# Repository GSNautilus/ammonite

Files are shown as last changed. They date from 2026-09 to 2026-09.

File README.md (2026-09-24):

<p align="center">
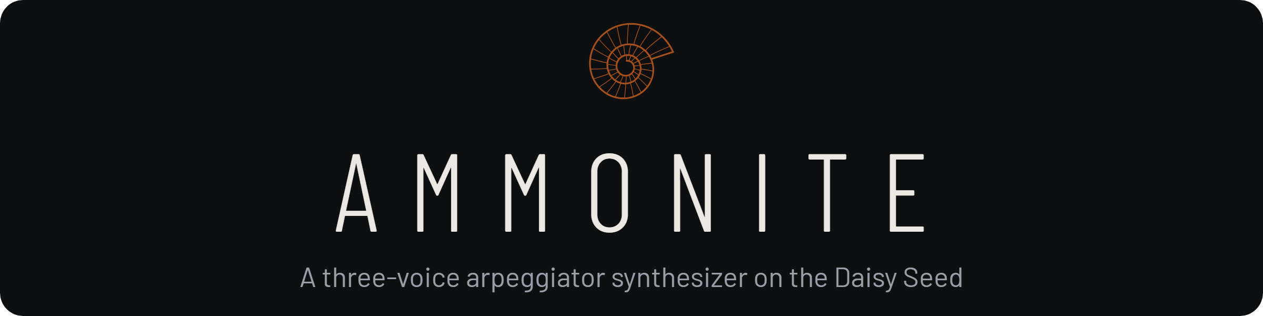
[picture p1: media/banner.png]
Ammonite: a three-voice arpeggiator synthesizer on the Daisy Seed
  
</p>

<p align="center">
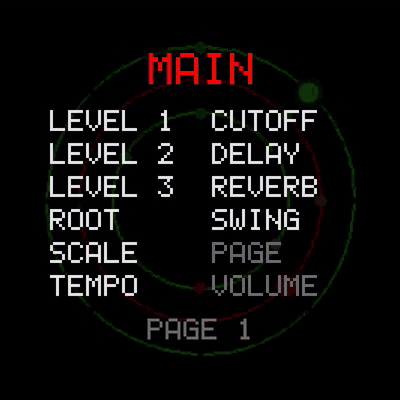
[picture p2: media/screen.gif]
The Ammonite screen playing
  
</p>

<h1 align="center">Ammonite</h1>

<p align="center">
  <b>A three-voice arpeggiator synthesizer on the Daisy Seed</b><br>
  12 knobs &middot; a round screen that draws the music &middot; chords, polyrhythms and echoes in one small box
</p>

<p align="center">
  <a href="https://gsnautilus.github.io/ammonite/"><b>&#9654; Listen: two minutes of Ammonite</b></a><br>
  <a href="https://gsnautilus.github.io/ammonite/#video">Watch the screen play (video with sound)</a> &middot;
  <a href="manual/Ammonite_Manual.pdf">Owner's manual (PDF)</a> &middot;
  <a href="#play-it-in-a-daw-vst3--clap-windows">VST3 / CLAP plugin</a>
</p>

---

Ammonite is three monophonic synth voices, each with its own arpeggiator, envelopes,
filter, five LFOs and stereo echo, all locked to one master clock and one key. You never
pick notes: you pick a key, a chord progression and, for each voice, which notes of the
chord it may play and in what rhythm. Everything it plays is in key, and the three
patterns can run at different lengths and speeds without ever drifting apart.

The round screen shows the three arps as rings: each ring is that voice's real waveform,
cut into its steps, with every note in its own color (the colors follow the circle of
fifths, so a chord has a look as well as a sound).

- **Three voices**, each two detuned oscillators morphing sine / square / saw
- **Three arpeggiators**: 6 modes, 5 note pools, 1-3 octaves, 9 divisions incl. triplets,
  1-16 step patterns, Euclidean density, random note variation, ratchets
- **Harmony**: 10 scales and 10 chord keys, 8 chord progressions, manual chords
- **Per voice**: amp, filter and pitch envelopes, glide, a morphing LP/BP/HP filter,
  15 LFOs in all (pitch, cutoff, amp, pan, shape), a tempo-synced stereo delay
- **Shared**: drive, reverb, swing, four screen views
- **No menus**: nine pages of knobs, one column per voice

## Listen

**[&#9654; Two minutes of Ammonite](https://gsnautilus.github.io/ammonite/)**

That and every clip below play in your browser on the
[listening page](https://gsnautilus.github.io/ammonite/). The recipes are rendered
straight from the synth engine, 40 seconds each; every one is in the
[owner's manual](manual/Ammonite_Manual.pdf), so you can dial it in yourself.

| | |
|---|---|
| [Power-on](https://gsnautilus.github.io/ammonite/#power-on) | what Ammonite plays the moment it has power: three arps in A minor |
| [Slow tide](https://gsnautilus.github.io/ammonite/#tide) | three drones sliding through a progression under a breathing filter |
| [Clockwork](https://gsnautilus.github.io/ammonite/#clockwork) | sixteenth-note patterns of 8, 7 and 5 steps turning against each other |
| [Dub echoes](https://gsnautilus.github.io/ammonite/#dub) | a sparse chord stab into a dark, wobbly ping-pong echo over a sine bass |
| [Late set](https://gsnautilus.github.io/ammonite/#jazz) | a swung ii-V-I in C with a gliding bass |
| [Bells in D](https://gsnautilus.github.io/ammonite/#bells) | Pachelbel's chords played by pitch-swept sine bells |

## The screen

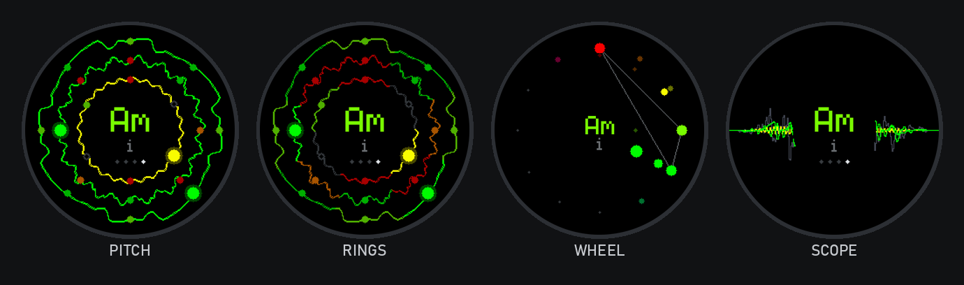
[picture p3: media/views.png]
The four screen views: PITCH, RINGS, WHEEL, SCOPE


Turn a knob and the screen shows what it is and its value; turn the page knob and it
shows what every knob on the new page does:

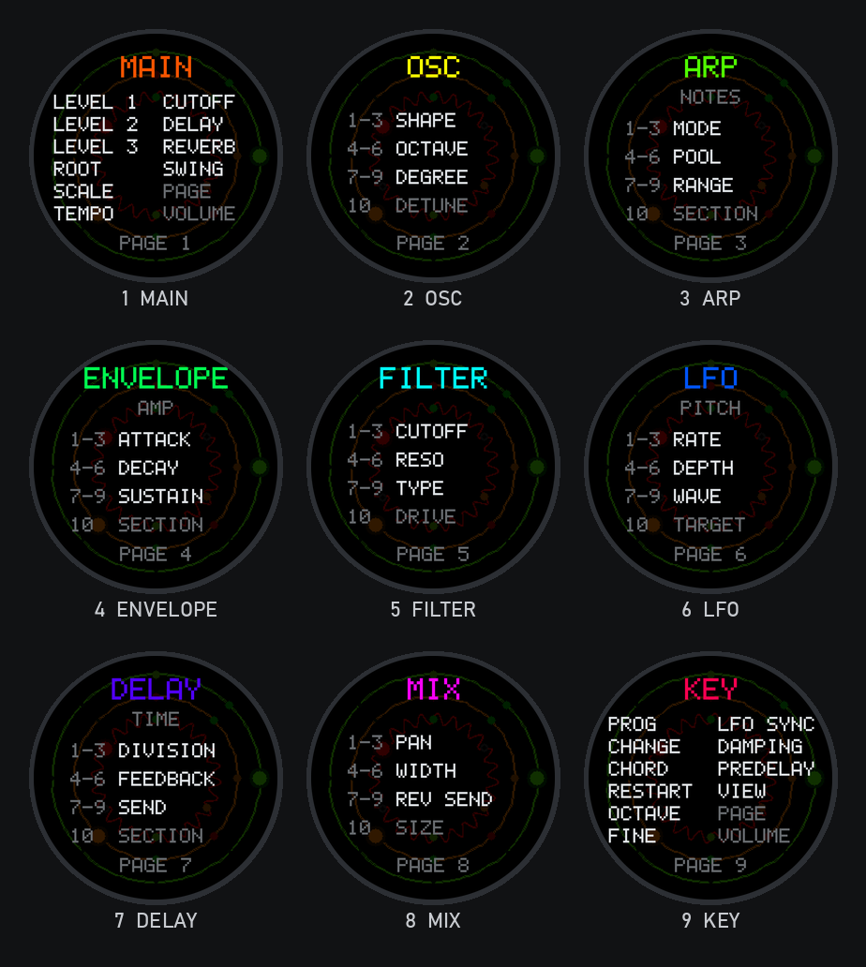
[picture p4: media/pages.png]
The nine page maps


## Hardware

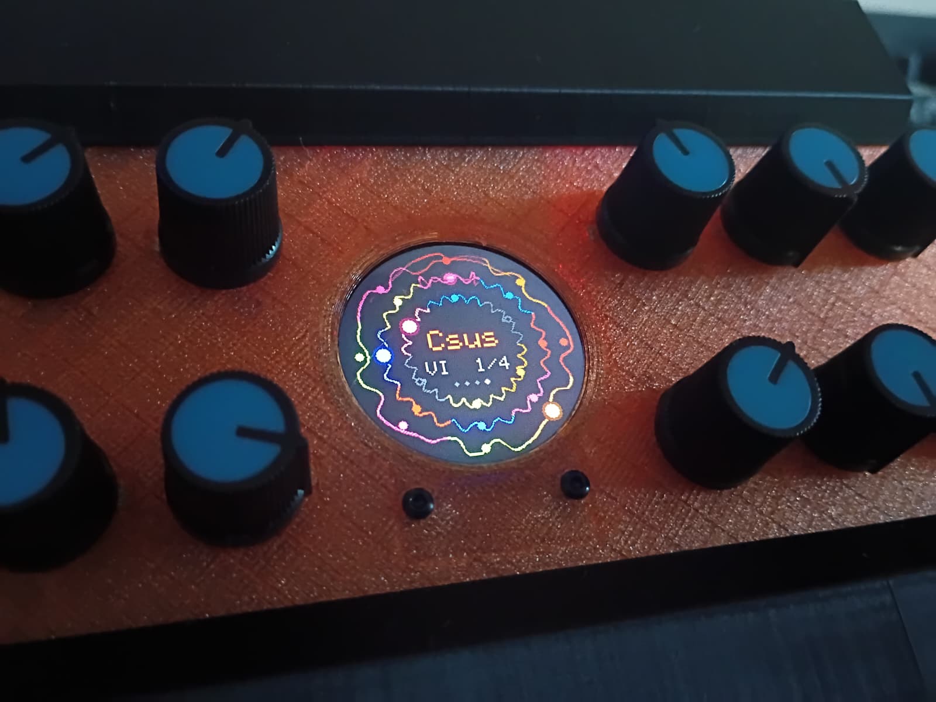
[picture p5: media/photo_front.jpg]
The assembled front panel, the screen playing a Csus chord

<p align="center"><i>The front panel, assembled and playing.</i></p>

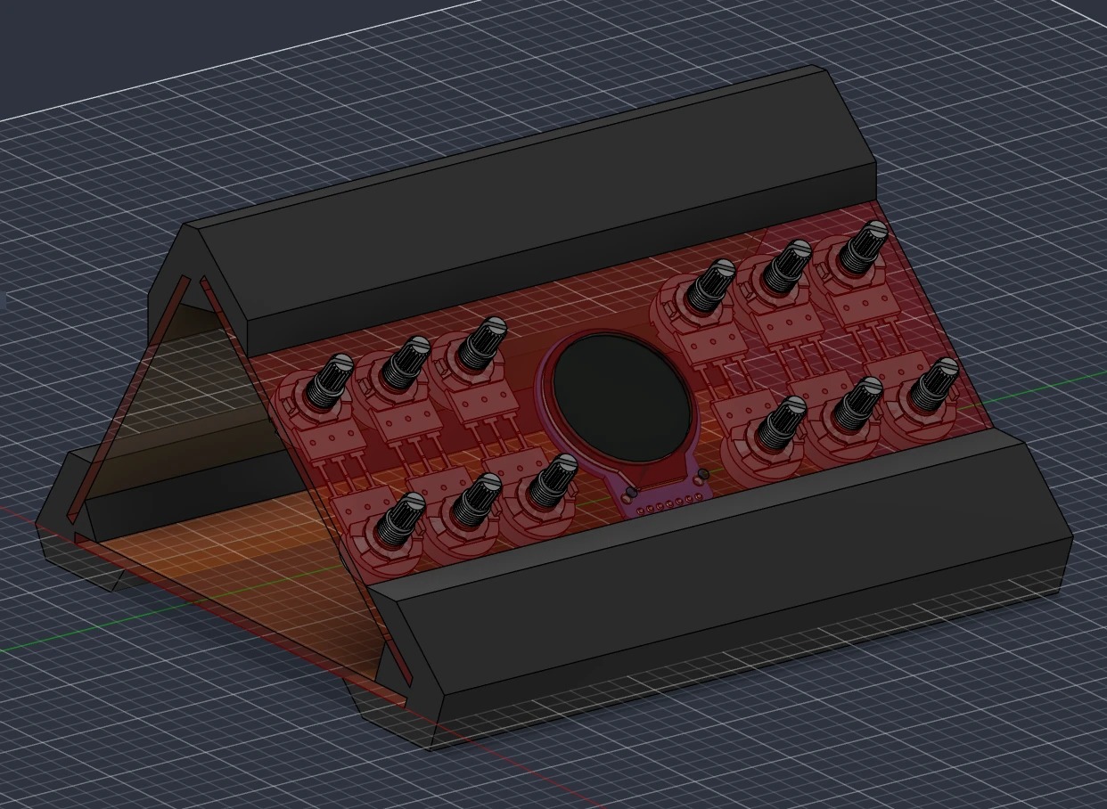
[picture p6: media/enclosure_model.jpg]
The enclosure model: the angled front panel with the twelve pots and the round display

<p align="center"><i>The printed enclosure, version 1.</i></p>

Version 1 of the hardware is simple, and meant to be built with a soldering iron and a
breadboard:

- an Electrosmith **Daisy Seed3**
- a **GC9A01 1.28" round 240x240 display**, 7-pin SPI module
- **12 x WH148 B10K** linear potentiometers (15 mm shaft) with knobs
- a 3.5 mm stereo jack for the output, a breadboard and jumper wire
- a **3D-printed enclosure**: six parts in [`hardware/stl`](hardware/stl)
- USB-C for power and flashing

The wiring is in [`hardware/wiring`](hardware/wiring). A full hardware manual (parts,
printing, assembly, wiring, flashing) is on the [to-do list](#to-do); the enclosure will
keep changing (side panels, a proper home for the jack), so treat this as version 1.

## Getting started

### Flash the firmware

1. Download `ammonite.bin` from the [latest release](../../releases/latest).
2. Put the Seed in bootloader mode: hold **BOOT**, tap **RESET**, release **BOOT**.
3. Open the [Daisy Web Programmer](https://flash.daisy.audio/) in Chrome or Edge, connect,
   choose the file and flash.

### Build from source (Windows)

You need the [Daisy toolchain](https://github.com/electro-smith/DaisyToolchain/releases)
and [Git for Windows](https://gitforwindows.org/). In PowerShell:

```powershell
git clone --recursive https://github.com/GSNautilus/ammonite
cd ammonite
.\ammonite.ps1 libs     # once: builds libDaisy and DaisySP
.\ammonite.ps1 build    # firmware\build\ammonite.bin
.\ammonite.ps1 flash    # build and flash over USB (bootloader mode first)
```

### Try it without hardware

The PC simulator runs the exact same engine and draws the exact same screen, with the
panel's twelve knobs under your mouse. It needs Python 3.11 with the packages in
[`requirements.txt`](requirements.txt):

```powershell
pip install -r requirements.txt
.\simulator.bat
```

(If the right `python` is not on your PATH, set `AMMONITE_PYTHON` to its `python.exe`.)
`.\ammonite.ps1 test` runs the engine's 193 headless checks.

### Play it in a DAW (VST3 / CLAP, Windows)

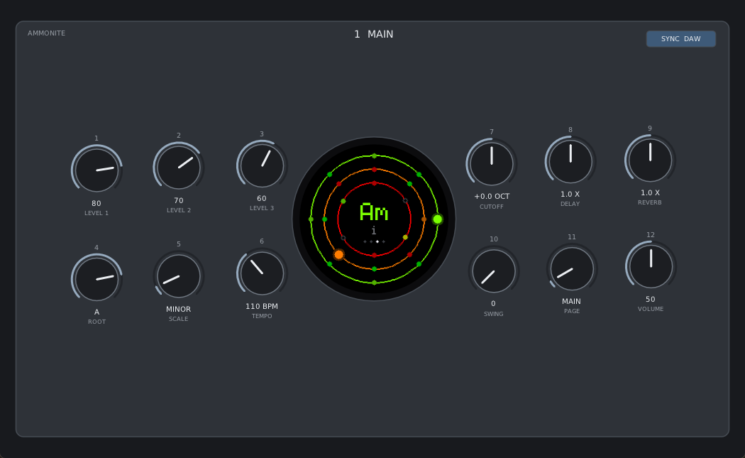
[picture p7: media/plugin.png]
The Ammonite plugin: the panel with its twelve knobs and the round screen


Ammonite is also a plugin for Windows DAWs, with the same engine, panel and screen as
the hardware (its copy of the engine is checked bit for bit against the firmware's).

1. Download `Ammonite-0.2.0-win64.zip` from the [latest release](../../releases/latest)
   and unzip it.
2. Copy the `Ammonite.vst3` folder into `C:\Program Files\Common Files\VST3`, and/or
   `Ammonite.clap` into `C:\Program Files\Common Files\CLAP`.
3. Rescan plugins in your DAW and load Ammonite on an instrument track.

It plays by itself as soon as it is loaded. **SYNC DAW** (the default) follows the
DAW's tempo and bars: patterns and chord progressions line up with the song and follow
the playhead; **SYNC FREE** runs on its own TEMPO knob like the hardware. Every knob of
every page is an automatable parameter, saved with the project; turning a knob on the
panel records automation. Any sample rate from 44.1 to 192 kHz.

Tested in FL Studio 2025. Good to know: Ammonite's bars are always 4/4, and it ignores
MIDI notes, so a DAW's channel mute (which mutes by holding back notes) does not
silence it: mute or turn down its mixer track instead.

To build it yourself you need the Visual Studio 2022 Build Tools (the C++ workload, with
CMake). In PowerShell, from the repository:

```powershell
.\plugin\plugin.ps1 build     # plugin\build\cmake\bin\Ammonite.vst3 and Ammonite.clap
.\plugin\plugin.ps1 install   # copies both into the system plugin folders (run as administrator)
.\plugin\plugin.ps1 test      # the engine and plugin tests
```

## To do

- [ ] **Hardware manual**: parts list, printing, assembly, wiring and flashing, with photos
      of the build
- [ ] **Enclosure v2**: back and side panels with room for the jack and USB
- [ ] **Measure CPU load on the Seed** with every effect running
- [x] **VST3 / CLAP plugin** for Windows, synced to the DAW's tempo (0.2.0)

## Repository

| Folder | |
|---|---|
| `core/` | the synth engine: portable C++14, no hardware code. Everything musical lives here |
| `firmware/` | the thin Daisy shell: knobs in, audio and screen out |
| `sim/` | the PC simulator (Python + the engine as a DLL) |
| `tests/` | headless tests that play the engine and measure what comes out |
| `plugin/` | the VST3 / CLAP plugin (DPF): its copy of the engine, the panel UI, its tests |
| `manual/` | the owner's manual: its screen captures are made by driving the engine |
| `hardware/` | enclosure STLs and wiring diagrams |
| `media/` | everything on this page, rendered by `media/make_media.py` |
| `docs/ENGINE_PLAN.md` | the design and build notes |
| `docs/VST_PLAN.md` | how the plugin was built, decisions and limits |
| `lib/` | libDaisy and DaisySP (git submodules; `plugin/lib/DPF` for the plugin) |

## License

Ammonite is released under the [MIT license](LICENSE).

It builds on Electrosmith's [libDaisy](https://github.com/electro-smith/libDaisy) and
[DaisySP](https://github.com/electro-smith/DaisySP) (MIT). The reverb, `ReverbSc`, comes from
[DaisySP-LGPL](https://github.com/electro-smith/DaisySP-LGPL) and is licensed under the
**LGPL-2.1**; it is linked into the firmware and the simulator, and its full source is
included here as a submodule. The plugin links its own copy of it (`plugin/engine`, with
a larger buffer for high sample rates, source included) and is built with the
[DISTRHO Plugin Framework](https://github.com/DISTRHO/DPF) (ISC).

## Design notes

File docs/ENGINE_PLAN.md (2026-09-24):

# Ammonite — Engine Build Plan

Living design and build notes for Ammonite (developed as `synth_arp`, named
Ammonite on 2026-09-24). Designed in discussion 2026-09-23. It started as a
copy of an earlier drone synth, whose pieces (MorphOsc, envelope, delay loop,
reverb wrapper, pickup) it reuses.

> Paths: this repository was split out of a larger Daisy workspace on
> 2026-09-24. The build history below keeps the old names (`synth_arp\core` is
> now `core\`, `MyProjects_arp` is `firmware\`, `synth_arp\sim` is `sim\`,
> the map file is `firmwareuildmmonite.map`).

## What exists (2026-09-24)

| Piece | Path | Status |
|---|---|---|
| Portable core | `core\` | **build steps 1-7 done** (2026-09-23): all 9 pages and sub-pages, three oscillators with key + chord degree, filters, mix, reverb; master clock, three arps, amp envelopes; chord progression; filter / pitch envelopes + glide; 15 LFOs; per-osc delays; RINGS / PITCH / WHEEL / SCOPE views; fast display SPI (confirmed on hardware). CPU on the Seed still to measure |
| PC simulator | `sim\panel_sim.py` + `synthcore.dll` (`simulator.bat`) | runs; top label = page (and sub-page), captions = function + osc |
| Firmware shell | `firmware\` (`TARGET = ammonite`, builds from `core\`, libs from the `lib\` submodules) | `make` clean, no warnings: flash 90.3 %, SDRAM 7.4 MB (6 delay lines already allocated), `audio.o` at 0x30000000 |
| Tests | `tests\` | `arpsynth.py` helpers, `test_panel.py` (49 checks), `test_voices.py` (22), `test_arp.py` (31), `test_prog.py` (40), `test_env.py` (16), `test_lfo.py` (16), `test_delay.py` (16), `test_screen.py` (12), all pass (193 checks) |
| Hardware | `hardware\stl\`, `hardware\wiring\` | enclosure v1 (six parts), wiring diagrams |
| Manual | `manual\` | owner's manual, A4 PDF. `capture.py` drives the DLL headless (reuses `panel_sim.draw_panel`) for every screen / panel image and plays `recipes.py` through the panel into `recipes.json`; `build.py` prints `ammonite.html` twice with headless Edge (contents page numbers). `msedge.exe` returns before the PDF exists: `build.py` waits for it. Re-run after any change to names, ranges or defaults |
| README media | `media\` | `make_media.py` renders the demo video, GIF, recipe MP3s and images from the engine (and the STLs) |

**The architecture law: every engine feature goes in `core\` only.**
The shells (panel_sim.py, synth_main.cpp) stay thin: controls in, audio and
framebuffer out.

### Workflows (PowerShell, from the repository root)

- Simulator: `.\simulator.bat` (or `.mmonite.ps1 sim`)
- Libraries, once: `.mmonite.ps1 libs`
- Firmware build: `.mmonite.ps1 build`
- Flash: `.mmonite.ps1 flash` (bootloader: hold BOOT, tap RESET, release BOOT)
- Firmware check from Git Bash: `cd firmware && make`
- DLL build: `simuild_dll.ps1` (add new DaisySP .cpp files to its `$sources`)
- Headless screenshot: `SIM_SHOT=<png>` + `SDL_VIDEODRIVER=dummy` on panel_sim.py
- Tests: `.mmonite.ps1 test`, or `python tests	est_x.py`
  (env `SYNTH_DLL=<path>` points them at another DLL, e.g. one built elsewhere
  while a running simulator holds `sim\synthcore.dll` open)
- Python: `$env:AMMONITE_PYTHON` if set, else `python` (packages in `requirements.txt`)
- Manual: `.mmonite.ps1 manual`; README media: `python media\make_media.py`

---

## The instrument (user-decided 2026-09-23)

An **arpeggiator box built on three independent monophonic oscillators**
(OSC 1-3). Each oscillator has its own shape, pitch, arp, envelopes, filter,
LFOs, delay and mix. A shared key (ROOT + SCALE) and an optional chord
PROGRESSION tie them together; one master clock (TEMPO, SWING) drives all
three arps and the chord changes. An oscillator with its arp OFF drones, so
the old drone box is one setting of this one.

Dropped from the reference: CHAOS, SHIMMER (all pitch shifters), TEXTURE
(sub, noise, ensemble), the FREE / NOTES tuning modes.

### Signal flow

```
per OSC n (x3, mono):
  2 detuned MorphOsc (SHAPE, DETUNE)            pitch = key note + PITCH env + LFO + glide
  -> drive (FILTER page DRIVE, shared amount), per oscillator
  -> SVF, LP -> BP -> HP morph (CUTOFF, RESO, TYPE; FILTER env, LFO, master CUTOFF)
     (two SVFs per osc, one per oscillator, so WIDTH can pan them apart)
  -> amp envelope (A, D, S; release = D) x LEVEL x AMP LFO
  -> scope capture (post filter + env, pre pan)  -> screen ring n
  -> pan (PAN + PAN LFO), WIDTH spreads the osc's two oscillators L/R
  -> dry sum
  -> own stereo delay (DIVISION, FEEDBACK, SEND x master DELAY, TONE, WOBBLE, WIDTH)
  -> reverb send = (dry + delay return) x REV SEND x master REVERB
sum of dry + 3 delay returns + ReverbSc (SIZE, DAMPING, PREDELAY)
  -> soft limiter -> VOLUME -> out L/R
```

Modulation per oscillator: 5 LFOs (one per target: PITCH, CUTOFF, AMP, PAN,
SHAPE), a FILTER envelope and a PITCH envelope, all computed on the
**control tick, every 16 samples** (0.33 ms; changed from "once per block"
in step 4, since the sim's 5 ms blocks are too coarse for fast envelopes).
The amp envelope stays **per sample** (steps would click).

### Clock (one master, never three timers)

- One beat position (`beat_`, quarter notes since Init) advances by TEMPO
  every block, so a tempo change never jumps it; a bar is 4 beats.
- Each oscillator's step index is derived from that position and its
  DIVISION, with SWING applied per division (even steps stretched up to a
  third, odd ones shrunk). Polyrhythms therefore stay locked forever.
- Events are sample-accurate inside the block (onset on its sample, gates
  and ratchet hits counted in samples).
- Chord changes and RESTART happen on bar lines of the same counter.

### Harmony

- **ROOT** = the key's tonic, C..B. **SCALE** = one list of 10 scales then
  10 chords (the reference's `kScaleMask` / `kChordMask`, TYPE knob folded in).
- The **current chord** is a scale degree: from the PROGRESSION when PROG is
  on, else from KEY page CHORD (manual, default I).
- Each oscillator's note pool: start at (current chord degree + the osc's
  DEGREE), build the POOL type from the scale (KEY = every scale note,
  TRIAD / 7TH = stacked diatonic thirds, FIFTHS = root + in-key fifth,
  ROOT = octaves only), repeat over RANGE octaves, place at base octave 2
  + the osc's OCTAVE + master OCTAVE.
- **Chord keys** (SCALE set to a chord): POOL KEY = the chord's tones; the
  progression moves the chord's root along its parent scale (natural minor
  for MIN, MIN7, DIM; major otherwise) and keeps the chord quality
  (parallel chords). *Tune by ear once it runs.*
- MODE OFF: the oscillator drones on its pool's first note (its DEGREE on
  the current chord) and follows chord changes with its GLIDE.

---

## Panel

### Conventions

- **Knob 11 = PAGE selector** (stepped, 9 pages, `StepWithHyst`),
  **knob 12 = VOLUME** on every page. Unchanged from the reference.
- **Column = oscillator** on every column page:

  ```
  LEFT GROUP              RIGHT GROUP
  [1 ] [2 ] [3 ]          [7 ] [8 ] [9 ]     row A (1-3), row C (7-9)
  [4 ] [5 ] [6 ]          [10] [PAGE][VOL]   row B (4-6), knob 10
  osc1 osc2 osc3          osc1 osc2 osc3
  ```

  Row A, row B and row C each hold one function for all three oscillators.
- **Knob 10** is either one **shared** function, or the **sub-page
  selector** on ARP, ENVELOPE, LFO and DELAY. Selecting a sub-page never
  changes the sound.
- **Pickup:** every (page, sub-page, knob) slot keeps its own value.
  Changing page **or sub-page** re-arms pickup on knobs 1-9 exactly like a
  page change in the reference (`kPickup` 0.02). Knob 10 as a selector is
  picked up the same way; a jump in the selection is harmless because
  selecting is silent.
- **Per-oscillator functions** hold three values (`params_[func][osc]`), so
  a page row is written once and expanded to the three columns (see "How the
  code holds it"). Stepped values are computed on the audio thread with
  `StepWithHyst`, the screen only reads them (reference rule).
- Names are **<= 8 characters**. The readout shows the function name with
  the sub-page and `OSC n` above it (nothing for a global function).
- MAIN and KEY are **global pages** (no columns): ten independent functions.

### How the code holds it (built in step 1)

- **`enum Func` + `kFuncs[]`** (`synth_core.cpp`): every function once, with
  its name, whether it is per-osc, its step count and step names (or a
  numeric base / sign), and defaults per osc. Values live in
  `params_[func][osc]` (atomic), `smooth_[func][osc]` (audio thread) and
  `step_[func][osc]` (stepped functions, hysteresis on the audio thread; the
  screen only reads them). Global functions use osc 0.
- **`kPages[]`**: per page and sub-page, the (func, osc) each of pots 0-8
  drives (packed `func | osc << 8`; `COLS(a, b, c)` writes a column page's
  three rows), plus knob 10 = a function or `kSubSel`.
- There is no separate slot store: every slot is a distinct (func, osc), so
  a slot's value *is* its param. Pickup state is `potRef_ / picked_`; the
  sub-page per page is `sub_[page]` with its selector reading `subSel_[page]`.
- **Adding a function:** a `Func` entry (the enum and `kFuncs` must stay in
  the same order; `tests/arpsynth.py FUNCS` mirrors it), use it in
  `ProcessAudio`, place it in `kPages`, add a `GetValueText` case if percent
  is not the right unit.
- Core API: `SetPot / GetPot`, `GetPage / GetPageName / GetNumSubs / GetSub /
  GetSubName`, `GetSlotValue / GetSlotName / GetSlotOsc / GetValueText`,
  test hooks `SetEngineParam(func, osc, v)` and `GetOscNote(osc)`. The DLL
  exports them as `synth_*` (`api.cpp`).

### Pages

Ranges and curves follow the reference wherever a function is reused.

**Defaults = a simple start (user 2026-09-23):** power-on is three plain
oscillators and their arps with every effect and modulation off: delay
SENDs, REV SENDs, all LFO DEPTHs, FILTER and PITCH env AMOUNTs, DRIVE and
MIX WIDTH at 0 (the masters MAIN DELAY / REVERB stay at 1x, so raising a
send works at once). On the Seed, the boot page takes its knobs' physical
positions; that is why "off" lives in the per-osc functions on the other
pages, not in the MAIN masters. Checked in `test_voices.py`: nothing rings
on once the notes stop.

**1 MAIN** (global, the power-on performance page)

| Knob | Function | Notes |
|---|---|---|
| 1-3 | LEVEL 1-3 | osc levels, audio taper (p^2). Defaults 0.8 / 0.7 / 0.6 |
| 4 | ROOT | key tonic, stepped 12, C..B (default A) |
| 5 | SCALE | stepped 20: MAJOR MINOR DORIAN PHRYGIAN LYDIAN MIXO "HARM MIN" PENTA "PENTA MI" BLUES, then MAJ MIN SUS2 SUS4 MAJ7 MIN7 DOM7 DIM AUG ADD9 (default MINOR) |
| 6 | TEMPO | 40-240 BPM (default 110) |
| 7 | CUTOFF | master: +-3 octaves on all three cutoffs, centre = as set |
| 8 | DELAY | master: 0-2x all three delay SENDs, centre = as set |
| 9 | REVERB | master: 0-2x all three REV SENDs, centre = as set |
| 10 | SWING | 0-1 (reference behaviour) |

**2 OSC** (columns)

| Row | Function | Notes |
|---|---|---|
| A | SHAPE | MorphOsc: 0 sine, 0.5 square, 1 PolyBLEP saw. Defaults 1 / 0.5 / 0.3 |
| B | OCTAVE | stepped -1..+3 above base octave 2. Defaults 0 / +1 / +2 |
| C | DEGREE | stepped 0..7 scale steps above the current chord root. Defaults 0 / 2 / 4 (all arps OFF = the chord's triad) |
| 10 | DETUNE | shared, 0-20 cents between each osc's two oscillators |

**3 ARP** (columns, knob 10 = sub-page)

| Sub | Row A | Row B | Row C |
|---|---|---|---|
| NOTES | MODE: stepped OFF, LOOP (retrigger, no pitch change), UP, DOWN, UP-DN, RANDOM | POOL: stepped KEY, TRIAD, 7TH, FIFTHS, ROOT | RANGE: stepped 1-3 octaves |
| RHYTHM | DIVISION: stepped 1/1, 1/2, 1/4, 1/4T, 1/8, 1/8T, 1/16, 1/16T, 1/32 | LENGTH: stepped 1-16 steps (the pattern restarts after LENGTH steps: polymeter) | GATE: 0.05-1 of the step |
| CHANCE | DENSITY: how many of the LENGTH steps play, **spread evenly (Euclidean)**, 1 = every step. Deterministic, so a pattern repeats | VARY: chance a played step takes a random pool note | RATCHET: chance a played step splits into 2-4 fast repeats |

Defaults: osc 1 UP, FIFTHS, 1 oct, 1/4, LENGTH 8; osc 2 UP-DN, TRIAD,
2 oct, 1/8, LENGTH 8; osc 3 RANDOM, KEY, 2 oct, 1/16, LENGTH 6, DENSITY
0.6. VARY and RATCHET 0.

**4 ENVELOPE** (columns, knob 10 = sub-page)

| Sub | Row A | Row B | Row C |
|---|---|---|---|
| AMP | ATTACK 1 ms-4 s | DECAY 5 ms-4 s, **also the release time** | SUSTAIN 0-1 |
| FILTER | ATTACK 1 ms-4 s | DECAY 5 ms-4 s (AD, retriggered per note) | AMOUNT bipolar +-4 octaves of CUTOFF |
| PITCH | AMOUNT bipolar +-12 semitones | DECAY 5 ms-1 s (starts at AMOUNT, falls to 0) | GLIDE 0-1 s portamento between arp notes |

Release follows DECAY (user-decided): SUSTAIN 0 = pluck, gate irrelevant;
SUSTAIN 1 = holds for GATE, then fades over DECAY. A new note restarts from
the current level (no click). MODE OFF bypasses the amp envelope (rises at
ATTACK, holds). Defaults: plucks, SUSTAIN 0.4 / 0 / 0, DECAY 400 / 250 /
180 ms, FILTER AMOUNT 0 (was +1.5 oct), PITCH AMOUNT 0, GLIDE 0 / 0 / 0.

**5 FILTER** (columns)

| Row | Function | Notes |
|---|---|---|
| A | CUTOFF | 80 Hz-12 kHz exp |
| B | RESO | 0-0.85 |
| C | TYPE | continuous LP (0) -> BP (0.5) -> HP (1), crossfade of the SVF outputs |
| 10 | DRIVE | shared, pre-filter tanh 1-8x, level-compensated (default 0: clean) |

**6 LFO** (columns, knob 10 = sub-page = target)

Sub-pages PITCH, CUTOFF, AMP, PAN, SHAPE; every one has the same rows, so
each oscillator has **one independent LFO per target** (15 total).

| Row | Function | Notes |
|---|---|---|
| A | RATE | 0.02-20 Hz exp; with LFO SYNC = TEMPO, stepped 4 bars .. 1/16 of the master clock |
| B | DEPTH | 0-1. Full scale: PITCH +-1 semitone, CUTOFF +-3 oct, AMP 100 % dip, PAN full L-R, SHAPE +-0.5 |
| C | WAVE | stepped SINE, TRI, SAW, SQUARE, S&H, DRIFT (smooth random) |

Defaults: depth 0 everywhere (CUTOFF was 0.15 until the simple-start
defaults below; its slow unrelated rates 0.09 / 0.13 / 0.17 Hz remain).

**7 DELAY** (columns, knob 10 = sub-page) — **one stereo delay per oscillator**

| Sub | Row A | Row B | Row C |
|---|---|---|---|
| TIME | DIVISION: stepped 1/32 .. 1/1 incl. T and dotted (reference list minus OFF) | FEEDBACK: 0-1 on the reference's stretched curve | SEND 0-1 |
| COLOR | TONE: loop lowpass 500 Hz-12 kHz | WOBBLE: tape wander 0-3 ms | WIDTH: mono .. ping-pong |

Loop topology, send level and makeup gain from the reference's delay rework
(half-level loop, 20 Hz highpass). Buffers: 6 lines of 6 s (a bar at
40 BPM), 1.15 MB each, SDRAM on the Seed, lent through `synth::Buffers`.
Defaults: 1/8. / 1/4 / 1/8T, feedback 0.4, **send 0** (was 0.2 / 0.35 / 0.3).

**8 MIX** (columns)

| Row | Function | Notes |
|---|---|---|
| A | PAN | defaults 0.5 / 0.3 / 0.7 |
| B | WIDTH | the osc's two oscillators spread L/R, 0 = mono (default 0, was 0.3) |
| C | REV SEND | 0-1 (default 0) |
| 10 | SIZE | reverb size (reference SIZE) |

**9 KEY** (global)

| Knob | Function | Notes |
|---|---|---|
| 1 | PROG | stepped: OFF, POP 1-5-6-4, 50S 1-6-4-5, SAD 6-4-1-5, EPIC 1-6-3-7, JAZZ 2-5-1-1, VAMP 1-4, CANON 1-5-6-3-4-1-4-5, FALL 1-7-6-5 (scale degrees, so each works in any ROOT and SCALE) |
| 2 | CHANGE | stepped 1/2, 1, 2, 4 bars per chord |
| 3 | CHORD | manual chord degree I..VII while PROG is OFF |
| 4 | RESTART | stepped FREE, BAR, CHORD: when all patterns jump back to step 1 |
| 5 | OCTAVE | master -2..+2 |
| 6 | FINE | +-50 cents |
| 7 | LFO SYNC | FREE / TEMPO |
| 8 | DAMPING | reverb (reference) |
| 9 | PREDELAY | reverb (reference) |
| 10 | VIEW | stepped RINGS, PITCH, WHEEL, SCOPE (PITCH added 2026-09-23 on user request, the default since 2026-09-24) |

The progression changes chord on bar lines; a step already sounding
finishes, the next step uses the new chord. ROOT still transposes the whole
progression while it runs.

---

## Screen (user-decided 2026-09-23)

### Color: pitch class in circle-of-fifths order

`hue = ((pc * 7) mod 12) / 12`, pc = pitch class with C = 0. Notes a fifth
apart get neighbouring hues, so a chord's notes cluster (Am = green to
yellow, F = magenta to red, G = orange to teal) and each chord of a
progression gets its own color mood. Replaces the reference's register-based
`PitchColor`.

### VIEW RINGS

- Three concentric rings, **outer = OSC 1** (r 100), OSC 2 (r 78),
  OSC 3 (r 56), each divided into LENGTH arcs starting at 12 o'clock.
- **Each ring is drawn as that oscillator's waveform**, subtly: the captured
  signal (post filter and envelope, pre pan), read phase-locked to the osc's
  own phase so it stands still. Cycles around the ring follow the note's
  frequency (an octave up = twice as many); height follows the envelope
  (up to +-7 px at full level, user-approved height), so rings jump on each
  note and settle.
- **Each arc takes the color of its step's note** (user choice): the current
  step's arc bright (full, 1.6 px), others at ~40 %, skipped steps
  (DENSITY) dark grey.
- Step dots on the ring: current step r 7 with a faint halo, others r 4.5
  at 40 %, skipped = hollow grey, ratchet = split dot.
- Centre: current chord name (e.g. `Am`) large in its root's hue, below it
  the degree numeral and progression position (`vi  3/4`), then 4 beat dots.
- Mockups of rings, wheel and both waveform variants were shown in the
  design session (2026-09-23).

### VIEW PITCH (user request 2026-09-23; the default since 2026-09-24)

The RINGS view with each oscillator's whole wave in **one color**: the
fifths hue of the note that oscillator is on (`oscNote_`), changing as the
arp moves, instead of one color per step arc. The step dots keep their
per-step colors, so the pattern stays readable. `DrawRings(fb, alpha,
oneHue)`.

### VIEW WHEEL

Pitch classes around the circle in fifths order (C at the top); radius =
octave (low inside). Scale notes marked in their hue, current chord's tones
larger and joined into a polygon (its shape shows the chord quality);
each playing note a bright disc with its osc number beside it, previous
notes as a short fading trail. Chord name in the centre.

### VIEW SCOPE

The reference's scope: three overlaid traces, now colored by the fifths hue.

### Overlays (every view)

- **Readout** when a knob moves: name, `OSC n` / `SHARED`, gauge, value
  text; fades after ~2.5 s (reference timing).
- **Page map** when PAGE turns. Column pages list their rows, which reads
  better on a round screen than a 3x3 name grid:
  `1-3 SHAPE / 4-6 OCTAVE / 7-9 DEGREE / 10 DETUNE`. Global pages (MAIN,
  KEY) keep the reference's two-column map.
- **Sub map** when knob 10 turns on a sub-page: the page name, every
  sub-page listed with the current one highlighted and a dot on the ones in
  use (LFO: any DEPTH > 0), then the chosen sub's rows as in the page map.
- Font gains the lowercase glyphs chord names and numerals need
  (`m`, `i`, `v`, `d`, `s`, plus `#` which exists).

### Frame rate

Moving waveforms touch most of the screen, so it stays a full-frame push
(~74 ms, ~13 fps, like the reference scope). Later, with the user at the
hardware: try the SPI prescaler one step faster (~25 MHz) and keep it only
if the panel shows no glitches.

---

## Constraints & landmines (each of these cost real debugging once)

- **C++14 only** in core (firmware toolchain default). No C++17 features.
- Framebuffer stays in **panel byte order** (`canvas.h Color()` handles it);
  the sim un-swaps. Never "fix" the swap.
- Params cross threads: keep the `std::atomic<float>` array + per-block
  smoothing pattern already in `synth_core.cpp`.
- Audio API is interleaved stereo float, `ProcessAudio(out, nframes)`; the
  Daisy callback passes `size/2` frames. Sim block = 256, firmware block = 48.
- **Big DSP buffers**: `ReverbSc` and long `DelayLine`s are hundreds of KB.
  PC: fine as statics inside the DLL. Firmware: they overflow main RAM — the
  established pattern is the shell owning placement: declare
  `static daisysp::ReverbSc DSY_SDRAM_BSS verb;` (and SDRAM delay buffers) in
  `synth_main.cpp` and pass references into `synth::Init(...)` through
  `synth::Buffers`. Add a field there, in `api.cpp` and in `synth_main.cpp`
  together. Verify firmware RAM in the `make` output memory table after
  adding each effect.
- **NEVER put a big buffer in `DMA_BUFFER_MEM_SECTION`.** That section is
  the start of RAM_D2 and libDaisy's MPU makes only its first 32 KB
  non-cacheable. The 115 KB display framebuffer placed there (copied from
  04_hue) pushed libDaisy's audio DMA buffers (`audio.o .sram1_bss`) past
  32 KB into cacheable RAM -> the codec played stale-cache garbage: loud,
  garbled, even for a pure sine, knobs still "doing something". Screen fine,
  ADC fine, CPU 38 %, SDRAM OK. Found via `build/synth.map` (2026-09-21).
  The display uses blocking SPI, so the framebuffer lives in plain `.bss`.
  Check the map after adding any large static: `audio.o` must be at
  0x30000000..0x30007FFF (`build/synth_arp.map` here).
- **SEED3 GROUNDS ARE NOT BONDED.** AGND (pin 20) and DGND (pin 40) must be
  jumpered together externally (Seed3 datasheet v2.1 p.12, fig 1.5). Without
  it the ADC reference floats: all 12 channels read ~100 with random dips to
  70-80, a grounded pin still reads 100, even the DAC loopback self-test
  fails. Cost a full evening on 2026-09-21.
- **Wiring (all 12 pots confirmed on hardware 2026-09-21).** Seed3 physical
  pins: pin 1 = square pad beside USB-C, 1–20 up one side, 21–40 down the
  other. Knob k (panel order) -> ADC A(k-1): A0..A10 on pins 22..32, A11 on
  pin **35** (33/34 are D26/D27, no ADC). Pot ends: +3V3A pin 21 and AGND
  pin 20. Bottom rows are mounted upside down: firmware inverts pots 4-6 and
  10-12 (`kPotInvert` in `synth_main.cpp`). Display: VCC 38 (3V3D), GND 40,
  SCL 9, SDA 11, DC 7, CS 8, RST 6. Audio: OUT L 18, OUT R 19, AGND 20.
  VIN (39) is input-only and dead on USB power - never use it as a supply.
- **Flash is the tight budget** (128 KB internal). Watch the `make` table
  after every step and `arm-none-eabi-nm --size-sort -S -C
  build/synth_arp.elf | tail` for the big symbols. Paid for once: the
  compiler inlined the `canvas.h` text helpers into every call site
  (RenderScreen 7.7 KB) - they are `SYNTHUI_NOINLINE` now; and one
  `fmod(double)` pulled in ~0.8 KB of libm (use `x - floor(x / m) * m`).
  Since step 7 the whole screen section of `synth_core.cpp` is compiled
  `-Os` via `#pragma GCC push_options / optimize("Os")` (GCC only; clang
  in the sim ignores it): -5 KB. Keep new UI code inside that section and
  audio code outside it.
- **Zig floods the console with libc++ `-Wnullability-completeness` warnings**
  (~2 min) on a cache miss: zig building its bundled C++ runtime, not our
  code. Once per environment; the next build is ~1 s. Do not kill it.
- **DLL build fails with `lld-link: could not open '...\zig\o\<hash>\*.obj'`**:
  a zig process was killed mid-build. `build_dll.ps1` detects the message and
  retries once with a cache nonce define.
- **DLL build fails with "Permission denied"** when a `panel_sim.py` process
  is still alive. `synth.bat` closes it; otherwise find it with
  `Get-CimInstance Win32_Process | ? CommandLine -like '*panel_sim*'`.
- Flashing is the user's move. Never claim hardware behavior verified
  unless the user reports it.

### Measurement traps (from the reference tests)

- Exact unison with DETUNE 0 cancels the fundamental; use a little detune.
- A sine gated every step has sidebands; use GATE 1 / SUSTAIN 1 for spectra.
- A decorrelated stereo tail beats if L+R is summed first; measure per channel.
- Every helper that switches pages (and now sub-pages) must switch back.
- Onset-based pitch reads misread ~1 frame in 20; count a pitch only when
  it appears twice.
- `setp(pot, v)` must move a pot first if it already sits at `v` (pickup).
- DETUNE splits each osc into two spectral peaks (+-8..10 cents at the
  default): pitch reads need DETUNE 0 (the two start phases are a quarter
  cycle apart, so DETUNE 0 does not cancel).
- Params smooth over 20 ms. Through the panel that is right, but in a test
  the default sends and levels leak ~50 ms into the reverb after Init, and
  the tank rings on at about -33 dB for seconds. So `SetEngineParam` (the
  test hook) also sets the smoothed value: engine-set values apply at once
  and tests can expect digital silence.
- Onset times: the first sample above 30 % of the peak lags the true onset
  by up to half a period plus the attack; measure timing on a high note
  (A5) with a 1 ms attack. Judge grid lock by drift, not by max error.

---

## Build order (each step ends runnable in the sim, tested, firmware `make` clean)

0. **DONE — Setup** (2026-09-23): `synth\` copied to `synth_arp\`,
   `05_synth` to `06_arp` (Makefile paths + TARGET), sim title, .gitignore.
   DLL and firmware both build from the copy (flash 90.1 %).
1. **DONE — Framework + three drone oscillators** (2026-09-23). The core
   was rewritten around `Func` / `kPages` (see "How the code holds it"):
   all 9 pages and 14 sub-pages are placed, every function stores its value
   and shows its value text; CHAOS, SHIMMER (all GrainShifters), TEXTURE and
   the old tests are gone. Sounding: MAIN (LEVEL x3, ROOT, SCALE with the 10
   chords, master CUTOFF and REVERB), OSC, FILTER (with DRIVE and TYPE),
   MIX (PAN, WIDTH, REV SEND, SIZE), and from KEY: CHORD (manual), OCTAVE,
   FINE, DAMPING, PREDELAY (pulled forward from step 2 / 6). The reverb is a
   send / return now (return 0.5 at send 1). `Buffers` already carries the 6
   delay lines (step 6 only has to use them). The screen still shows the
   reference scope, colored by the fifths hue; page map (rows) and sub map
   (rows + sub-page dots) are new. Verified (`test_panel.py`,
   `test_voices.py`): page / sub-page pickup, columns only touch their osc,
   default notes A2 C4 E5 measured within 5 cents, ROOT / SCALE / CHORD
   I-IV-V-VII, a MIN7 chord key and its IV, KEY OCTAVE + FINE measured, HP
   at 1.2 kHz cuts 110 Hz by 37 dB, master CUTOFF -3 oct moves the centroid
   1140 -> 289 Hz, PAN / WIDTH, reverb tail. Firmware `make` clean.
   Hardware not yet heard.
2. **DONE — Clock + ARP + AMP envelope** (2026-09-23). `beat_` (double,
   quarter notes since Init) advances by TEMPO each block; an osc's step
   index = `StepIndex(beat, DIVISION, swing)` (even steps d(1+s), odd
   d(1-s), s = SWING / 3), so the three grids share one origin and cannot
   drift. A step starting inside a block is found by comparing the index at
   the block's last sample with `lastStep`, and lands on its exact sample.
   Pattern position = step index mod LENGTH; DENSITY hits = round(DENSITY x
   LENGTH), step plays if `(pos * hits) % LENGTH < hits` (Euclidean, starts
   on a hit; readout "3/8"). Pool (`BuildPool`): POOL type from DEGREE on
   the current chord over RANGE octaves; FIFTHS uses `KeyFifth` (key note
   nearest a perfect fifth). LOOP retriggers the pool's first note. VARY
   swaps a played step for a random pool note; RATCHET splits a played step
   into 2-4 even hits of the same note, each with GATE of its share. Per osc
   rng (xorshift). Arp notes jump on their onset sample (GLIDE is step 4);
   drones glide 80 ms. Amp envelope per sample after the filter: linear
   attack, exponential decay to SUSTAIN, release at the decay rate, restart
   from the current level; an arp voice rests silent (release stage) until
   its first hit, and a drone switched to an arp fades at DECAY until the
   next step. Verified (`test_arp.py`, 31 checks): 1/8 @ 120 = 250.0 ms,
   @ 60 = 500.0, 1/16 = 125.0, 1/4T = 333.4; 1/4T, 1/8T and 1/16 at 137 BPM
   on the shared grid for 60 s with < 0.04 ms drift; KEY / TRIAD / 7TH /
   FIFTHS / ROOT pools, RANGE 2, DOWN, UP-DN, RANDOM in pool; LENGTH 5 over
   a 14-note pool repeats every 5; CHORD IV moves the pool to D F A;
   DENSITY 3/8 hits steps 0 3 6 (tresillo), DENSITY 0 silent from sample
   one; GATE duty 0.244 / 0.718; release 100 ms after the gate at 0.108 of
   the held level (DECAY 200 ms, expect ~0.10); SWING 1 = 333 / 167 ms;
   RATCHET 2-4 hits per step; VARY on LOOP; MODE OFF steady; all three
   arpeggiate at power-on. Firmware `make` clean, flash 87.1 %.
   Hardware not yet heard (CPU check pending).
3. **DONE — Progression** (2026-09-23). `kProgs[]` holds the presets as
   scale degrees; `ChordAt(beat)` = PROG's degree at floor(beat / CHANGE)
   mod its length (counted from beat 0, so changes fall on bar lines), or
   KEY CHORD when PROG is OFF. The block computes the chord *now* (drones,
   screen), but an arp step builds its pool on `ChordAt(its own start)`,
   so a step starting exactly on a bar line already plays the new chord
   (`kBeatEps` keeps float rounding from putting it in the old one; checked
   at 1/16T, whose 24th step is the bar line). RESTART: the pattern
   position counts steps from `RestartBeat()` = 0 (FREE), the last bar line
   (BAR) or the last CHANGE boundary (CHORD; with PROG OFF it restarts every
   CHANGE anyway, since manual chord moves have no grid). The screen centre
   shows the chord name in its root's fifths hue (`GetChordName`: root +
   quality: "", m, dim, + or sus from the triad on a scale key, the chord
   type's suffix on a chord key), the numeral (`GetChordNumeral`, lowercase
   when minor), the progression position ("3/4") and 4 beat dots, on a
   black disc over the scope; it fades in as the readout fades out. Font
   gained a d i j m s v. Verified (`test_prog.py`, 40 checks): all 8
   presets in C major, A minor and on an A MIN7 chord key (parallel m7
   chords); POP / FALL / EPIC / JAZZ names and numerals (C I, Bdim vii, Am
   vi, Dm ii ...); Dsus4 on a chord key; CHANGE 1/2..4 bars; chord changes
   every 4th quarter step; RESTART FREE / BAR / CHORD sequences; KEY
   readouts; the centre drawn. Flash: `canvas.h` draw helpers are now
   `noinline` (RenderScreen 7.7 -> 5.1 KB), total 87.7 %.
4. **DONE — FILTER and PITCH envelopes + GLIDE** (2026-09-23). The sample
   loop now has a **control tick every kCtrl = 16 samples** (0.33 ms, same
   at the sim's 256 and the Seed's 48): `ControlTick` glides the pitch,
   sets both oscillators' frequency (note + PITCH env) and both SVFs'
   cutoff (CUTOFF + master + FILTER env), then advances the two envelopes.
   The plan said "block rate" for modulation, but a 5 ms sim block is too
   coarse for 5 ms envelopes, and the tick costs little (6 `Svf::SetFreq`
   per tick). A hit (`Strike`) sets the target note (jumping at once when
   GLIDE is 0, so onsets stay sample-exact), kicks the PITCH env to 1 and
   restarts the FILTER env's attack from its current level; the cutoff
   follows on the next tick. FILTER env: linear attack (1 ms..4 s), then
   exponential decay to 0 (5 ms..4 s, 99 % in the shown time), AMOUNT
   +-4 oct; drones never hit, so it rests at 0 for them. PITCH env: starts
   at AMOUNT (whole semitones, +-12) and decays to 0 (5 ms..1 s); ratchet
   hits re-kick it. GLIDE: exponential, 99 % in GLIDE (0..1 s) for arp
   notes; drones glide on chord changes over max(GLIDE, 370 ms) (the old
   80 ms time constant). Verified (`test_env.py`, 16 checks): FILTER
   AMOUNT 0 steady, +4 oct 2.8x brighter at the hit and back by 400 ms,
   -4 oct dark then open, ATTACK 200 ms peaks late, DECAY 1 s vs 50 ms;
   PITCH +12 over 1 s measured +10.0 / +2.4 / +0.2 st at 40 / 350 / 875 ms
   (theory +10 / +2.4 / +0.2), -12 mirrors it, 50 ms settles; GLIDE 0
   jumps, 500 ms reaches +2.1 st of a fifth at 40 ms (theory +2.2); a drone
   slides A2 -> D3 in ~0.37 s and slower with GLIDE 1 s; the pitch env
   leaves drones alone. Flash 88.2 %.
5. **DONE — LFO page** (2026-09-23). 15 LFOs (`lfo_[target][osc]`) on the
   control tick. FREE: phase advances by RATE (0.02..20 Hz); the three
   oscillators start a third of a cycle apart. TEMPO (KEY LFO SYNC): RATE
   picks one of 4 BARS, 2 BARS, 1 BAR, 1/2, 1/4, 1/4T, 1/8, 1/8T, 1/16
   (hysteresis, readout shows the division) and the phase is
   frac(beat / division) of the master clock, so synced LFOs line up with
   the bar and each other. Waves: SINE (the MorphOsc parabola, no trig),
   TRI, SAW (rising), SQUARE, S+H (new random value each cycle), DRIFT
   (smoothstep from the last random value to the next). Destinations, full
   scale at DEPTH 1: PITCH +-1 st (added in `SetPitch`), CUTOFF +-3 oct
   (added to the tick's cutoff), AMP dips to 1 - DEPTH at the wave's bottom
   (never boosts; ramped per sample across the tick), PAN +-0.5 of the
   position (pan gains now per tick), SHAPE +-0.5. Verified (`test_lfo.py`,
   16 checks): PITCH +-1.00 / +-0.50 st at 2 Hz (period 0.500 s); SQUARE
   two levels, SAW rising with one drop per cycle, S+H holding, DRIFT
   smooth, TRI +-1; CUTOFF 285..2021 Hz at 1 Hz; AMP low/high 0.00 and
   0.47 (want 0 and 0.5); PAN -1..+1; SHAPE 3rd harmonic 0.015..0.248; osc
   1's LFO leaves osc 2 alone; SYNC 1/4 square flips on the 1/8 grid
   (within the 10 ms detection window). Flash 89.2 %.
6. **DONE — Delays** (2026-09-23; the reverb landed in step 1). One stereo
   delay per oscillator (`delays_[o]`, lines from `Buffers`, SDRAM on the
   Seed), processed inside the oscillator loop on the osc's own panned
   signal. Time = DIVISION (1/32 .. 1/1, incl. T and dotted) of TEMPO,
   slewed 80 ms in the log domain (snapped on the first block), plus WOBBLE
   (an Ornstein-Uhlenbeck walk per side, 4 s memory, 0.3 s smoothing, up to
   3 ms), ramped per sample. Loop: taps -> TONE one-pole (500 Hz..12 kHz)
   -> 20 Hz DC blocker; lines written at kDelaySend (0.5) through a soft
   clip, the repeats made up 2x. SEND x master DELAY (0..2x) feeds it,
   FEEDBACK on the reference's stretched curve. WIDTH 0 = parallel L / R
   lines (the osc's pan survives in its repeats), 1 = ping-pong (mono in on
   L, L -> R -> L). Dry + repeats go on to the reverb send. Test helper
   `solo()` now also sets master DELAY 0 (a dry voice). Verified
   (`test_delay.py`, 16 checks): first echo at 251 / 501 / 501 / 376 /
   84 ms for 1/8, 1/4, 1/8 @ 60, 1/8., 1/16T (want 250 / 500 / 500 / 375 /
   83); SEND 0.5 -> first echo 0.50 of the hit; loop gain 0.5 -> repeats
   0.50, 0.50; SEND 0 and master 0 silent; master 2x doubles; ping-pong
   echo 1 left, echo 2 right; a hard-left osc's repeats stay left; TONE
   500 Hz third echo 305 Hz centroid vs 2486; WOBBLE spreads the echo
   spacing 0.52 ms (0.01 ms without); osc 2 never reaches osc 1's delay.
   Flash 90.7 %, SDRAM unchanged (lines allocated in step 1).
7. **DONE — Screen views** (2026-09-23). KEY VIEW picks RINGS (default),
   WHEEL or SCOPE; the view dims under the readout and hides under the maps,
   the chord centre (disc now r 48) fades in as the readout fades. The audio
   thread publishes per osc `ringLen_` (0 = drone), `ringPos_`,
   `ringNote_[o][pos]` (MIDI, or rest / unplayed), `ringRatchet_`,
   `oscHz_` (sounding frequency), and `dispKeyMask_ / dispChordMask_`.
   **RINGS** (r 102 / 80 / 58, outer = OSC 1): 256 points round the ring
   (sin / cos table), each point's radius = R + the captured signal at the
   matching phase of one period of the osc's scope ring (period from
   `oscHz_`, aligned on a rising zero crossing), repeated
   round(3 * f / 110) times (3 at A2, 2..24); segments colored per step arc
   (arcs centred on the dots), rests grey, unplayed dark. **Made more
   prominent on user request (2026-09-23, "too subtle")**: the signal is
   divided by LEVEL (`oscLvl_`, so a quiet osc still draws a full ring;
   the envelope still sets the height), 40 px per unit soft-limited to
   +-9 px (was x 20 clamped at +-7), played arcs at 70 % of their hue (was
   40 %), the playing step at 100 % (was 90 %), a 2 px stroke everywhere
   (the user tried 2 px only on the playing arc and went back to 2 px
   always). Rings are 22 px apart, so two +-9 px waves plus the stroke
   never touch. **Readout over the view (user, same day: "dims far too
   much")**: the view keeps 75 % under the readout (was 40 %) and 20 %
   under the page / sub maps (was hidden); the readout's three text lines
   sit on bands darkened in step with its fade (`TextOnDark`). Readout and
   centre chord hand over (text out in the first half of the fade, chord
   in during the second) instead of overlapping. Dots: playing = r 7 +
   r 10 halo, played r 4, ratchet = two r 3, rest hollow, unplayed r 2. A
   drone is one unbroken ring in its note's hue. **WHEEL**: 12 notes in
   fifths order at r 94 (C on top, so hue and position agree); chord tones
   r 6 joined in wheel order (the chord's shape), key notes r 3 dim,
   others r 1; each osc's note a disc (r 7 / 5 / 4 for OSC 1 / 2 / 3) at
   its pitch class, radius 30 + (note - 36) x 56/48 (higher = nearer the
   rim), its previous note dim; chord name + numeral in the middle.
   **SCOPE**: the reference scope. Canvas gained `DrawLine`. The whole
   screen section is compiled `-Os` (`#pragma GCC optimize`): the views
   pushed flash to 94.9 %, `Os` brought RenderScreen 9.4 -> 3.5 KB and
   flash to 89.9 %. Verified (`test_screen.py`, 9 checks, on the rendered
   framebuffer): three rings drawn; osc 1 playing A -> ring hue 0.254
   (A in fifths order 0.250); DENSITY rests grey (saturation 0.14 vs 1.00);
   the playing dot at 45 then 90 deg (LENGTH 8); ring spread larger just
   after a hit than 420 ms later; a drone ring unbroken in A's hue; WHEEL
   lights A C E, not C# F# G#; SCOPE draws.
8. **Defaults + hardware pass** — agent side done 2026-09-23, **the rest
   is the user's**:
   - Power-on levels (sim, 20 s at VOLUME 1): peak 0.60, RMS 0.082, the
     limiter never bends (no sample above 0.8); the three oscillators alone
     with their effects sit at RMS 0.10 / 0.12 / 0.10.
   - CPU, PC estimate: the arp DLL costs 1.22x the reference drone DLL at
     48-frame blocks (1.23x in a worst case: every LFO on, ratchets, 1/16T,
     all delays and sends up). The reference measured 38 % on the Seed
     before its shimmer / chaos / texture pages existed; the Seed also pays
     more than a PC for SDRAM reads, and this concept reads 6 delay lines
     against the reference's 2. So: probably fine, **must be measured**.
   - `DIAG_ADC 1` build still compiles (85.2 %): it shows CPU avg / max per
     audio block on the screen (plus the pot readings).
   - Open, user: listen to the power-on sound and each page; flash
     (`.\daisy.ps1 flash 06_arp`); CPU on the Seed with `DIAG_ADC 1`
     (`MyProjects\06_arp\synth_main.cpp` line 26; max must stay under ~90);
     the faster display below is done.
   - **Faster display (works on the hardware, user confirmed 2026-09-23)**: the screen felt
     slow once the waves were bold; rendering is not the cost (0.04 ms per
     RINGS frame on the PC), the SPI push is (74 ms at 12.5 MHz). SPI1's
     kernel clock was PLL2P = 25 MHz and PS_2 is the smallest prescaler, so
     `synth_main.cpp` `FAST_DISPLAY_SPI 1` switches the SPI1/2/3 mux to
     PLL3P (49.15 MHz, already running for the SAI) with
     `__HAL_RCC_SPI123_CONFIG` - **not** `HAL_RCCEx_PeriphCLKConfig`, which
     would reprogram PLL3 and could stop the audio. SCK 24.6 MHz, ~38 ms
     per frame, ~26 fps. The sim now draws every 38 ms, and the readout's
     frame counts doubled (kIdleStart 66, kFadeFrames 20 = 2.5 s + 0.75 s
     at 26 fps; with FAST_DISPLAY_SPI 0 they would take twice as long).
     If a rewired panel ever shows garbage or flicker, set it to 0.

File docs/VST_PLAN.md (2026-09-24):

# Ammonite VST — handoff and plan

Written 2026-09-24 at the end of the session that published Ammonite
(https://github.com/GSNautilus/ammonite, listening page
https://gsnautilus.github.io/ammonite/). A new session builds the plugin from
here. Read this, then `docs/ENGINE_PLAN.md` ("Constraints & landmines" first).

**Goal:** Ammonite as a **Windows x64 VST3 plugin, plus CLAP**, running the
very same engine as the firmware (`core/`). No AU, no macOS/Linux for now.
The firmware must keep building from the same core.

**Decided with the user (2026-09-24):**

- **The plugin gets its own copy of the engine** in `plugin/engine/`. `core/`,
  the firmware, the simulator and the 193 tests stay exactly as they are
  (tagged `v1.0`, local, not pushed). The copy becomes multi-instance and
  gains the host features; a fix or sound change in one engine has to be
  carried to the other by hand. Reuniting them later means proving the two
  bit-identical first.
- **DAW sync:** a new SYNC parameter DAW / FREE, default DAW. DAW: BPM and
  song position come from the host (`beat_` = host PPQ while playing), so
  pattern step 1 and the progression land on the DAW's bars. FREE: the
  TEMPO knob and its own clock, like the hardware. With the transport
  stopped, DAW mode keeps playing at the host BPM; on play it jumps to the
  host position.
- **UI:** the hardware panel only (12 knobs, page / section label, the round
  screen); every parameter is also in the host's generic list.
- **Sample rates:** native at the host rate up to 192 kHz; the plugin's
  engine sizes its delay lines for 192 kHz. Tests also run at 96 kHz.
- **Identity:** "Ammonite" by "GSNautilus", CLAP ID
  `com.gsnautilus.ammonite`, DPF brand / unique IDs `GSNa` / `Ammo` (the
  VST3 UID derives from them: never change them after release).
  Categories Instrument | Synth | Generator.

---

## Working environment

- Repo: `C:\Users\Nautilus\Projects\ammonite` (the old Daisy workspace copy
  `Projects\Daisy\synth_arp` is retired; do not work there).
- Commands the user runs are **PowerShell**. From the repo root:
  `.\ammonite.ps1 libs | build | flash | sim | test | manual`,
  `.\simulator.bat`. The agent's own shell is Git Bash.
- Python: conda env `codex` (`$env:AMMONITE_PYTHON` points at its python.exe
  for the scripts). `ziglang` builds `sim\synthcore.dll` (`sim\build_dll.ps1`).
- **C++ for the plugin: Visual Studio Build Tools 2022** is installed:
  MSVC 14.39 (`VC\Auxiliary\Build\vcvars64.bat`), CMake and Ninja under
  `C:\Program Files (x86)\Microsoft Visual Studio\2022\BuildTools\Common7\IDE\CommonExtensions\Microsoft\CMake\`,
  Windows SDK 10.0.22621.
- **Hosts to test in:** Ableton Live 12 (trial) and FL Studio 2025. The system
  VST3 folder `C:\Program Files\Common Files\VST3` does not exist yet and
  needs admin rights: installing there is the user's move (or point the DAW
  at a custom plugin folder).
- GitHub CLI: `C:\Users\Nautilus\gh_cli\bin\gh.exe` (authenticated as
  GSNautilus).
- Repo rules: commits use the repo-local no-reply identity already set in
  `.git/config` (keep it). End commit messages with the Co-Authored-By
  trailer. **Never push, tag or release without the user's go-ahead.**
  Never launch multi-agent fan-outs without stating the scale and getting an
  OK first.

## The engine today

- `core/synth_core.h` is the whole interface: `Init(samplerate, Buffers)`,
  `SetPot / GetPot` (12 panel pots, with page / section pickup),
  `GetPage / GetPageName / GetNumSubs / GetSub / GetSubName`,
  `GetSlotValue / GetSlotName / GetSlotOsc / GetValueText`,
  `SetEngineParam(func, osc, v)` (test hook: bypasses the 20 ms smoothing),
  `GetOscNote`, `GetChordName / GetChordNumeral`,
  `ProcessAudio(out, nframes)` (interleaved stereo float, any block size),
  `RenderScreen(fb)` (240x240 RGB565 in **panel byte order**; see
  `sim/panel_sim.py fb_to_surface` for the byteswap).
- `core/api.cpp` wraps it as a C API (`synth_*`) for the simulator DLL; the
  tests (`tests/arpsynth.py`) call that DLL through ctypes.
- **All mutable state is file-level statics in `core/synth_core.cpp`**
  (2395 lines, 128 `static` declarations): one engine per process. A DAW can
  load several instances and run them on different threads at once, so this
  is the first thing to change.
- Threading model (already used by firmware and sim): the UI side writes
  `std::atomic<float> params_[func][osc]`; the audio thread smooths them and
  computes stepped values (`step_`, with hysteresis); the screen only reads.
  The audio thread publishes what the screen needs (ring notes, positions,
  chord). Keep this split in the plugin: DSP on the audio thread, UI and
  `RenderScreen` on the UI thread.
- Functions: `enum Func` + `kFuncs[]` in `synth_core.cpp` (the tests mirror
  the order in `tests/arpsynth.py FUNCS`). Pages: `kPages[]`.
- Big buffers are lent by the shell through `synth::Buffers`: 6 delay lines of
  `kDelayMaxSamples = 288400` (6 s at 48 kHz, a compile-time template size),
  the `ReverbSc`, two pre-delay lines. On the PC they are statics in
  `api.cpp`; on the Seed they sit in SDRAM (`firmware/synth_main.cpp`).
- Timing: `beat_` (quarter notes since Init, a double) advances by TEMPO each
  block; every arp grid, the progression and synced LFOs derive from it.
  `RenderScreen` is **frame-counted** (readout fade = 66 + 20 frames at the
  display's ~26 fps): call it on a ~38 ms timer, not on every repaint.
- Firmware limits: **C++14**, flash **90.26 %** (118300 B of 128 KB). The screen
  section is compiled `-Os` via `#pragma GCC optimize`. Check the `make`
  memory table after every core change.

## Plan

### Step 1: DONE (2026-09-24): the plugin's engine is an instance

- `plugin/engine/` = `core/` v1.0 copied, namespace `ammonite`: all 48
  mutable statics (plus the function-local ones: value / chord text
  buffers, the WHEEL view's note memory, the unit circle) live in
  `Engine::Impl`; the 48 functions that touch them are its members;
  `class Engine` (`engine.h`) forwards the old API one to one. Constant
  tables and pure helpers are unchanged. `core/` is not touched.
- `plugin/engine/api.cpp`: the `synth_*` calls on a default instance plus
  `eng_create / eng_destroy / eng_*(handle, ...)`.
- `.\plugin\plugin.ps1 test` builds `plugin\build\core_ref.dll` (from
  `core/`) and `plugin\build\ammonite_engine.dll` with the simulator's
  compiler and flags, runs the whole hardware suite (`tests\`) against the
  plugin engine, then `plugin	ests	est_engine_copy.py`:
  - MATCH: 40 random scenarios (params, pot moves, page changes, block
    sizes 1..600, 44.1 / 48 kHz, screens interleaved) are bit-identical
    between core/ and the copy, default and created instance. Checked that
    it bites: a one-ULP change of a gain fails audio, one color step fails
    screens.
  - INSTANCES: same input -> same output; different settings, blocks
    alternating -> each equals its own solo run on core/; two engines on
    two threads with a third rendering their screens -> unchanged; a new
    engine after others were destroyed starts clean.

**Found on the way (for step 2):**

- **core/ crashes above ~52 kHz** (fresh start): `ReverbSc`'s fixed
  `aux_[DSY_REVERBSC_MAX_SIZE]` (98936 floats, sized for 48 kHz) is too
  small, `Init` returns early and the first process writes through a null
  delay-line pointer. Worse, a re-`Init` at a higher rate after a working
  one leaves the old lines in place (no crash, wrong reverb). The define is
  unconditional in `reverbsc.h`, so the plugin needs its own copy of
  ReverbSc (LGPL, keep the notice) with a buffer for 192 kHz, and the
  engine must treat a failed `Init` as an error. The hardware (48 kHz) is
  not affected.
- `Init` does not reset the WHEEL view's note memory (a function-level
  static in core/): harmless, but one reason two engines only match
  bit for bit when they have the same history.
- A fresh worktree has no submodules: `git submodule update --init
  --recursive lib/DaisySP` (libDaisy is only needed for the firmware).

### Plugin shell: DONE (2026-09-24), pulled forward (user: "into a DAW first")

A first loadable plugin before the rest of step 2 and the UI of step 3.

- Engine: 44.1-192 kHz (own ReverbSc copy, lines sized for 192 kHz; above
  it no reverb instead of a crash), host API (`FuncName / FuncPerOsc /
  FuncSteps / FuncDefault / FuncPlace / FuncStepText`, smoothed `SetParam`,
  `GetParam`, `ReverbOk`). Still bit-identical to core/ at 48 kHz.
- `plugin/lib/DPF` (submodule), `plugin/src/DistrhoPluginInfo.h` (IDs as
  decided), `plugin/src/AmmonitePlugin.cpp`: one engine per instance, no
  UI (the host's generic parameter list), a MIDI input it ignores, the
  engine's own TEMPO (no DAW sync yet). Flush-to-zero in `run`.
- **168 parameters**, ID = index over (func, osc) in enum Func order, named
  "PAGE SECTION NAME osc" ("ENVELOPE AMP ATTACK 1", "VOLUME"). Continuous:
  0..100; stepped: the step with the panel's names. The host saves them
  with the project (DPF's own state: parameter values only).
- `.\plugin\plugin.ps1 build` (MSVC 14.39 + CMake + Ninja; `cl` forced,
  the Daisy ARM g++ is on PATH; static CRT) ->
  `plugin\build\cmake\bin\Ammonite.vst3` and `Ammonite.clap`.
  `.\plugin\plugin.ps1 install` (admin PowerShell) copies them to
  `C:\Program Files\Common Files\VST3` and `...\CLAP`.
- `plugin/tests/test_clap.py`: a ctypes CLAP host loads the built
  `Ammonite.clap`: descriptor, 168 unique parameters, plays at 48 / 96 /
  192 kHz, same sound as the tested engine DLL (MSVC vs zig, correlation
  1.0000), automation event, two instances side by side, state save / load.
- **FL Studio 2025 (user, 2026-09-24): loads, plays, parameter changes,
  automation and saving the project all work.** Several instances work
  too. Not yet checked: Ableton Live 12 (VST3 only, Live has no CLAP).
- **FL's channel mute does not silence it** (user): FL mutes a generator
  by withholding notes, and Ammonite ignores notes. The Mixer insert's mute
  works. Possible later: an option to play only while a note is held / a
  pattern plays (a design question for the user).

### DAW sync: DONE (2026-09-24)

- New function **SYNC** (FREE / DAW, default DAW) at the end of enum Func
  (plugin only; not on a panel page, like VOLUME it is always there): 169
  parameters now, the old IDs unchanged.
- `Engine::SetHostClock(playing, bpm, beat)` before each ProcessAudio call.
  SYNC DAW with a host clock: the host tempo (clamped 20..999 BPM, the
  delays too); while playing, `beat_` = the host position in quarter notes,
  so a jump (loop, relocate) just changes each osc's step index and the step
  under the playhead starts at once; stopped: runs on at the host tempo.
  FREE, or no host clock (every test of the hardware suite): TEMPO, bit for
  bit as before.
- Plugin: `DISTRHO_PLUGIN_WANT_TIMEPOS 1`; the position is rebuilt from
  DPF's bar / beat / tick (the CLAP wrapper counts bar beats in quarter
  notes, the VST3 one in time-signature beats: `getPluginFormatName()`).
  A host that stops reporting bars keeps its last tempo.
- Limits: Ammonite's bar is 4 quarter notes (bar lines, CHANGE, RESTART
  BAR), so in 3/4, 6/8 ... its bars drift from the DAW's. DPF's VST3 bar
  maths uses an integer quarter-notes-per-bar (7/8 comes out wrong).
- Tests: `plugin/tests/test_sync.py` (engine: host grid within 1 ms, start
  mid-beat, playhead jump, PROG on the DAW's bars, stopped, FREE, delays on
  the host tempo) and the CLAP host in `test_clap.py` (a CLAP transport
  through the built plugin: grid, jump, stop, FREE).
- **FL Studio (user, 2026-09-24): sync works.**
- Other meters are not a design limit: "a bar = 4 quarter notes" is a
  constant in RestartBeat (BAR), kChangeBeats, the LFO "BAR" divisions and
  the screen's beat counter. A bar length (from the host's time signature
  in DAW mode, a METER setting in FREE) would fix it; a song that changes
  signature also needs the host's bar-start position. After the UI.

### Panel UI: first version (2026-09-24)

- `plugin/src/AmmoniteUI.cpp` (DPF, OpenGL + NanoVG): the simulator's
  panel (1400 x 860 coordinates, window 1050 x 645, resizable with the
  aspect kept): 12 knobs around the round screen, the page / section
  header, a SYNC DAW / FREE button.
- The screen is the engine's own `RenderScreen` on a ~38 ms timer (uiIdle),
  RGB565 panel order -> an RGBA texture, masked round. Knob readouts are the
  engine's `GetValueText` (units as on the hardware; TEMPO shows "DAW 120"
  while the host sets the tempo).
- Knobs edit their host parameter (begin / value / end: hosts record
  automation); no pickup with a mouse. Knob 11 = page, knob 10 = section:
  UI state held in the engine (`SetPanelPage`, `ShowPot` for the readout
  and the maps), not host parameters. Drag (Shift: fine), scroll,
  double-click = default.
- DPF direct access: the UI reaches the engine through
  `ammonite::EngineOf(getPluginInstancePointer())`; the parameter table is
  shared (`AmmoniteParams.hpp`).
- `plugin/tests/ui_check.py` (by hand): opens the real UI in a tkinter
  window through `clap.gui`, plays in real time, screenshots
  (`plugin/build/ui_*.png`), drags knobs with posted mouse messages and
  checks the host sees begin / values / end and the new value, page change,
  a stepped knob, the SYNC button. Not in `plugin.ps1 test`: the real mouse
  over the window can disturb it.
- A standalone `Ammonite.exe` (DPF's jack target) was tried and dropped:
  DPF's native audio fallback on Windows needs MinGW, not MSVC.
- Page and section are not saved with the project (the engine keeps them
  while the plugin lives).
- **FL Studio (user): the UI works.** The screen lagged behind the knobs at
  first: Windows starves the idle timer while mouse moves keep coming, and a
  knob change reached the engine only after FL's round trip. Fixed: mouse
  input also advances the screen, and a knob writes the engine directly
  (as well as the host). The user: "works perfectly".

### Release 0.2.0 (2026-09-24)

- Version 0.2.0 (the repo's numbering: 0.1.0 = the hardware release), in
  `plugin/CMakeLists.txt` and `getVersion`. The local safety tag `v1.0`
  was deleted (v0.1.0 on GitHub marks the published hardware version).
- `.\plugin\plugin.ps1 package` -> `plugin\build\release\Ammonite-0.2.0-win64.zip`:
  `Ammonite.vst3`, `Ammonite.clap`, `INSTALL.txt`, `LICENSE.txt` and
  `licenses\` (DPF ISC, DaisySP MIT, ReverbSc LGPL-2.1). Zip entries are
  written one by one with "/" (PowerShell 5.1's writers store "\").
- The binaries depend only on Windows system DLLs (static CRT; checked with
  `dumpbin /dependents`: KERNEL32, USER32, GDI32, OPENGL32, dwmapi).
- README: "Play it in a DAW" section with `media/plugin.png` (captured from
  the real UI by the ui_check host), to-do ticked, `plugin/` in the table,
  DPF and the plugin's ReverbSc copy under License.
- Later, when wanted: other meters (3/4, 6/8), an option to play only while
  the DAW sends notes (so a channel mute works), saving page / section with
  the project, a 60 fps screen with time-based fades, GitHub Actions builds,
  Ableton Live 12 check.

- **Tempo / transport:** an API the plugin calls each block with the host's
  BPM, song position (PPQ) and playing flag; `beat_` follows the host. Decide
  the behaviour with the user (see decisions).
- **Sample rate:** the delay lines hold 6 s at 48 kHz. For 44.1 / 48 kHz
  nothing changes. For 88.2 / 96 kHz and up either make the line length a
  build-time setting for the plugin (4x = ~28 MB per instance) or run the
  engine at 48 kHz and resample. Decide with the user.
- **Parameters for automation:** expose every `(func, osc)` as a host
  parameter with a **stable ID** (never reorder `enum Func` after release, or
  give each function an explicit ID). Needs: read a param, its name and its
  value text for any `(func, osc)` (today the text is per pot); a **smoothed**
  setter for automation (the test hook is not smoothed).
- **State:** save / load every param (plus the chosen page and sections) as a
  versioned chunk, so projects reopen as they were.

### Step 3: the plugin, with DPF

- DPF (https://github.com/DISTRHO/DPF, ISC license) as a submodule
  `lib/DPF`; one codebase builds **VST3 and CLAP** (also LV2 / VST2, not
  needed). Avoid JUCE (AGPL or paid).
- New `plugin/` folder: `DistrhoPluginInfo.h`, the DSP side wrapping one
  Engine, the UI side. A synth: no audio inputs, stereo out; no MIDI in for
  now (Ammonite plays by itself).
- UI = the simulator panel: 12 knobs, page / section label, the 240x240
  screen drawn from `RenderScreen` (scaled, with a round mask). With a mouse
  there is no need for pickup jumps: when the page changes, draw each knob at
  its stored value. Knob drags become host parameter edits
  (begin / change / end) so automation records them.
- The UI reaches the engine through DPF's direct-access option (plugin and
  UI in one process), keeping the thread split above.

### Step 4: build and ship

- `.\ammonite.ps1 plugin` builds `Ammonite.vst3` and `Ammonite.clap` (MSVC +
  CMake + Ninja).
- Test in Ableton Live 12 and FL Studio 2025: loads, plays, several
  instances at once, follows the DAW tempo, automation, save and reopen.
- Then README (tick the to-do item, how to install), and a release, after
  the user's go-ahead. Later: GitHub Actions builds.

## Decisions (taken 2026-09-24, see the top of this file)

1. DAW sync: SYNC DAW / FREE, default DAW; keeps playing when stopped.
2. UI: the hardware panel only.
3. Sample rates: native, up to 192 kHz.
4. Identity: Ammonite / GSNautilus / `com.gsnautilus.ammonite` / `GSNa` `Ammo`.
5. Firmware: stays on `core/` untouched; the plugin has its own engine copy.

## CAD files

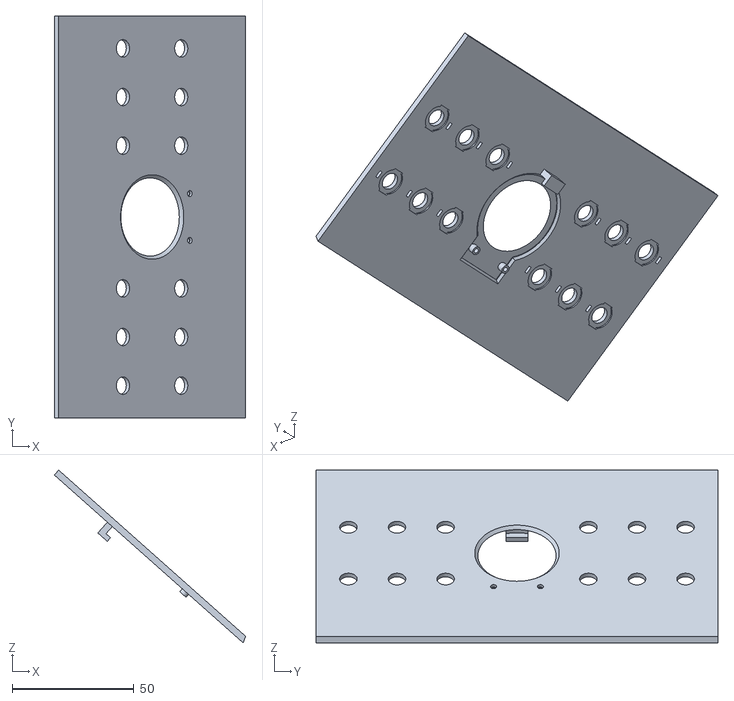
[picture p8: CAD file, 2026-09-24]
hardware/stl/front_panel.stl
78.5 x 165.0 x 70.9

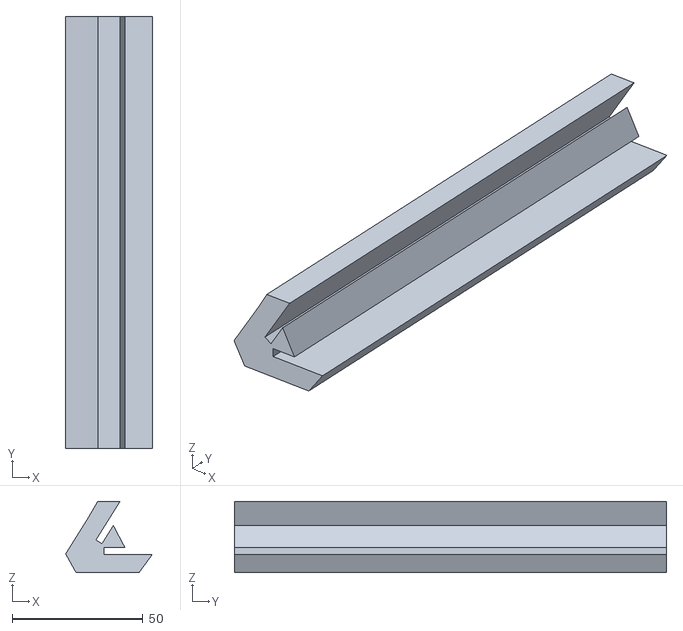
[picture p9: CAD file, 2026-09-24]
hardware/stl/back_rail.stl
33.1 x 165.0 x 27.3

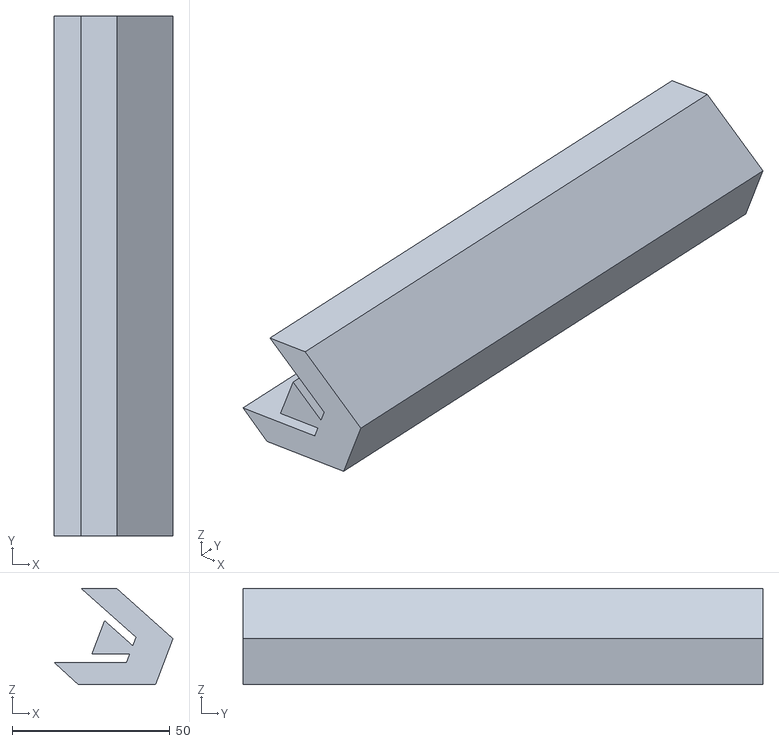
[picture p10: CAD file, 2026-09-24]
hardware/stl/front_rail.stl
37.8 x 165.0 x 30.5

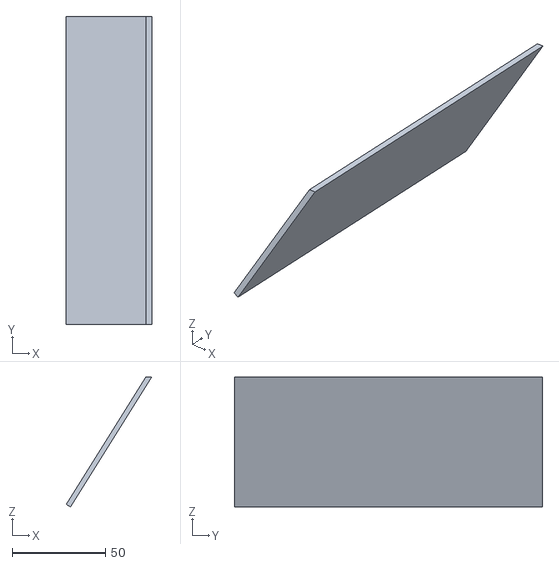
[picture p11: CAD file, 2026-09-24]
hardware/stl/back_panel.stl
45.8 x 165.0 x 69.6

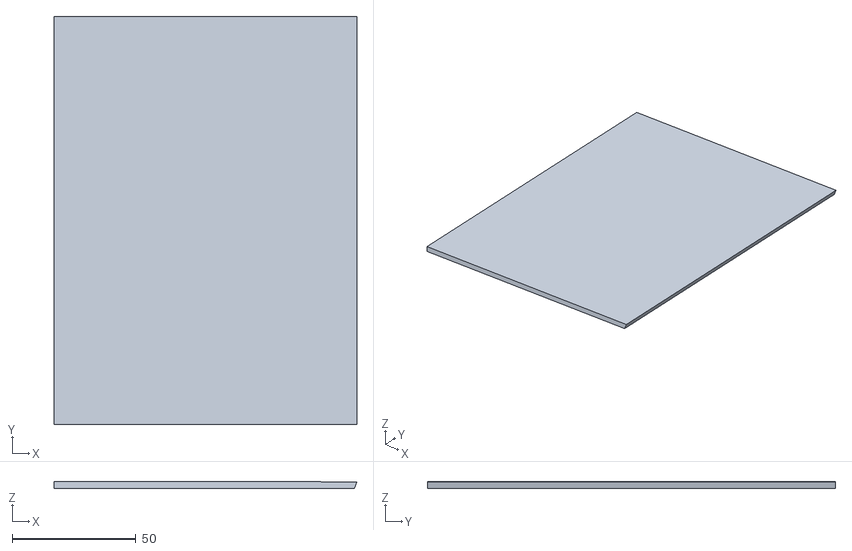
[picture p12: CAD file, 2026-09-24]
hardware/stl/bottom_panel.stl
122.5 x 165.0 x 2.70

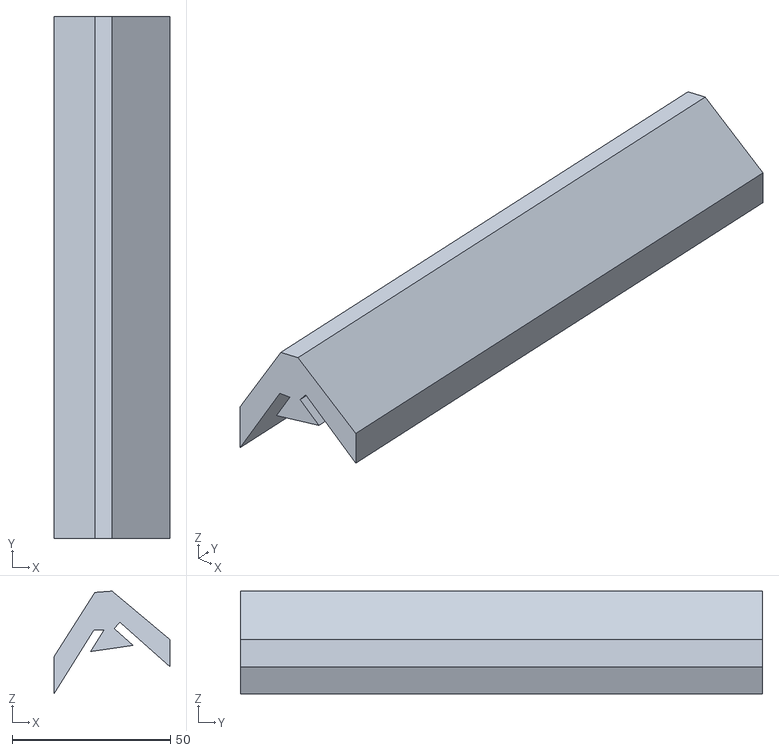
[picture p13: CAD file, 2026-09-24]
hardware/stl/top_rail.stl
36.6 x 165.0 x 32.5

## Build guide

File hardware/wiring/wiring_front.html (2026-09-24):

# Drone synth panel → Daisy Seed3 wiring

FIRST WIRE, BEFORE ANYTHING ELSE: Seed pin 20 (AGND) to Seed pin 40 (DGND). The Seed3 does not bond them. Without this jumper every knob reads full scale.

## Every wire, as a list

# | Knob | Row | Terminals left→right as mounted | Wiper → Seed pin | ADC

1 | ROOT | top | V · OUT · G | 22 | A0
2 | SPREAD | top | V · OUT · G | 23 | A1
3 | DETUNE | top | V · OUT · G | 24 | A2
4 | CUTOFF | bottom (flipped) | G · OUT · V | 25 | A3
5 | RESO | bottom (flipped) | G · OUT · V | 26 | A4
6 | DRIVE | bottom (flipped) | G · OUT · V | 27 | A5
7 | RATE | top | V · OUT · G | 28 | A6
8 | DEPTH | top | V · OUT · G | 29 | A7
9 | DRIFT | top | V · OUT · G | 30 | A8
10 | SHIMMER | bottom (flipped) | G · OUT · V | 31 | A9
11 | REVERB | bottom (flipped) | G · OUT · V | 32 | A10
12 | VOLUME | bottom (flipped) | G · OUT · V | 35 | A11

All V terminals join one red bus per group, all G terminals one black bus per group. Each group sends one red lead to pin 21 and one black lead to pin 20. Pin 20 is jumpered to pin 40. Pins 33 and 34 are skipped on purpose (no ADC there).

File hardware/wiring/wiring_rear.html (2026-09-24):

# Drone synth panel → Daisy Seed3 wiring — VIEWED FROM BEHIND THE PANEL

Mirror image of the front. Knob 1 is at the top-right, knob 12 at the bottom-left. ONE RULE FOR EVERY POT, seen from behind: LEFT terminal = VCC, MIDDLE = output, RIGHT = ground. Rows mounted upside down turn the opposite way; the firmware invert table corrects that.

FIRST WIRE, BEFORE ANYTHING ELSE: Seed pin 20 (AGND) to Seed pin 40 (DGND). The Seed3 does not bond them. Without this jumper every knob reads full scale.

## Every wire, as a list

# | Knob | Row | Terminals left→right, seen from behind | Wiper → Seed pin | ADC

1 | ROOT | top | V · OUT · G | 22 | A0
2 | SPREAD | top | V · OUT · G | 23 | A1
3 | DETUNE | top | V · OUT · G | 24 | A2
4 | CUTOFF | bottom (flipped) | V · OUT · G (inverted in firmware) | 25 | A3
5 | RESO | bottom (flipped) | V · OUT · G (inverted in firmware) | 26 | A4
6 | DRIVE | bottom (flipped) | V · OUT · G (inverted in firmware) | 27 | A5
7 | RATE | top | V · OUT · G | 28 | A6
8 | DEPTH | top | V · OUT · G | 29 | A7
9 | DRIFT | top | V · OUT · G | 30 | A8
10 | SHIMMER | bottom (flipped) | V · OUT · G (inverted in firmware) | 31 | A9
11 | REVERB | bottom (flipped) | V · OUT · G (inverted in firmware) | 32 | A10
12 | VOLUME | bottom (flipped) | V · OUT · G (inverted in firmware) | 35 | A11

Every pot is wired the same way. A row that turns the wrong way is fixed in kPotInvert in synth_main.cpp, never by rewiring. All V terminals join one red bus per group, all G terminals one black bus per group. Each group sends one red lead to pin 21 and one black lead to pin 20. Pin 20 is jumpered to pin 40. Pins 33 and 34 are skipped on purpose (no ADC there).

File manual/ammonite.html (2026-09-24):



Owner's manual

# AMMONITE

Three-voice arpeggiator synthesizer

The Ammonite screen at power-on

Daisy Seed · 12 knobs · round screen
Manual draft, September 2026

Oscillators, arps and chords
in one small box

# CONTENTS

Every screen picture in this manual comes straight from Ammonite's own code: it is exactly what the round screen shows. A word on words: page always means one of Ammonite's nine knob pages (page 3 ARP); p. 12 means a page of this booklet.

1. Quick startfrom power to your own pattern00
2. The panelpages, columns, sections, and how knobs take over00
3. How Ammonite playsthree voices, one key, one clock00
4. The nine pages
5. 1MAINlevels, key, tempo, masters00
6. 2OSCshape and pitch00
7. 3ARPnotes, rhythm, chance00
8. 4ENVELOPEamp, filter and pitch envelopes, glide00
9. 5FILTERcutoff, resonance, type, drive00
10. 6LFOfifteen LFOs, five targets00
11. 7DELAYone echo per oscillator00
12. 8MIXpan, width, reverb00
13. 9KEYprogressions, tuning, view00
15. Reading the screenrings, colors, four views00
16. Recipesfive patches to start from00
17. Scales and chordsevery SCALE setting, spelled out00
18. Cheat sheetevery knob on one page00

Start here

# Quick start

Ammonite plays the moment it has power. Five minutes from here you will have changed its key, its tempo and its chords.

1. Turn it down, then plug in. Turn knob 12 (VOLUME) to the left, connect the stereo output to your amp, mixer or speakers, and power Ammonite from USB. Then bring VOLUME up.
2. Listen. Three arpeggios in A minor at 110 BPM. OSC 1 plays the low root and fifth in quarter notes, OSC 2 runs up and down the chord in eighths, OSC 3 picks random notes of the scale in sixteenths, leaving a few steps out. No effects are on yet.

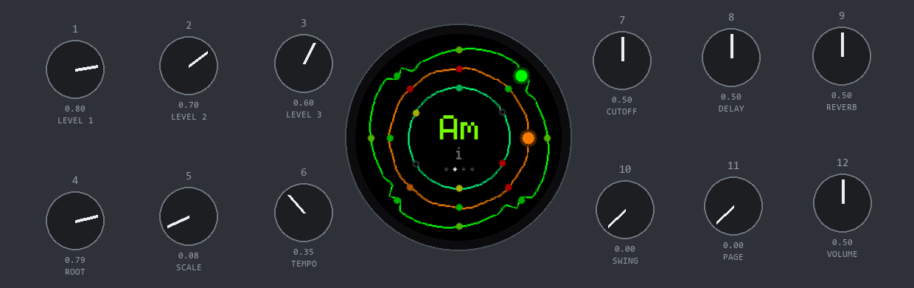
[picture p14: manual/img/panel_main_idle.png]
The panel at power-on


Power-on. Knob 11 points at page 1, MAIN. The screen shows the three arps as rings (see Reading the screen, p. 00).

1. Change the tempo. Turn knob 6, TEMPO. The screen shows what you are turning and its value, then fades back to the rings.
2. Change the key. Knob 4 is ROOT, knob 5 is SCALE. Try DORIAN or PENTA. All three arps follow at once; nothing can play a wrong note.
3. Let the chords move. Turn knob 11 all the way right, to page 9, KEY. Turn knob 1 (PROG) to POP. Now the chord changes every bar, and every arp follows it.
4. Add echoes and space. Knob 11 to page 7, DELAY: turn up knobs 7–9, the delay SEND of each oscillator. Then page 8, MIX: knobs 7–9 are the reverb sends.

Two things worth knowing now

- Changing page never changes the sound. But when you then touch a knob, its setting jumps to where the knob points. The whole story is on p. 00.
- Nothing is saved. Switch off and on, and Ammonite starts again from its power-on sound, with one exception: the page knob 11 points at when you switch on takes its settings from where its knobs are. With knob 11 on page 1, that means the levels, key, tempo and masters start where you left the knobs.

Twelve knobs, nine pages

# The panel

Twelve knobs control about a hundred settings. They are organised so that once you know four rules, you can find anything.

## 1. Knob 11 picks the page

There are nine pages. Turn knob 11 and the screen lists the new page's knobs. Knob 12 is always VOLUME, whatever the page.

Page | What its knobs do | Knob 10 | Manual
1 MAIN | levels, key, tempo, and master cutoff, delay and reverb | SWING | p. 00
2 OSC | each oscillator's shape, octave and starting note | DETUNE | p. 00
3 ARP | what each arp plays and when | SECTION | p. 00
4 ENVELOPE | how each note starts and ends, in volume, filter and pitch | SECTION | p. 00
5 FILTER | brightness and tone of each oscillator | DRIVE | p. 00
6 LFO | slow (or fast) movement of pitch, cutoff, volume, pan, shape | TARGET | p. 00
7 DELAY | each oscillator's own echo | SECTION | p. 00
8 MIX | pan, stereo width and reverb send | SIZE | p. 00
9 KEY | chord progressions, tuning, reverb tone, the screen view | VIEW | p. 00

## 2. Columns are oscillators

On pages 2 to 8, each column of knobs belongs to one oscillator, in both groups: knobs 1 4 7 are OSC 1, 2 5 8 are OSC 2, 3 6 9 are OSC 3. Each row does one job for all three: on page 5, for example, knobs 1–3 are the three CUTOFFs, 4–6 the three RESOs and 7–9 the three TYPEs. The screen lists a page the same way: 1-3 CUTOFF, 4-6 RESO…

Pages 1 MAIN and 9 KEY are different: they set things for the whole instrument, so every knob there has its own job.

## 3. Knob 10 is shared, or picks a section

On most pages knob 10 is one setting shared by all three oscillators (DETUNE, DRIVE, SIZE…). On four pages there is more to control than nine knobs can hold, so the page is split into sections and knob 10 chooses one: ARP, ENVELOPE and DELAY call it SECTION, LFO calls it TARGET. Choosing a section only changes what knobs 1–9 control. It never changes the sound.

## 4. A knob takes over when you turn it

Every knob on every page and section remembers its own setting. When you change page (or section) the knobs themselves stay where they are, so most of them now point somewhere other than the setting they control. Ammonite leaves every setting alone until you turn its knob. The moment you do, the setting jumps to where the knob points, and from then on follows it.

So glance at a knob's pointer before you turn it. If it points far from where the sound is, expect a jump. A tiny wobble does not count as a turn, so brushing a knob does nothing.

## The screen tells you what you touched

Readout

Readout. Turn any knob: its name, value and a gauge. Column pages add the oscillator (and section) above the name.

Page map

Page map. Turn knob 11: the page's name and what each row of knobs does.

Section map

Section map. Turn knob 10 on a page with sections: the section, its rows, and one dot per section.

About 2.5 seconds after you let go, the text fades and the rings return. Under a section map, the bright dot is the section you are in. On the LFO page, a colored dot marks a target that is doing something (its DEPTH is up on some oscillator) and a grey dot one that is off.

The ideas behind the knobs

# How Ammonite plays

Three voices, one key and one clock. Everything on the nine pages is a detail of one of these three.

## Three voices

Ammonite has three oscillators, OSC 1 to OSC 3. Each is a complete little synth with its own arpeggiator, envelopes, filter, LFOs, echo and place in the stereo mix. They play one note at a time each, so together they make three-part music. Inside, every oscillator is really two oscillators, pulled slightly apart by DETUNE for a fuller sound.

## One key

You never choose notes on Ammonite. You choose a key (ROOT and SCALE on page 1), a chord within it, and then, for each oscillator, which of the chord's notes it may use. That set of notes is the oscillator's pool, and its arp plays from nothing else. Here is how the power-on sound gets its notes:

Key
ROOT A, SCALE MINOR

ABCDEFG

Chord
i, the first chord: Am

ACE

OSC 1 pool
DEGREE +0, FIFTHS, 1 octave

A2E3

OSC 2 pool
DEGREE +2, TRIAD, 2 octaves

C4E4G4C5E5G5

OSC 3 pool
DEGREE +4, KEY, 2 octaves

E5F5G5A5B5C6D6E6F6G6A6B6C7D7

DEGREE (page 2) moves a pool's starting note up the scale from the chord's root: OSC 2 starts two scale steps up, on C, so its TRIAD is C E G. POOL and RANGE (page 3) say which notes to take and over how many octaves; OCTAVE (page 2) places the pool high or low. The colored dots are each note's screen color (p. 00).

When the chord changes, from a progression or from CHORD on page 9, every pool is rebuilt on the new chord, and all three oscillators move with it. SCALE can also be a chord type (MAJ, MIN7, ADD9…) instead of a scale: then the key is that chord, and a progression moves it around, keeping its color.

## One clock

A single master clock (TEMPO on page 1) drives all three arps, the progression, the delay times and, if you want, the LFOs. Each arp divides the beat its own way (DIVISION), but every grid starts from the same beat, so however strange the combination, the three never drift apart.

The three arps on the master clock

Two bars of the power-on patterns. Each block is a step; rust marks the first step of a pattern. OSC 3's pattern is 6 steps long, so it starts over at different places in each bar; its DENSITY of 4/6 leaves out the same two steps every time round (hollow).

Three things shape the rhythm beyond DIVISION. LENGTH sets how many steps a pattern has before it starts over; different lengths make patterns that slide against each other. DENSITY leaves steps out, spread as evenly as possible. SWING (page 1, knob 10) delays every second step. And RESTART on page 9 can pull every pattern back to its first step on each bar or each chord.

## Arps and drones

Set an oscillator's MODE (page 3) to OFF and it stops arpeggiating: it holds a single note (the first of its pool) and slides to the new note when the chord changes. A drone ignores the amp envelope's decay: it fades in over ATTACK and then simply holds. One drone under two arps, or three drones and no arps at all, are both good ways to play Ammonite.

1

Page 1 · whole instrument

# MAIN

The performance page: how loud each oscillator is, what key and tempo you are in, and three master knobs that move a whole part of the sound at once.

Page 1, MAIN

Page 1 just chosen. MAIN is a whole-instrument page: every knob has its own job. The screen's two columns mirror the panel's two groups.

Knob | Function | Settings | Power-on | What it does
1 2 3 | LEVEL | 0 to 100 | 80, 70, 60 | The volume of OSC 1, 2 and 3.
4 | ROOT | C to B | A | The key's home note. Everything transposes with it, progressions included.
5 | SCALE | 10 scales, then 10 chord types | MINOR | Which notes belong to the key. Turn past BLUES for chord keys, MAJ to ADD9: the key becomes that chord. Every setting is spelled out on p. 00.
6 | TEMPO | 40 to 240 BPM | 110 BPM | The master clock: arps, chord changes, delay times and synced LFOs.
7 | CUTOFF | −3.0 to +3.0 OCT | +0.0 OCT | Moves all three filters together, up to three octaves either way from where page 5 has them. A performance filter sweep.
8 | DELAY | 0.0 to 2.0 X | 1.0 X | Scales all three delay SENDs (page 7) at once: 0 silences every echo, 2 doubles every send.
9 | REVERB | 0.0 to 2.0 X | 1.0 X | The same for the three reverb sends (page 8).
10 | SWING | 0 to 100 | 0 | Delays every second step of every arp. At 100 the steps go long-short, 2 to 1: a full triplet shuffle.

Why the masters sit in the middle. The three master knobs multiply or shift what the other pages set. At their centre positions they change nothing, so you can dial in each oscillator's cutoff, echo and reverb carefully on pages 5, 7 and 8, then come back here and move all three together while you play.

Try this

- Turn SCALE slowly from one end to the other while the arps run. Each step is a new key; the chord keys at the far end are the most colorful.
- Sweep CUTOFF down to −3 and back for a whole-mix filter build.
- SWING at about 30 loosens sixteenths without sounding like a shuffle.

TEMPO readout

TEMPO turned to 120 BPM. Page 1 has no columns, so the readout shows no oscillator.

2

Page 2 · one column per oscillator

# OSC

What each oscillator sounds like, how high it plays, and which note of the chord it starts from.

Page 2, OSC

Page 2. Row A (knobs 1–3) is SHAPE, row B (4–6) OCTAVE, row C (7–9) DEGREE; knob 10 is DETUNE, shared by all three.

Knobs | Function | Settings | Power-on | What it does
1 2 3 | SHAPE | 0 to 100 | 100, 50, 30 | The waveform, morphing smoothly: 0 a pure sine (soft, round), 50 a square (hollow, woody), 100 a saw (bright, buzzy).
4 5 6 | OCTAVE | −1 to +3 | +0, +1, +2 | Moves the oscillator's whole pool by octaves. At +0 the pool starts around the second octave (A2 at power-on); each step doubles the pitch.
7 8 9 | DEGREE | +0 to +7 | +0, +2, +4 | Where the pool starts, in steps up the scale from the chord's root. The power-on values are the chord's root, third and fifth: with every arp off, the three drone the chord.
10 | DETUNE | 0.0 to 20.0 CT | 8.0 CT | Each oscillator is two oscillators; DETUNE pulls them apart (in cents, hundredths of a semitone). A little gives a gentle chorus; 20 is wide and wobbly. MIX WIDTH (page 8) can spread the two apart in stereo.

Try this

- A bass line. OSC 1 at SHAPE 0 and OCTAVE −1 gives a round sub bass under the other two.
- Unison. Give OSC 2 and OSC 3 the same DEGREE and OCTAVE as OSC 1, but different MODEs on page 3: three rhythms on the same notes.
- Chord colors. With every arp off, try DEGREEs 0, 2, 4, 6: a seventh chord that follows the progression.

3

Page 3 · three sections

# ARP

Which notes each oscillator plays, when it plays them, and how often it surprises you.

Every oscillator has its own arpeggiator. On each step it takes the next note from its pool (p. 00), a handful of notes built from the key and the chord playing now. All three arps run from one master clock, so however different their rhythms, they never drift apart.

There are too many settings for one page of knobs, so ARP has three sections. Knob 10 picks the section. Choosing a section only changes what knobs 1–9 control, never the sound.

The ARP page, CHANCE section

The ARP page with the CHANCE section chosen. Knob 10 has just been turned, so the screen lists the section's knobs. Each column is one oscillator: knobs 1, 4 and 7 set OSC 1; knobs 2, 5 and 8 set OSC 2; knobs 3, 6 and 9 set OSC 3.

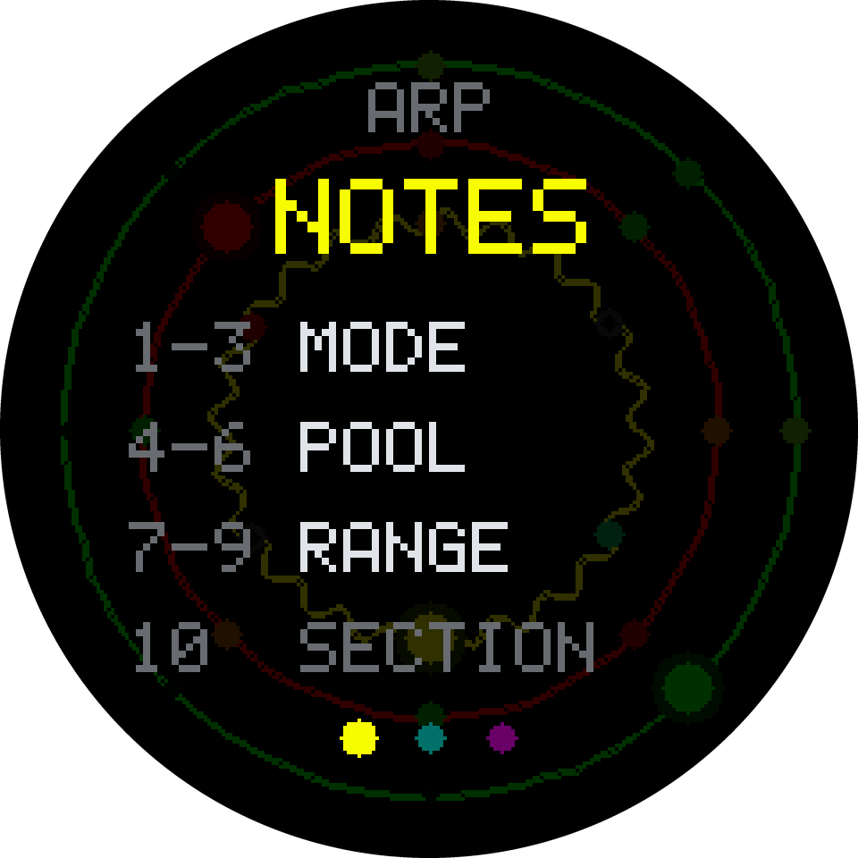
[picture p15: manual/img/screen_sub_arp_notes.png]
NOTES section map


NOTES
which notes

RHYTHM section map

RHYTHM
when they play

CHANCE section map

CHANCE
how often, how surprising

### Notes

Knobs | Function | Settings | Power-on | What it does
1 2 3 | MODE | OFFLOOPUPDOWNUP-DNRANDOM | UP, UP-DN, RANDOM | The order the arp walks through its pool. LOOP repeats one note in rhythm. OFF stops the arp: the oscillator holds a single note, a drone that slides to follow the chord.
4 5 6 | POOL | KEYTRIAD7THFIFTHSROOT | FIFTHS, TRIAD, KEY | Which notes the arp may use. KEY: every note of the scale. TRIAD and 7TH: the chord's three or four notes. FIFTHS: root and fifth. ROOT: the root alone, in octaves.
7 8 9 | RANGE | 1 OCT2 OCT3 OCT | 1, 2, 2 OCT | How many octaves the pool spans.

Where a pool starts is set on page 2, OSC: DEGREE moves it up the scale from the chord's root, OCTAVE moves it by octaves.

### Rhythm

Knobs | Function | Settings | Power-on | What it does
1 2 3 | DIVISION | 1/11/21/41/4T1/81/8T1/161/16T1/32 | 1/4, 1/8, 1/16 | The length of one step, as a note value of the tempo. T is a triplet: three steps in the time of two.
4 5 6 | LENGTH | 1 to 16 steps | 8, 8, 6 | How many steps before the pattern starts over. Give the oscillators different lengths and their patterns slide against each other, lining up again only now and then.
7 8 9 | GATE | 0 to 100 | 50 | How long each note is held, as a share of its step: short for staccato, full for legato. It matters most when the amp envelope has some SUSTAIN (page 4).

### Chance

Knobs | Function | Settings | Power-on | What it does
1 2 3 | DENSITY | none to every step, shown as 3/8 | 8/8, 8/8, 4/6 | How many of the pattern's steps play. The hits are spread as evenly as possible (a Euclidean rhythm), and the same steps play every time round: a pattern, not a dice roll.
4 5 6 | VARY | 0 to 100 | 0 | The chance that a step plays a random note from its pool instead of the next one.
7 8 9 | RATCHET | 0 to 100 | 0 | The chance that a step splits into 2 to 4 quick repeats of its note.

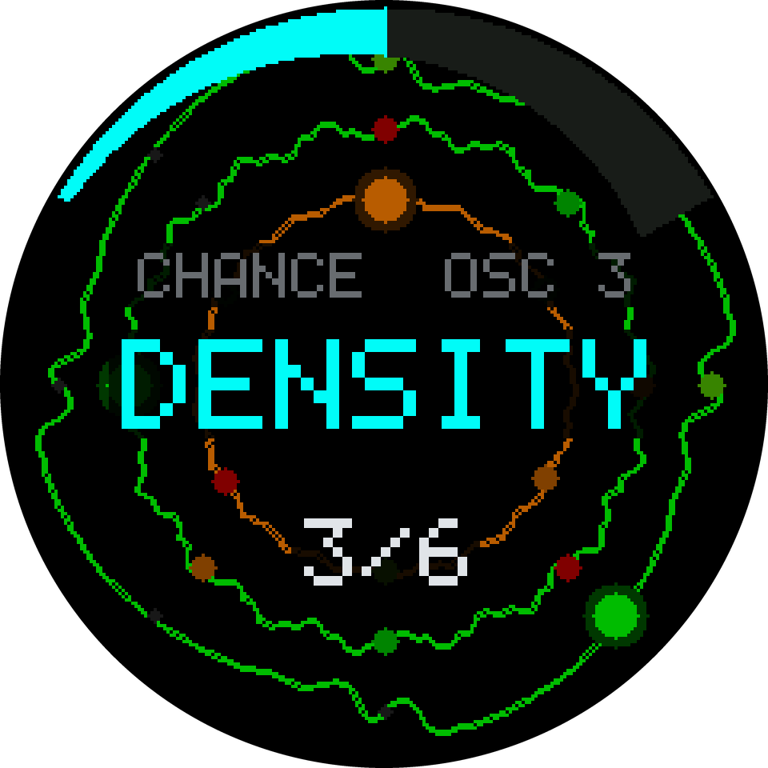
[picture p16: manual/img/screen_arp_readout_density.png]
DENSITY readout


Turning a knob shows its readout: section, oscillator, name and value. Here OSC 3's DENSITY is at 3/6: three of its six steps play.

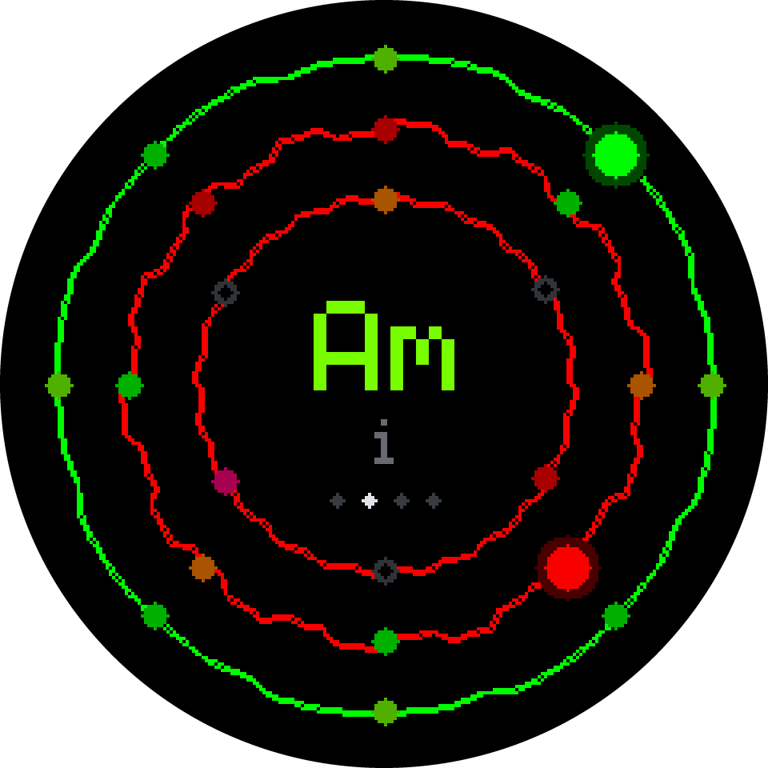
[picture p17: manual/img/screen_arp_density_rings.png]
The rings with rests


A few seconds later the readout fades. The inner ring (OSC 3) now shows its three rests as hollow dots, spaced evenly around the ring.

Try this

- A classic off-beat. On OSC 1 set LENGTH 8 and DENSITY 3/8: the tresillo, the 3-3-2 rhythm under half of all pop music.
- Patterns that drift. Set DIVISION to 1/8 on all three oscillators and LENGTH to 8, 7 and 5. The three patterns only line up again after 280 steps.
- A little life. On the fastest oscillator, raise VARY to about 20 and RATCHET to about 10.

4

Page 4 · three sections

# ENVELOPE

What happens inside each note: how its volume rises and falls, how the filter opens with it, and how its pitch arrives.

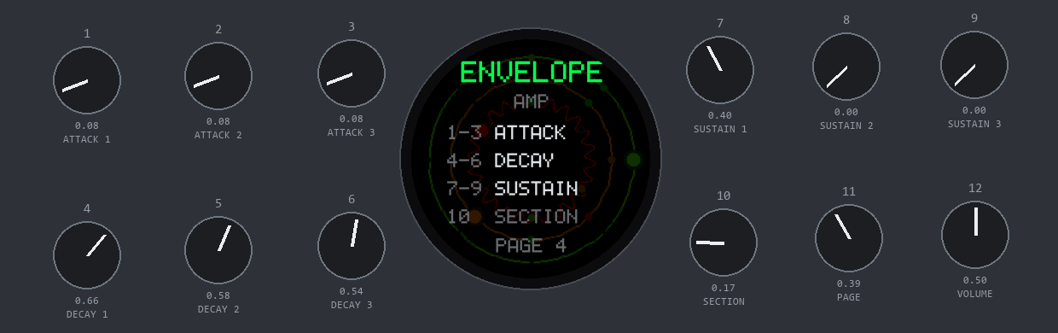
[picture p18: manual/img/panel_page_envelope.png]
Page 4, ENVELOPE


Page 4 just chosen, AMP section. Knob 10 switches between AMP, FILTER and PITCH.

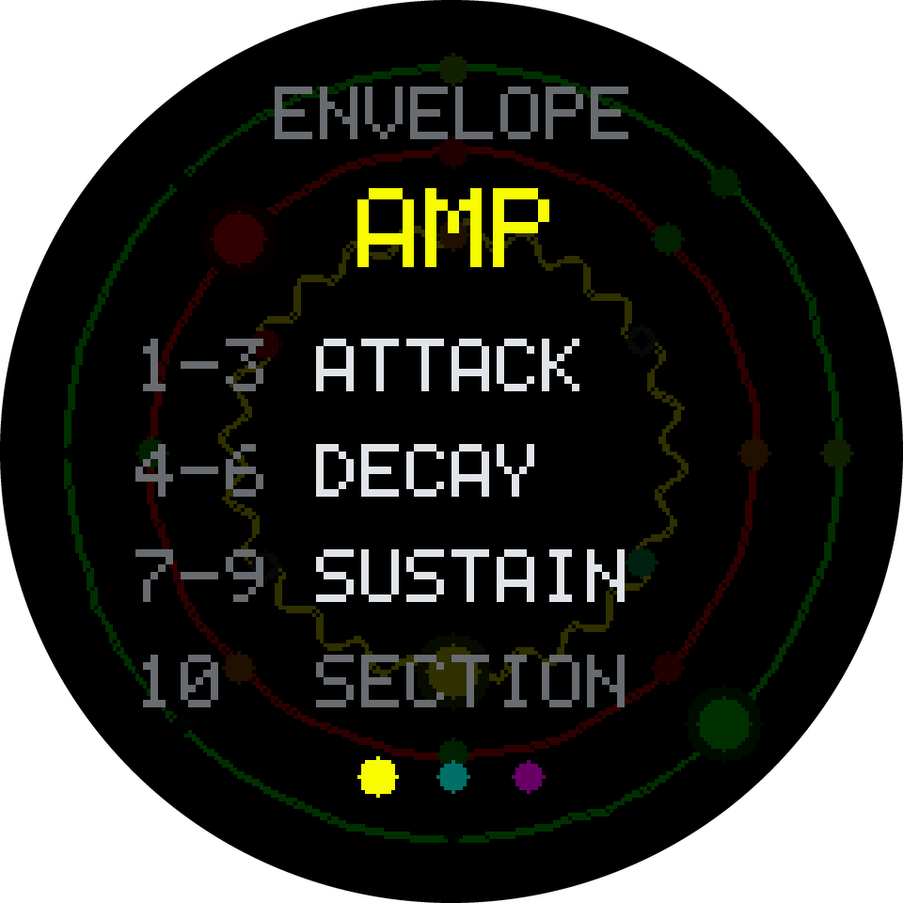
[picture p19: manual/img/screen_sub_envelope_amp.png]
AMP section


AMP
volume of each note

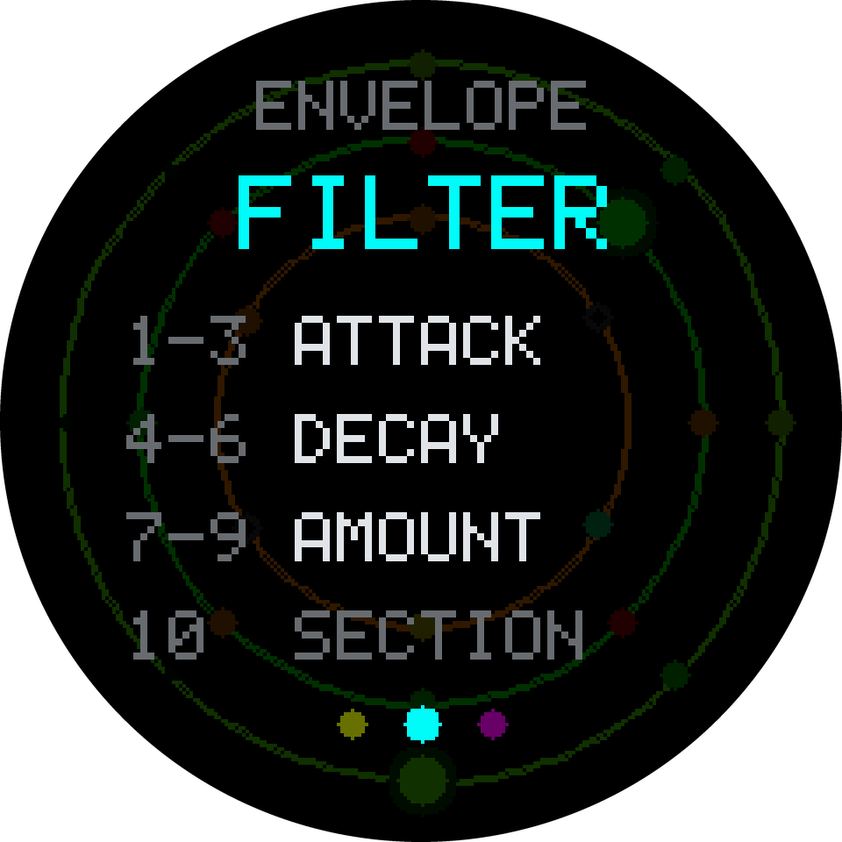
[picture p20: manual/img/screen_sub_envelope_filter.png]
FILTER section


FILTER
a filter sweep per note

PITCH section

PITCH
how each note arrives

### Amp

Knobs | Function | Settings | Power-on | What it does
1 2 3 | ATTACK | 1 MS to 4.1 S | 2 MS | How long a note takes to reach full volume. Short is a click-free hit; long is a swell.
4 5 6 | DECAY | 5 MS to 4.0 S | 401, 249, 180 MS | How long it takes to fall to the SUSTAIN level, and also how long the note takes to fade out once its GATE ends.
7 8 9 | SUSTAIN | 0 to 100 | 40, 0, 0 | The level a note holds while its GATE (page 3) lasts. 0 makes every note a pluck that dies away over DECAY.

A new note starts from wherever the last one had got to, so fast patterns never click. An oscillator whose MODE is OFF (a drone) fades in over ATTACK and then holds.

### Filter

Knobs | Function | Settings | Power-on | What it does
1 2 3 | ATTACK | 1 MS to 4.1 S | 2 MS | How long the filter takes to open to its peak after each note starts.
4 5 6 | DECAY | 5 MS to 4.0 S | 249 MS | How long it takes to close back to the CUTOFF set on page 5.
7 8 9 | AMOUNT | −4.0 to +4.0 OCT | +0.0 OCT | How far each note moves the cutoff. Positive opens it (brighter at the start of the note), negative closes it (the note starts dark and opens up). 0 switches it off.

### Pitch

Knobs | Function | Settings | Power-on | What it does
1 2 3 | AMOUNT | −12 to +12 ST | +0 ST | Each note starts this many semitones away from its pitch and slides into place.
4 5 6 | DECAY | 5 MS to 997 MS | 24 MS | How long that slide takes. A few milliseconds makes a click or a bell-like ping; longer makes a swoop.
7 8 9 | GLIDE | 0 MS to 1.0 S | 0 MS | Portamento: each arp note slides from the last one instead of jumping. Drones always slide a little (about 0.4 s) when the chord changes; a longer GLIDE slows that too.

Try this

- Pads. ATTACK around 1 S, SUSTAIN 80, GATE 100 on page 3, and a slow DIVISION such as 1/2.
- Squelch. FILTER AMOUNT +3.0 OCT, FILTER DECAY about 150 MS, with CUTOFF low and RESO high on page 5.
- Bells. SHAPE 0 on page 2, PITCH AMOUNT +12 ST, PITCH DECAY 8 MS, AMP DECAY about 900 MS. See the recipe on p. 00.

5

Page 5 · one column per oscillator

# FILTER

Each oscillator has its own filter: the main way to make it brighter or darker, thinner or rounder.

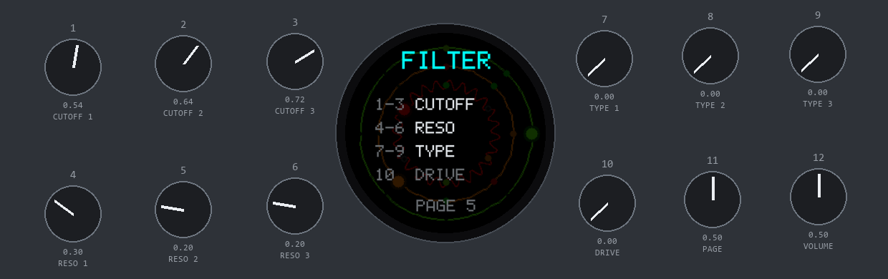
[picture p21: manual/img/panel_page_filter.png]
Page 5, FILTER


Page 5. CUTOFF, RESO and TYPE per oscillator; knob 10 is DRIVE, shared.

Knobs | Function | Settings | Power-on | What it does
1 2 3 | CUTOFF | 80 HZ to 12.0 KHZ | 1.2, 2.0, 3.0 KHZ | The filter's frequency. For the low-pass type: lower is darker and softer.
4 5 6 | RESO | 0 to 100 | 30, 20, 20 | Resonance: a peak at the cutoff. Higher values whistle and sing, especially when the cutoff moves.
7 8 9 | TYPE | LPLP-BPBPBP-HPHP | LP | A smooth morph from low-pass (keeps the lows) through band-pass (a narrow, nasal band) to high-pass (keeps the highs, thin and airy).
10 | DRIVE | 0 to 100 | 0 | Pushes all three oscillators into soft saturation before their filters: warmer, then grittier. The level stays roughly the same.

Four things move the cutoff. The CUTOFF knob here sets where each filter rests. On top of it come the master CUTOFF on page 1 (all three at once), the FILTER envelope on page 4 (with every note) and the CUTOFF LFO on page 6 (slowly, or not so slowly). They add up, so a filter can move a long way.

Try this

- TYPE BP with RESO around 60 turns a saw into a vowel-like, talking sound.
- Put OSC 3 on HP: its high arp becomes a thin shimmer over the others.

CUTOFF readout

Knob 2 turned: OSC 2's CUTOFF at 1.5 KHZ.

6

Page 6 · five targets

# LFO

Movement. Each oscillator has five LFOs, one for each thing they can move: pitch, cutoff, volume, pan and shape. That is fifteen in all, each with its own speed.

Page 6, LFO

Page 6, PITCH target. Knob 10 is called TARGET here: it picks what the LFOs on knobs 1–9 move.



PITCH



CUTOFF



AMP



PAN



SHAPE

Every target has the same three rows. At power-on every DEPTH is 0, so the dots of the other targets are grey: an LFO does nothing until you raise its DEPTH.

Knobs | Function | Settings | Power-on | What it does
1 2 3 | RATE | 0.02 to 20.0 HZ; with LFO SYNC on TEMPO: 4 BARS2 BARS1 BAR1/21/41/4T1/81/8T1/16 | 0.32 HZ (CUTOFF: 0.09, 0.13, 0.17 HZ) | How fast the LFO cycles: from about once a minute to a buzz. With LFO SYNC (page 9) set to TEMPO, RATE picks a note length instead, and the LFO locks to the bar.
4 5 6 | DEPTH | 0 to 100 | 0 | How much it moves its target (table below).
7 8 9 | WAVE | SINETRISAWSQUARES+HDRIFT | SINE | The movement's shape. S+H jumps to a new random value each cycle; DRIFT wanders smoothly from one random value to the next.

Target | At DEPTH 100 | Sounds like
PITCH | up and down one semitone | vibrato, or a seasick wobble when slow
CUTOFF | three octaves either way | a filter that breathes or wah-wahs
AMP | dips all the way to silence (never louder) | tremolo, or a chopped gate with SQUARE
PAN | swings from full left to full right | notes moving around the room
SHAPE | 50 either side of the SHAPE setting | a tone that keeps changing color

Try this

- Slow life. CUTOFF target, DEPTH about 30 on all three: the power-on rates are slow and all different, so the three filters drift in and out of step.
- Rhythmic chop. Set LFO SYNC to TEMPO on page 9, then AMP target, RATE 1/8, WAVE SQUARE, DEPTH 100 on a drone.
- Wide arps. PAN target, WAVE S+H, RATE about 4 HZ: every few notes land somewhere new in the stereo field.

7

Page 7 · two sections

# DELAY

Each oscillator has its own stereo echo, timed to the tempo. Three delays, three different rhythms of repeats.

Page 7, DELAY

Page 7, TIME section. Knob 10 switches between TIME and COLOR. All the SENDs start at 0: turn one up to hear its echo.

TIME section

TIME
when the echoes come

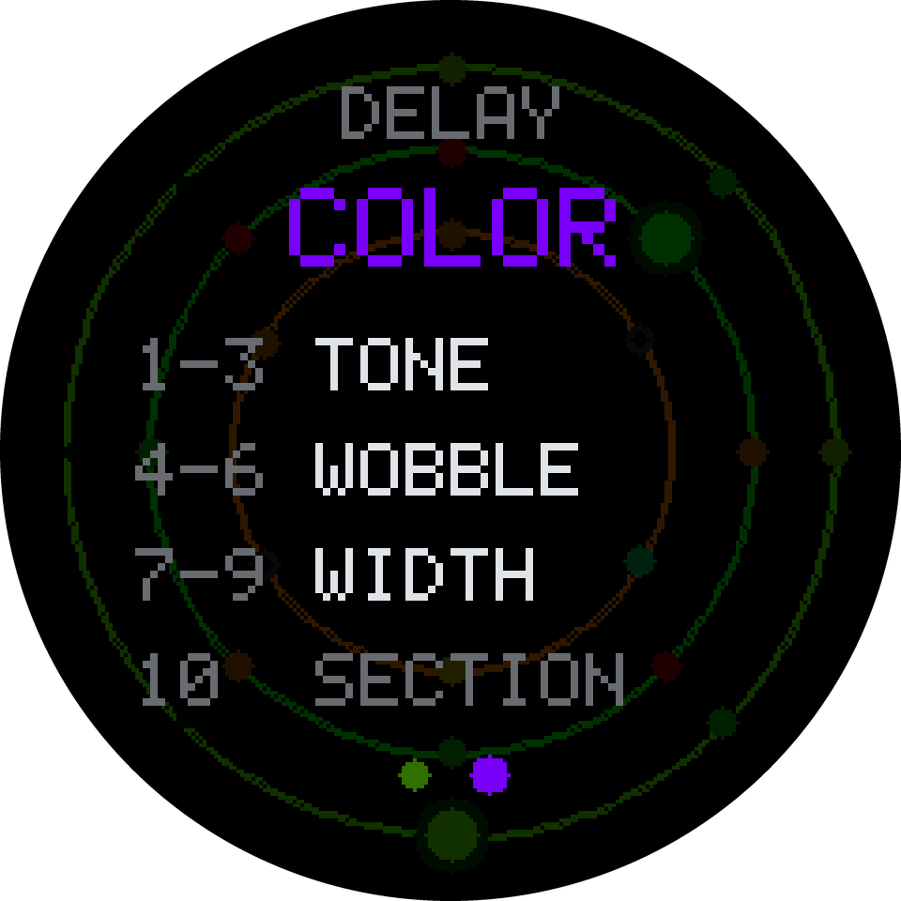
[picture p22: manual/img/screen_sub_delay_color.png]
COLOR section


COLOR
what they sound like

Each echo is fed from its oscillator after the pan, so it starts in the same place in the stereo field. The echoes also go on to the reverb with the dry sound. The master DELAY knob on page 1 scales all three SENDs at once.

### Time

Knobs | Function | Settings | Power-on | What it does
1 2 3 | DIVISION | 1/321/161/16T1/81/8T1/8.1/41/4T1/4.1/21/1 | 1/8., 1/4, 1/8T | The time between echoes as a note value of the tempo. A dot (1/8.) is one and a half times as long: the classic dotted echo that bounces off the beat.
4 5 6 | FEEDBACK | 0 to 100 | 40 | How much of each echo comes back again: a single repeat at 0, a long tail near 100.
7 8 9 | SEND | 0 to 100 | 0 | How much of the oscillator goes into its delay. At 0 the delay is off.

### Color

Knobs | Function | Settings | Power-on | What it does
1 2 3 | TONE | 500 HZ to 12.0 KHZ | 4.0 KHZ | Each repeat passes through a gentle low-pass: lower settings make the echoes darker and darker as they fade, like tape.
4 5 6 | WOBBLE | 0.0 to 3.0 MS | 0.9 MS | A slow, random wander in the delay time, the way a tape machine drifts. It bends the pitch of the echoes slightly.
7 8 9 | WIDTH | 0 to 100 | 100 | At 0 the echoes stay where the oscillator is panned. At 100 they ping-pong: left, right, left.

Try this

- Delay only the slowest oscillator, with a dotted DIVISION: the echoes fill the gaps between its notes.
- FEEDBACK 80, TONE 1.5 KHZ, WOBBLE 2 MS: a dark dub echo that sinks away (see the recipe Dub echoes).

8

Page 8 · one column per oscillator

# MIX

Where each oscillator sits in the stereo picture, and how much of it goes to the reverb.

Page 8, MIX

Page 8. PAN, WIDTH and REV SEND per oscillator; knob 10 is the reverb's SIZE.

Knobs | Function | Settings | Power-on | What it does
1 2 3 | PAN | L100, C, R100 | C, L40, R40 | Left to right. OSC 1 starts in the middle, the other two to either side.
4 5 6 | WIDTH | 0 to 100 | 0 | Spreads the oscillator's two detuned halves apart, one left and one right. Wide and shimmering with some DETUNE (page 2); at 0 the oscillator is a single point.
7 8 9 | REV SEND | 0 to 100 | 0 | How much of the oscillator, echoes included, goes into the reverb. At 0 it stays dry.
10 | SIZE | 0 to 100 | 75 | The reverb's size and length, from a small room to a long hall.

There is one reverb, shared by all three. Its tone is set on page 9 (DAMPING, PREDELAY) and the master REVERB knob on page 1 scales all three sends at once.

Try this

- Send only the high OSC 3 to the reverb, at about 60, with SIZE 90: a halo above a dry, punchy low end.
- DETUNE 15 on page 2 and WIDTH 100 on all three: the power-on patch becomes a wide stereo wash.

9

Page 9 · whole instrument

# KEY

Chord progressions, tuning, a few reverb details, and which picture the screen shows.

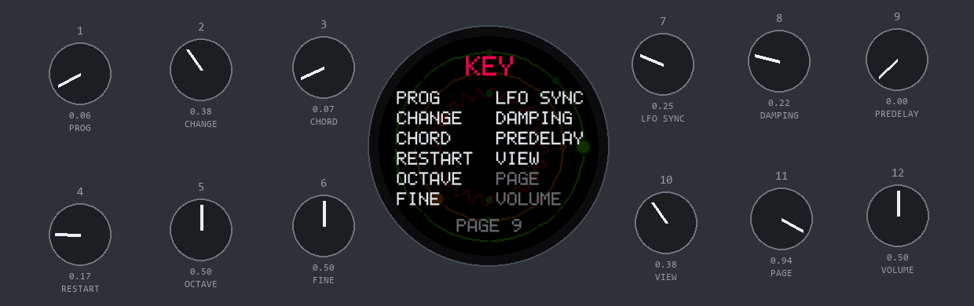
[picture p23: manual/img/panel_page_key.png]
Page 9, KEY


Page 9. Like MAIN, a whole-instrument page with a separate job for every knob.

Knob | Function | Settings | Power-on | What it does
1 | PROG | OFFPOP50SSADEPICJAZZVAMPCANONFALL | OFF | A chord progression that steps along by itself (table below). OFF holds the chord set by CHORD.
2 | CHANGE | 1/2 BAR1 BAR2 BARS4 BARS | 1 BAR | How long each chord of the progression lasts. Changes always land on the beat.
3 | CHORD | I to VII | I | With PROG OFF: the chord to play, by its place in the key. Play your own progression by turning it.
4 | RESTART | FREEBARCHORD | FREE | When every pattern jumps back to its first step. FREE: never, the patterns run on and drift. BAR: at every bar line. CHORD: at every chord change.
5 | OCTAVE | −2 to +2 | +0 | Moves the whole instrument up or down by octaves.
6 | FINE | −50 to +50 CT | +0 CT | Fine tuning, up to a quarter-tone either way, to play along with a record or another instrument.
7 | LFO SYNC | FREETEMPO | FREE | TEMPO locks all fifteen LFOs to the master clock, with RATE picking a note length (page 6).
8 | DAMPING | 12.0 KHZ to 1.0 KHZ | 6.9 KHZ | The reverb's tone: turn right for a darker, softer reverb.
9 | PREDELAY | 0 to 250 MS | 0 MS | A gap before the reverb starts. Keeps notes clear in front of a big reverb.
10 | VIEW | RINGSPITCHWHEELSCOPE | PITCH | What the screen shows (p. 00).

## The progressions

PROG | Degrees | In A minor (power-on) | In C major
POP | 1 5 6 4 | Am Em F Dm | C G Am F
50S | 1 6 4 5 | Am F Dm Em | C Am F G
SAD | 6 4 1 5 | F Dm Am Em | Am F C G
EPIC | 1 6 3 7 | Am F C G | C Am Em Bdim
JAZZ | 2 5 1 1 | Bdim Em Am Am | Dm G C C
VAMP | 1 4 | Am Dm | C F
CANON | 1 5 6 3 4 1 4 5 | Am Em F C Dm Am Dm Em | C G Am Em F C F G
FALL | 1 7 6 5 | Am G F Em | C Bdim Am G

A progression running

POP running in A minor, on its third chord: F, degree VI, chord 3 of 4. The four dots are the beats of the bar.

A progression is written in scale degrees, so it works in any key: ROOT and SCALE on page 1 still transpose it while it runs. The chord changes on the bar line; a note already sounding finishes, and the next one uses the new chord. With a chord key (SCALE set to MAJ, MIN7 and so on) every chord of the progression takes that chord's quality.

The screen

# Reading the rings

The screen shows what the three arps are playing, as it happens. Once you can read it, you can see a pattern before you hear it.

1. OSC 1 is the outer ring.
2. OSC 2 is the middle ring.
3. OSC 3 is the inner ring. Each ring is cut into as many arcs as its oscillator's LENGTH, starting at 12 o'clock and running clockwise. One arc is one step.
4. The playing step is the big dot with a halo. It moves on one arc with every step.
5. A rest is a hollow dot on a grey arc: a step that DENSITY leaves out.
6. The line is the sound itself. It is the oscillator's real waveform: it swells when a note starts and flattens as it fades, and higher notes fit more waves round the ring. A drone is one unbroken ring.
7. The chord playing now, in the color of its root note.
8. Its numeral in the key. Lowercase means minor. When a progression runs, its place in it follows, e.g. 3/4.
9. The beat: one dot for each beat of the bar.

## Colors are notes

Note colors around the circle of fifths

Every note has its own color, the same in every octave and on every view. The colors run around the circle of fifths: notes a fifth apart get neighboring colors.

That puts notes that sound good together close in color. A root and its fifth (the two notes of a FIFTHS pool) always look alike, and each chord of a progression brings its own mix of colors to the screen.

The wheel is drawn on black because the brightest colors, yellow and cyan, vanish on white paper. On the screen they glow.

## Four views page 9 KEY, knob 10 VIEW

The same music can be drawn four ways. Pick one with VIEW; the readout and page maps look the same on all of them.

PITCH view

#### PITCH power-on

The rings, with each whole ring in the color of the note its oscillator is playing right now. As the arp moves, the ring changes color: you watch the melody.

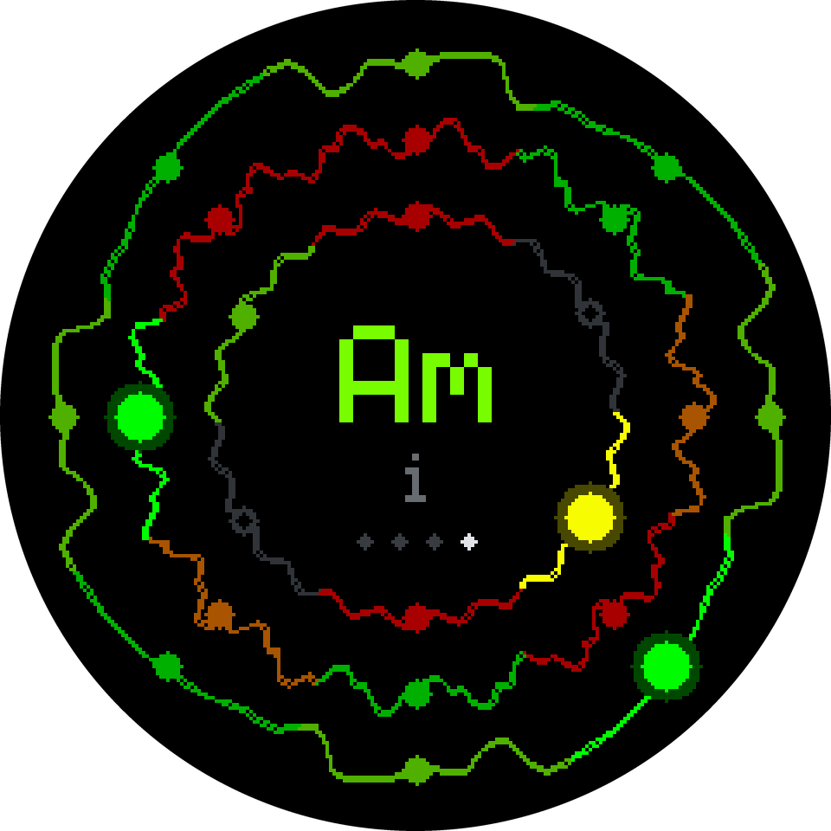
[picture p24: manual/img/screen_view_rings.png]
RINGS view


#### RINGS

Each arc keeps the color of the note on its step, so the whole pattern is on screen at once, and you see it change when the chord does.

WHEEL view

#### WHEEL

The twelve notes around the circle of fifths, C at the top. The chord's notes are joined into a shape: its outline shows the kind of chord. Each oscillator's note is a bright dot (biggest for OSC 1), nearer the rim the higher it plays.

SCOPE view

#### SCOPE

The three waveforms drawn over each other, each in its note's color. The plainest view, and the best for hearing what SHAPE and the filter do.

Five patches

# Recipes

Each recipe starts from the power-on sound, so switch Ammonite off and on first (with knob 11 on page 1). Then make the settings in any order.

The values are exactly what the screen's readout shows when the knob is right. The three columns are OSC 1, 2 and 3; a grey dash means leave that one alone.

Appendix

# Scales and chords

Every SCALE setting on page 1, spelled out from C. Turn ROOT and the same pattern starts from another note.

### Scales

SCALE | Notes from C | Character
MAJOR | C D E F G A B | bright, settled
MINOR | C D D# F G G# A# | dark; the power-on key
DORIAN | C D D# F G A A# | minor with a lift; soul and jazz
PHRYGIAN | C C# D# F G G# A# | dark and tense, Spanish flavor
LYDIAN | C D E F# G A B | major, floating and dreamy
MIXO | C D E F G A A# | major with a bluesy seventh
HARM MIN | C D D# F G G# B | minor with a dramatic leading note
PENTA | C D E G A | five notes, no clashes at all
PENTA MI | C D# F G A# | the minor five-note scale
BLUES | C D# F F# G A# | minor pentatonic plus the blue note

### Chord keys

Past BLUES, SCALE turns into a chord. Then POOL KEY plays that chord's notes, and a progression moves the chord through its parent scale (natural minor for MIN, MIN7 and DIM; major for the rest), keeping its quality: a MIN7 key gives a progression of minor sevenths.

SCALE | Notes from C | Character
MAJ | C E G | plain major triad
MIN | C D# G | plain minor triad
SUS2 | C D G | open, neither major nor minor
SUS4 | C F G | open, waiting to resolve
MAJ7 | C E G B | soft, jazzy major
MIN7 | C D# G A# | smooth minor
DOM7 | C E G A# | bluesy, restless
DIM | C D# F# | tense, spooky
AUG | C E G# | strange, dreamlike
ADD9 | C D E G | bright and airy

Appendix

# Cheat sheet

Every knob on every page. Knob 11 is always PAGE, knob 12 always VOLUME.

Page | Section | Knobs 1–3 | Knobs 4–6 | Knobs 7–9 | Knob 10
1MAIN | whole instrument | 1–3 LEVEL | 4 ROOT · 5 SCALE · 6 TEMPO | 7 CUTOFF · 8 DELAY · 9 REVERB | SWING
2OSC | | SHAPE | OCTAVE | DEGREE | DETUNE
3ARP | NOTES | MODE | POOL | RANGE | SECTION
3ARP | RHYTHM | DIVISION | LENGTH | GATE
3ARP | CHANCE | DENSITY | VARY | RATCHET
4ENVELOPE | AMP | ATTACK | DECAY | SUSTAIN | SECTION
4ENVELOPE | FILTER | ATTACK | DECAY | AMOUNT
4ENVELOPE | PITCH | AMOUNT | DECAY | GLIDE
5FILTER | | CUTOFF | RESO | TYPE | DRIVE
6LFO | PITCH · CUTOFF · AMP · PAN · SHAPE | RATE | DEPTH | WAVE | TARGET
7DELAY | TIME | DIVISION | FEEDBACK | SEND | SECTION
7DELAY | COLOR | TONE | WOBBLE | WIDTH
8MIX | | PAN | WIDTH | REV SEND | SIZE
9KEY | whole instrument | 1 PROG · 2 CHANGE · 3 CHORD | 4 RESTART · 5 OCTAVE · 6 FINE | 7 LFO SYNC · 8 DAMPING · 9 PREDELAY | VIEW

On pages 2 to 8 each row's three knobs are OSC 1, 2 and 3, left to right, in both groups. Turning knob 10 on a page with sections, or knob 11, never changes the sound; a knob takes over (and its setting jumps to it) when you turn it.

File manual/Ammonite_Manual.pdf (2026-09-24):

# A M M O N I T E

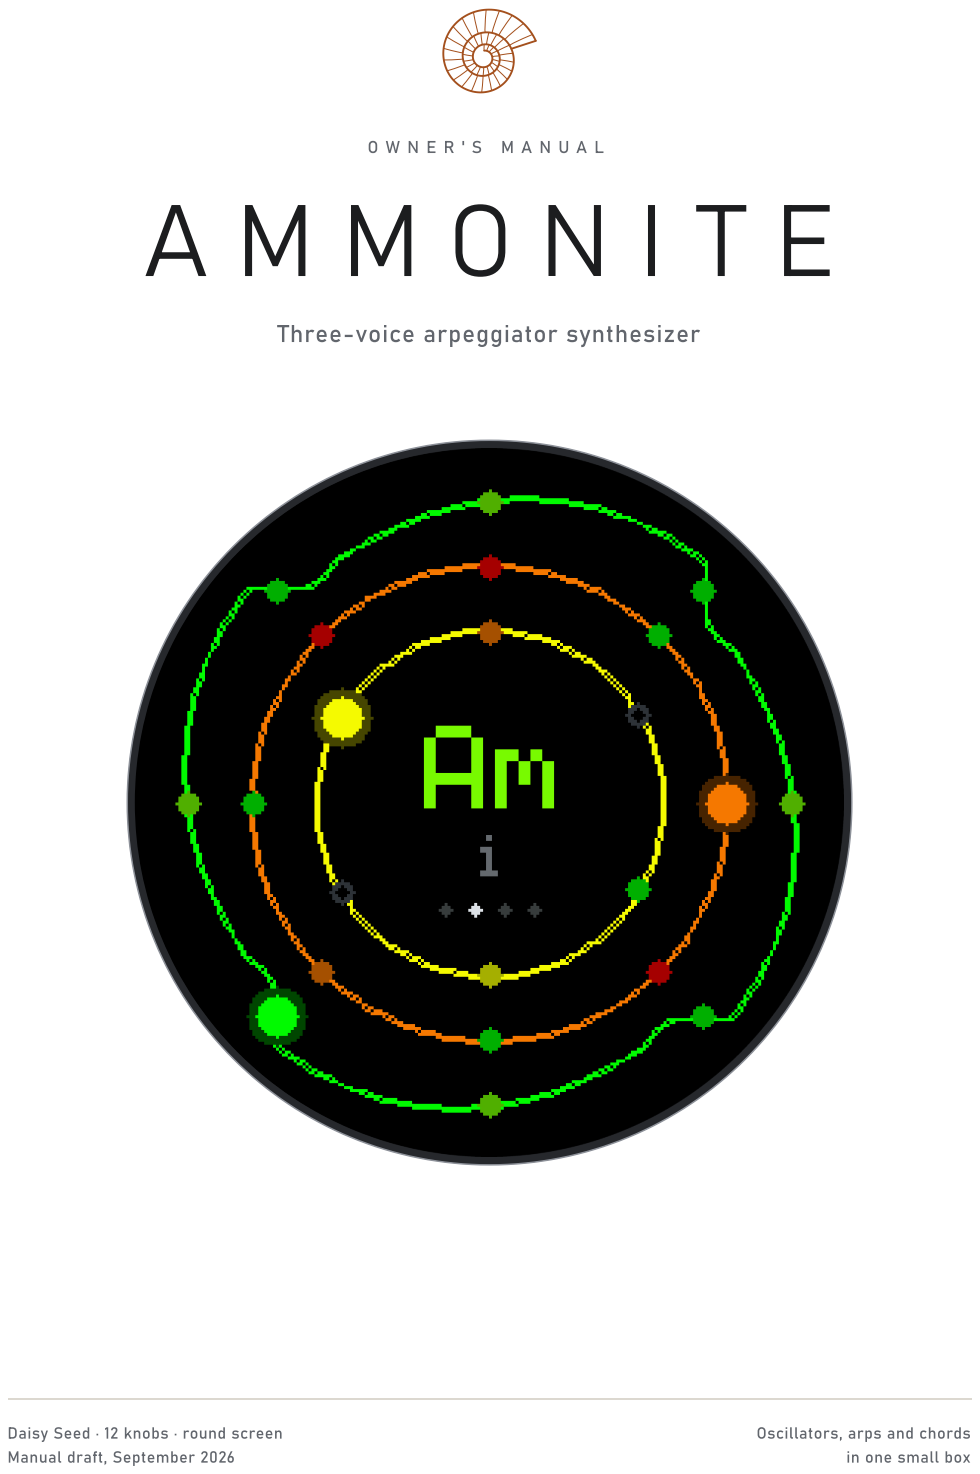
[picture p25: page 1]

Three-voice arpeggiator synthesizer

Daisy Seed · 12 knobs · round screen

Oscillators, arps and chords

Manual draft, September 2026

in one small box

Ammonite · Owner's manual | 2

# CO N T E N T S

Every screen picture in this manual comes straight from Ammonite's own code: it is exactly what the round screen shows. A word on words: page always means one of Ammonite's nine
knob pages (page 3 ARP); p. 12 means a page of this booklet.
Quick start from power to your own pattern | 3
The panel pages, columns, sections, and how knobs take over | 4
How Ammonite plays three voices, one key, one clock | 6

The nine pages

1 | MAIN | levels, key, tempo, masters | 8
2 | OSC | shape and pitch | 10
3 | ARP | notes, rhythm, chance | 11
4 | ENVELOPE | amp, filter and pitch envelopes, glide | 13
5 | FILTER | cutoff, resonance, type, drive | 15
6 | LFO | fifteen LFOs, five targets | 16
7 | DELAY | one echo per oscillator | 18
8 | MIX | pan, width, reverb | 20
9 | KEY | progressions, tuning, view | 21
Reading the screen rings, colors, four views | 23
Recipes five patches to start from | 25
Scales and chords every SCALE setting, spelled out | 30
Cheat sheet every knob on one page | 31

S T A R T H E R E

## Quick start

### Ammonite plays the moment it has power. Five minutes from here you will have changed

its key, its tempo and its chords.

Power-on. Knob 11 points at page 1, MAIN. The screen shows the three arps as rings (see Reading the screen, p. 23).

T W O T H I N G S W O R T H K N O W I N G N O W
Changing page never changes the sound. But when you then touch a knob, its setting jumps to where the knob points. The whole story is on p. 4.
Nothing is saved. Switch off and on, and Ammonite starts again from its power-on sound, with one exception: the page knob 11 points at when you switch on takes its settings from where its knobs are. With knob 11 on page 1, that means the levels, key, tempo and masters start where you left the knobs.

Turn it down, then plug in. Turn knob 12 (VOLUME) to the left, connect the stereo output to your amp, mixer or speakers, and power Ammonite from USB. Then bring VOLUME up.

1

Listen. Three arpeggios in A minor at 110 BPM. OSC 1 plays the low root and fifth in quarter notes, OSC 2 runs up and down the chord in eighths, OSC 3 picks random notes of the scale in sixteenths, leaving a few steps out. No effects are on yet.

2

Change the tempo. Turn knob 6 , TEMPO. The screen shows what you are turning and its value, then fades back to the rings.

3

Change the key. Knob 4 | is ROOT, knob 5 | is SCALE. Try DORIAN or PENTA. All three arps follow at once;
nothing can play a wrong note.

4

Let the chords move. Turn knob 11 all the way right, to page 9, KEY. Turn knob 1 (PROG) to POP. Now the chord changes every bar, and every arp follows it.

5

Add echoes and space. Knob 11 to page 7, DELAY: turn up knobs 7 – 9 , the delay SEND of each oscillator. Then page 8, MIX: knobs 7 – 9 are the reverb sends.

6

## The panel

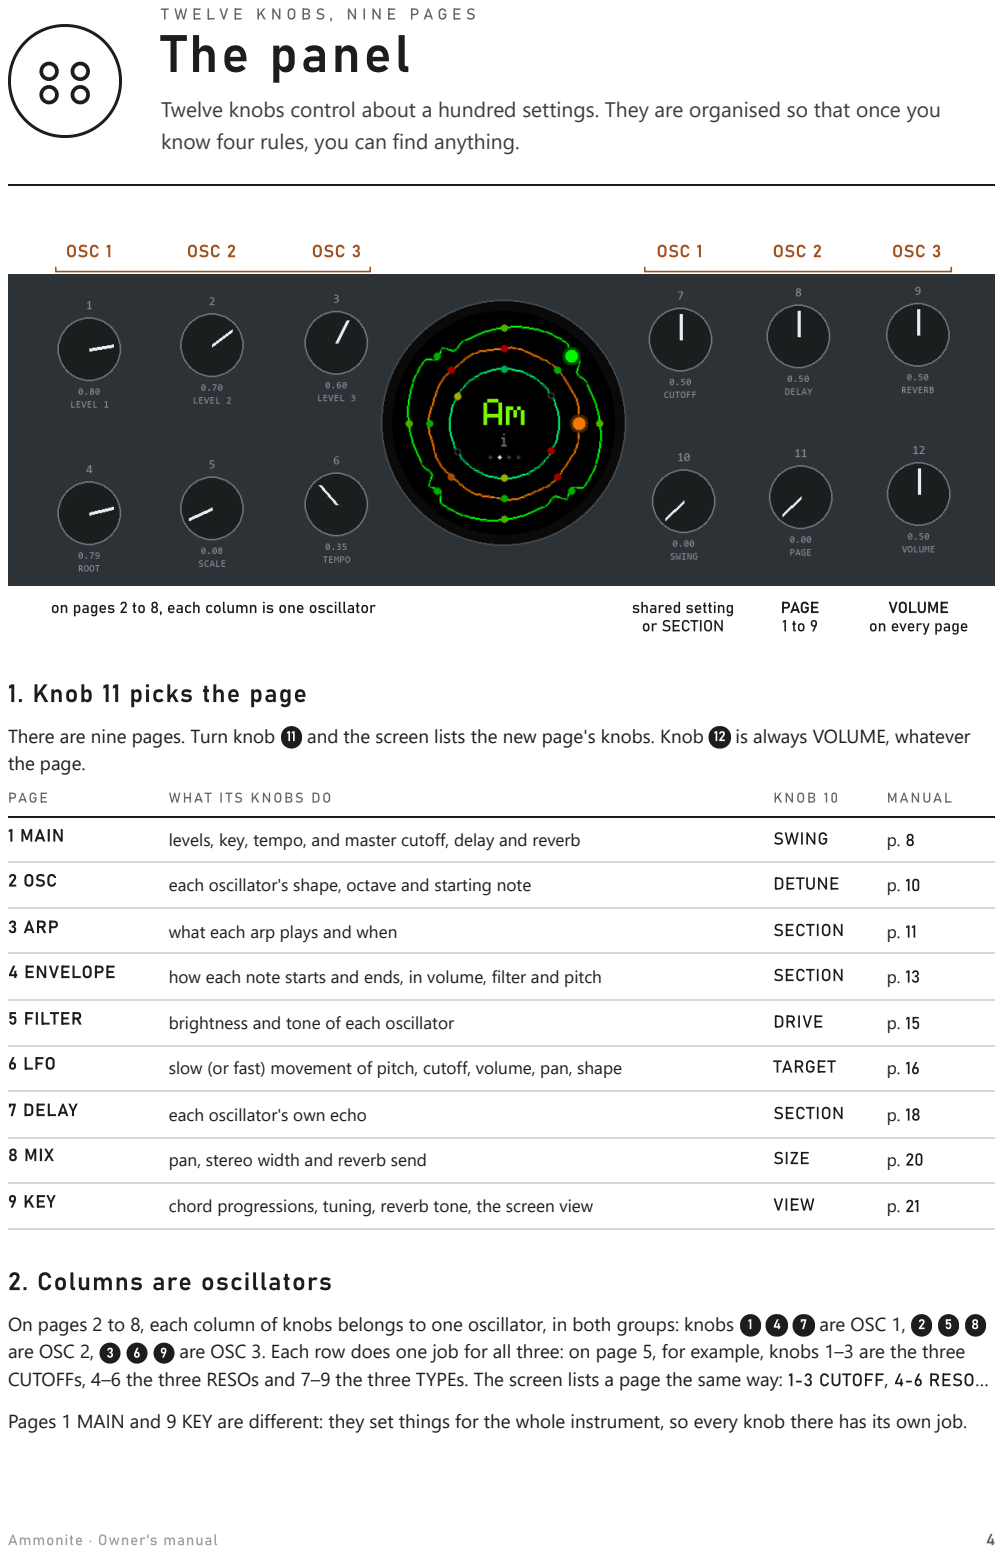
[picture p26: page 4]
OSC 1; OSC 2; OSC 3; shared setting; or SECTION; PAGE; W HAT I TS K N OBS DO; MA N UAL; 1 MAIN; levels, key, tempo, and master cutoff, delay and reverb; SWING; 2 OSC; each oscillator's shape, octave and starting note; DETUNE; 3 ARP; what each arp plays and when; SECTION; 4 ENVELOPE; how each note starts and ends, in volume, filter and pitch; 5 FILTER; brightness and tone of each oscillator; DRIVE; 6 LFO; slow (or fast) movement of pitch, cutoff, volume, pan, shape; TARGET; 7 DELAY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

Twelve knobs control about a hundred settings. They are organised so that once you
know four rules, you can find anything.

on pages 2 to 8, each column is one oscillator

VOLUME
on every page

1. Knob 11 picks the page
There are nine pages. Turn knob 11 and the screen lists the new page's knobs. Knob 12 is always VOLUME, whatever
the page.

2. Columns are oscillators
CUTOFFs, 4–6 the three RESOs and 7–9 the three TYPEs. The screen lists a page the same way: 1-3 CUTOFF, 4-6 RESO…
Pages 1 MAIN and 9 KEY are different: they set things for the whole instrument, so every knob there has its own job.

3. Knob 10 is shared, or picks a section
On most pages knob 10 is one setting shared by all three oscillators (DETUNE, DRIVE, SIZE…). On four pages there is more to control than nine knobs can hold, so the page is split into sections and knob 10 chooses one: ARP, ENVELOPE and DELAY call it SECTION, LFO calls it TARGET. Choosing a section only changes what knobs 1–9 control. It never changes the sound.
4. A knob takes over when you turn it
Every knob on every page and section remembers its own setting. When you change page (or section) the knobs themselves stay where they are, so most of them now point somewhere other than the setting they control. Ammonite leaves every setting alone until you turn its knob. The moment you do, the setting jumps to where the knob points, and from then on follows it.
So glance at a knob's pointer before you turn it. If it points far from where the sound is, expect a jump. A tiny wobble does not count as a turn, so brushing a knob does nothing.

The screen tells you what you touched

Readout. Turn any knob: its name, value and a gauge. Column pages add the oscillator (and section) above the name.

Page map. Turn knob 11: the page's name and what each row of knobs does.

Section map. Turn knob 10 on a page with sections: the section, its rows, and one dot per section.

About 2.5 seconds after you let go, the text fades and the rings return. Under a section map, the bright dot is the section you are in. On the LFO page, a colored dot marks a target that is doing something (its DEPTH is up on some oscillator) and a grey dot one that is off.

T H E | I D E A S B E H I N D | T H E | K N O B S

## How Ammonite plays

### Three voices, one key and one clock. Everything on the nine pages is a detail of one of

these three.

Three voices
Ammonite has three oscillators, OSC 1 to OSC 3. Each is a complete little synth with its own arpeggiator, envelopes, filter, LFOs, echo and place in the stereo mix. They play one note at a time each, so together they make three-part music. Inside, every oscillator is really two oscillators, pulled slightly apart by DETUNE for a fuller sound.

E AC H O S C I L L A T O R , × 3

arp note, PITCH env

LFOs, GLIDE

FILTER env, LFO

master CUTOFF

AMP env

AMP LFO | PAN LFO

2 × OSC

SHAPE
DETUNE

DRIVE

shared

FILTER

CUTOFF · RESO
TYPE

AMP

envelope
× LEVEL

PAN

PAN · WIDTH

DELAY

TIME · COLOR

SEND

REV SEND

SUM

+ soft limiter

REVERB

SIZE · DAMPING
PREDELAY

VOLUME

out L / R

One key
You never choose notes on Ammonite. You choose a key (ROOT and SCALE on page 1), a chord within it, and then, for each oscillator, which of the chord's notes it may use. That set of notes is the oscillator's pool, and its arp plays from nothing else. Here is how the power-on sound gets its notes:

Key
ROOT A, SCALE MINOR
A | B | C | D | E | F | G

Chord
i, the first chord: Am
A | C | E

OSC 1 pool
DEGREE +0, FIFTHS, 1 octave
A2 | E3

OSC 2 pool
DEGREE +2, TRIAD, 2 octaves
C4 | E4 | G4 | C5 | E5 | G5

OSC 3 pool
DEGREE +4, KEY, 2 octaves
E5 | F5 | G5 | A5 | B5 | C6 | D6 | E6 | F6
G6 | A6 | B6 | C7 | D7

DEGREE (page 2) moves a pool's starting note up the scale from the chord's root: OSC 2 starts two scale steps up, on C, so its TRIAD is C E G. POOL and RANGE (page 3) say which notes to take and over how many octaves; OCTAVE (page 2) places the pool high or low. The colored dots are each note's screen color (p. 23).

When the chord changes, from a progression or from CHORD on page 9, every pool is rebuilt on the new chord, and all three oscillators move with it. SCALE can also be a chord type (MAJ, MIN7, ADD9…) instead of a scale: then the key is that chord, and a progression moves it around, keeping its color.

One clock
A single master clock (TEMPO on page 1) drives all three arps, the progression, the delay times and, if you want, the LFOs. Each arp divides the beat its own way (DIVISION), but every grid starts from the same beat, so however strange the combination, the three never drift apart.
1 | 2 | 3 | 4 | 1 | 2 | 3 | 4
B A R 1 | B A R 2

OSC 1

1/4 · LENGTH 8

OSC 2

1/8 · LENGTH 8

OSC 3

1/16 · LENGTH 6 · DENSITY 4/6

Two bars of the power-on patterns. Each block is a step; rust marks the first step of a pattern. OSC 3's pattern is 6 steps long, so it starts over at different places in each bar; its DENSITY of 4/6 leaves out the same two steps every time round (hollow).
Three things shape the rhythm beyond DIVISION. LENGTH sets how many steps a pattern has before it starts over; different lengths make patterns that slide against each other. DENSITY leaves steps out, spread as evenly as possible. SWING (page 1, knob 10) delays every second step. And RESTART on page 9 can pull every pattern back to its first step on each bar or each chord.

Arps and drones
Set an oscillator's MODE (page 3) to OFF and it stops arpeggiating: it holds a single note (the first of its pool) and slides to the new note when the chord changes. A drone ignores the amp envelope's decay: it fades in over ATTACK and then simply holds. One drone under two arps, or three drones and no arps at all, are both good ways to play Ammonite.

1

## MAIN

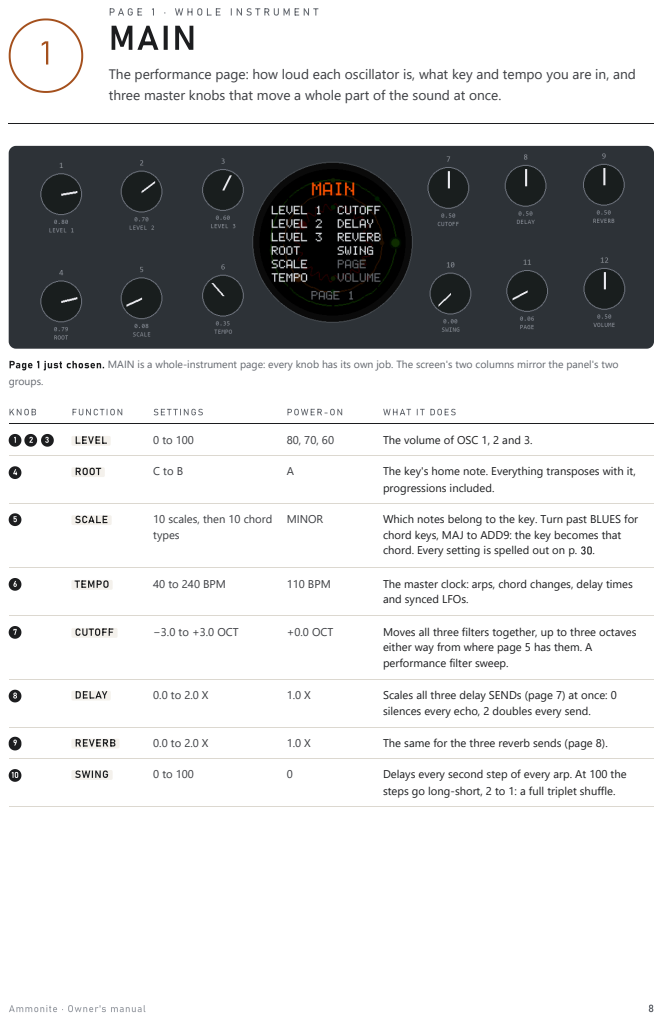
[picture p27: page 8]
FUN CT ION; POW ER-ON; W HAT I T DOES; LEVEL; The volume of OSC 1, 2 and 3.; ROOT; The key's home note. Everything transposes with it,; progressions included.; SCALE; 10 scales, then 10 chord; types; MINOR; Which notes belong to the key. Turn past BLUES for; TEMPO; 40 to 240 BPM; 110 BPM; The master clock: arps, chord changes, delay times; CUTOFF; −3.0 to +3.0 OCT; +0.0 OCT; Moves all three filters together, up to three octaves; DELAY; Scales all three delay SENDs (page 7) at once: 0; REVERB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

The performance page: how loud each oscillator is, what key and tempo you are in, and
three master knobs that move a whole part of the sound at once.

Page 1 just chosen. MAIN is a whole-instrument page: every knob has its own job. The screen's two columns mirror the panel's two
groups.

chord keys, MAJ to ADD9: the key becomes that
chord. Every setting is spelled out on p. 30.

and synced LFOs.

either way from where page 5 has them. A
performance filter sweep.

silences every echo, 2 doubles every send.

steps go long-short, 2 to 1: a full triplet shuffle.

Why the masters sit in the middle. The three master knobs multiply or shift what the other pages set. At their centre positions they change nothing, so you can dial in each oscillator's cutoff, echo and reverb carefully on pages 5, 7 and 8, then come back here and move all three together while you play.

T R Y T H I S
Turn SCALE slowly from one end to the other while the arps run. Each step is a new key; the chord keys at the far end are the most colorful. Sweep CUTOFF down to −3 and back for a whole-mix filter build. SWING at about 30 loosens sixteenths without sounding like a shuffle.
TEMPO turned to 120 BPM. Page 1 has
no columns, so the readout shows no oscillator.

2

P A G E | 2 | · | O N E | C O L U M N | P E R | O S C I L L A T O R

## OSC

What each oscillator sounds like, how high it plays, and which note of the chord it starts from.

Page 2. Row A (knobs 1–3) is SHAPE, row B (4–6) OCTAVE, row C (7–9) DEGREE; knob 10 is DETUNE, shared by all three.

K N OBS | FUN CT ION | SE T T I N GS | POW ER-ON | W HAT I T DOES
1 | 2 | 3 | SHAPE | 0 to 100 | 100, 50, 30 | The waveform, morphing smoothly: 0 a pure sine (soft, round), 50 a square (hollow, woody), 100 a saw (bright, buzzy).
4 | 5 | 6 | OCTAVE | −1 to +3 | +0, +1, +2 | Moves the oscillator's whole pool by octaves. At +0 the pool starts around the second octave (A2 at power-on); each step doubles the pitch.
7 | 8 | 9 | DEGREE | +0 to +7 | +0, +2, +4 | Where the pool starts, in steps up the scale from the chord's root. The power-on values are the chord's root, third and fifth: with every arp off, the three drone the chord.
10 | | | DETUNE | 0.0 to 20.0 CT | 8.0 CT | Each oscillator is two oscillators; DETUNE pulls them apart (in cents, hundredths of a semitone). A little gives a gentle chorus; 20 is wide and wobbly. MIX WIDTH (page 8) can spread the two apart in stereo.

T R Y T H I S
A bass line. OSC 1 at SHAPE 0 and OCTAVE −1 gives a round sub bass under the other two.
Unison. Give OSC 2 and OSC 3 the same DEGREE and OCTAVE as OSC 1, but different MODEs on page 3: three rhythms on the same notes.
Chord colors. With every arp off, try DEGREEs 0, 2, 4, 6: a seventh chord that follows the progression.

3

P A G E | 3 · | T H R E E | S E C T I O N S

## ARP

Which notes each oscillator plays, when it plays them, and how often it surprises you.

Every oscillator has its own arpeggiator. On each step it takes the next note from its pool (p. 6), a handful of notes built from the key and the chord playing now. All three arps run from one master clock, so however different their rhythms, they never drift apart.
There are too many settings for one page of knobs, so ARP has three sections. Knob 10 picks the section. Choosing a section only changes what knobs 1 – 9 control, never the sound.

The ARP page with the CHANCE section chosen. Knob 10 has just been turned, so the screen lists the section's knobs. Each column is one oscillator: knobs 1, 4 and 7 set OSC 1; knobs 2, 5 and 8 set OSC 2; knobs 3, 6 and 9 set OSC 3.

NOTES
which notes

RHYTHM
when they play

CHANCE
how often, how surprising

NOTES

K N OBS | FUN CT ION | SE T T I N GS | POW ER-ON | W HAT I T DOES
1 | 2 | 3 | MODE | OFF LOOP UP DOWN
| | | | UP-DN RANDOM

UP, UP-DN,
RANDOM

The order the arp walks through its pool. LOOP repeats one note in rhythm. OFF stops the arp: the oscillator holds a single note, a drone that slides to follow the chord.

4 | 5 | 6 | POOL | KEY TRIAD 7TH FIFTHS ROOT | FIFTHS, TRIAD, KEY | Which notes the arp may use. KEY: every note of the scale. TRIAD and 7TH: the chord's three or four notes. FIFTHS: root and fifth. ROOT: the root alone, in octaves.
7 | 8 | 9 | RANGE | 1 OCT 2 OCT 3 OCT | 1, 2, 2 OCT | How many octaves the pool spans.

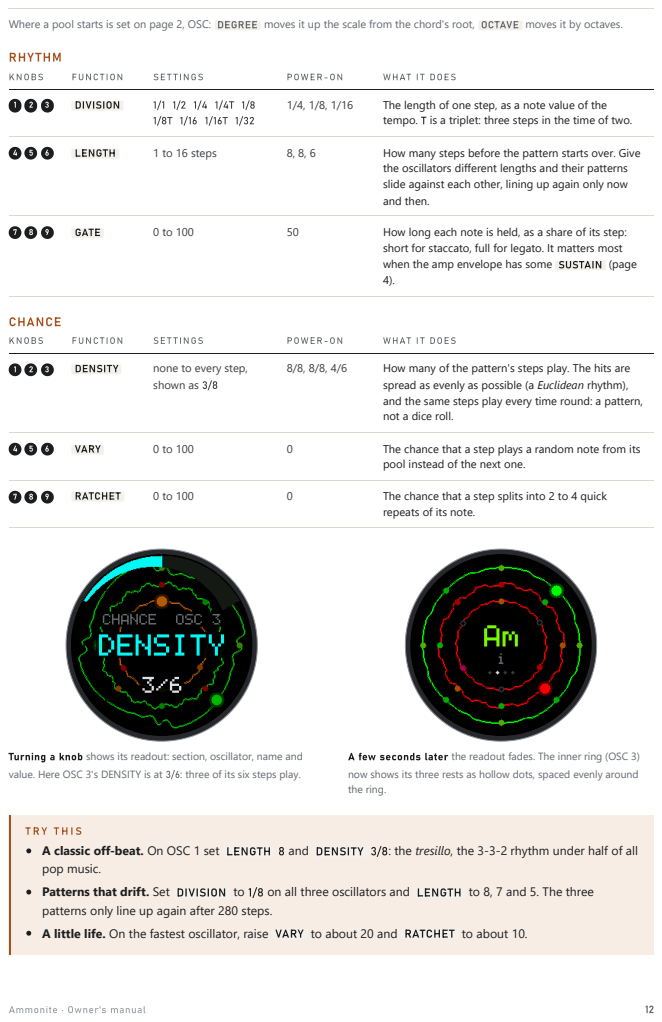
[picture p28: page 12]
RHY THM; K N OBS; FUN CT ION; POW ER-ON; W HAT I T DOES; DIVISION; The length of one step, as a note value of the; LENGTH; 1 to 16 steps; How many steps before the pattern starts over. Give; GATE; How long each note is held, as a share of its step:; CHANCE; DENSITY; none to every step,; shown as 3/8; How many of the pattern's steps play. The hits are; VARY; The chance that a step plays a random note from its; RATCHET; The chance that a step splits into 2 to 4 quick

Where a pool starts is set on page 2, OSC: DEGREE moves it up the scale from the chord's root, OCTAVE moves it by octaves.

tempo. T is a triplet: three steps in the time of two.

the oscillators different lengths and their patterns
slide against each other, lining up again only now
and then.

short for staccato, full for legato. It matters most
when the amp envelope has some SUSTAIN (page

spread as evenly as possible (a Euclidean rhythm),
and the same steps play every time round: a pattern,
not a dice roll.

pool instead of the next one.

repeats of its note.

Turning a knob shows its readout: section, oscillator, name and
value. Here OSC 3's DENSITY is at 3/6: three of its six steps play.

A few seconds later the readout fades. The inner ring (OSC 3)
now shows its three rests as hollow dots, spaced evenly around
the ring.

A classic off-beat. On OSC 1 set LENGTH 8 and DENSITY 3/8: the tresillo, the 3-3-2 rhythm under half of all
pop music.
Patterns that drift. Set DIVISION to 1/8 on all three oscillators and LENGTH to 8, 7 and 5. The three
patterns only line up again after 280 steps.
A little life. On the fastest oscillator, raise VARY to about 20 and RATCHET to about 10.

4

P A G E | 4 | · | T H R E E | S E C T I O N S

## ENVELOPE

### What happens inside each note: how its volume rises and falls, how the filter opens with

it, and how its pitch arrives.

Page 4 just chosen, AMP section. Knob 10 switches between AMP, FILTER and PITCH.

AMP
volume of each note

FILTER
a filter sweep per note

PITCH
how each note arrives

AMP

K N OBS | FUN CT ION | SE T T I N GS | POW ER-ON | W HAT I T DOES
1 | 2 | 3 | AT TACK | 1 MS to 4.1 S | 2 MS | How long a note takes to reach full volume. Short is a click-free hit; long is a swell.
4 | 5 | 6 | DECAY | 5 MS to 4.0 S | 401, 249, 180 MS How long it takes to fall to the SUSTAIN level, and
| | | | | | also how long the note takes to fade out once its GATE ends.
7 | 8 | 9 | SUSTAIN | 0 to 100 | 40, 0, 0 | The level a note holds while its GATE (page 3) lasts. 0 makes every note a pluck that dies away over DECAY.

A new note starts from wherever the last one had got to, so fast patterns never click. An oscillator whose MODE is OFF (a drone) fades in over ATTACK and then holds.

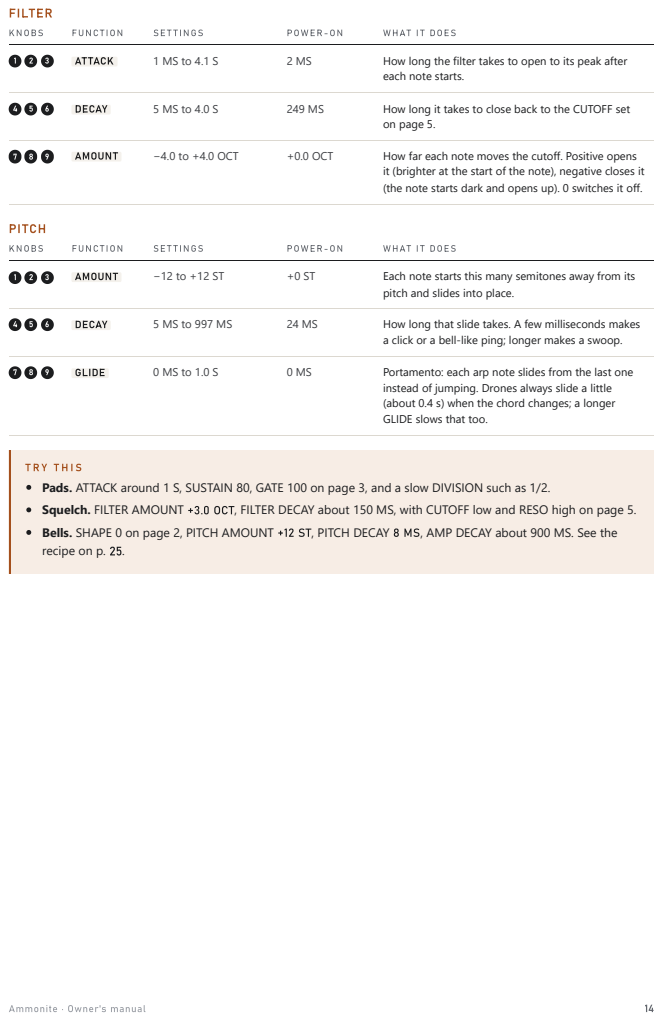
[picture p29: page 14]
FILTER; K N OBS; FUN CT ION; POW ER-ON; W HAT I T DOES; AT TACK; How long the filter takes to open to its peak after; DECAY; How long it takes to close back to the CUTOFF set; on page 5.; AMOUNT; −4.0 to +4.0 OCT; +0.0 OCT; How far each note moves the cutoff. Positive opens; PITCH; Each note starts this many semitones away from its; How long that slide takes. A few milliseconds makes; GLIDE; Portamento: each arp note slides from the last one

each note starts.

it (brighter at the start of the note), negative closes it
(the note starts dark and opens up). 0 switches it off.

pitch and slides into place.

a click or a bell-like ping; longer makes a swoop.

instead of jumping. Drones always slide a little
(about 0.4 s) when the chord changes; a longer
GLIDE slows that too.

Pads. ATTACK around 1 S, SUSTAIN 80, GATE 100 on page 3, and a slow DIVISION such as 1/2.
Squelch. FILTER AMOUNT +3.0 OCT, FILTER DECAY about 150 MS, with CUTOFF low and RESO high on page 5.
Bells. SHAPE 0 on page 2, PITCH AMOUNT +12 ST, PITCH DECAY 8 MS, AMP DECAY about 900 MS. See the
recipe on p. 25.

5

P A G E | 5 | · | O N E | C O L U M N | P E R | O S C I L L A T O R

## FILTER

Each oscillator has its own filter: the main way to make it brighter or darker, thinner or rounder.

Page 5. CUTOFF, RESO and TYPE per oscillator; knob 10 is DRIVE, shared.

K N OBS | FUN CT ION | SE T T I N GS | POW ER-ON | W HAT I T DOES
1 | 2 | 3 | CUTOFF | 80 HZ to 12.0 KHZ | 1.2, 2.0, 3.0 KHZ The filter's frequency. For the low-pass type: lower is
darker and softer.
4 | 5 | 6 | RESO | 0 to 100 | 30, 20, 20 | Resonance: a peak at the cutoff. Higher values whistle and sing, especially when the cutoff moves.
7 | 8 | 9 | TYPE | LP LP-BP BP BP-HP

HP

LP | A smooth morph from low-pass (keeps the lows)
through band-pass (a narrow, nasal band) to high-pass (keeps the highs, thin and airy).
10 | DRIVE | 0 to 100 | 0 | Pushes all three oscillators into soft saturation
before their filters: warmer, then grittier. The level stays roughly the same.

Four things move the cutoff. The CUTOFF knob here sets where each filter rests. On top of it come the master CUTOFF on page 1 (all three at once), the FILTER envelope on page 4 (with every note) and the CUTOFF LFO on page 6 (slowly, or not so slowly). They add up, so a filter can move a long way.

T R Y T H I S
TYPE BP with RESO around 60 turns a saw into a vowel-like, talking sound.
Put OSC 3 on HP: its high arp becomes a thin shimmer over the others.

Knob 2 turned: OSC 2's CUTOFF at 1.5 KHZ.

6

P A G E | 6 | · | F I V E | T A R G E T S

## LFO

Movement. Each oscillator has five LFOs, one for each thing they can move: pitch, cutoff, volume, pan and shape. That is fifteen in all, each with its own speed.

Page 6, PITCH target. Knob 10 is called TARGET here: it picks what the LFOs on knobs 1–9 move.

PITCH | CUTOFF | AMP | PAN | SHAPE

Every target has the same three rows. At power-on every DEPTH is 0, so the dots of the other targets are grey: an LFO does nothing until you raise its DEPTH.

K N OBS | FUN CT ION | SE T T I N GS | POW ER-ON | W HAT I T DOES
1 | 2 | 3 | RATE | 0.02 to 20.0 HZ; with LFO SYNC on TEMPO: 4 BARS 2 BARS 1 BAR 1/2 1/4 1/4T 1/8 1/8T 1/16 | 0.32 HZ (CUTOFF: 0.09, 0.13, 0.17 HZ) | How fast the LFO cycles: from about once a minute to a buzz. With LFO SYNC (page 9) set to TEMPO, RATE picks a note length instead, and the LFO locks to the bar.
4 | 5 | 6 | DEPTH | 0 to 100 | 0 | How much it moves its target (table below).
7 | 8 | 9 | WAVE | SINE TRI SAW
| | | | SQUARE S+H DRIFT
SINE | The movement's shape. S+H jumps to a new random
value each cycle; DRIFT wanders smoothly from one random value to the next.

TARGE T | AT DEP TH 1 00 | SOUN DS LIKE
PITCH | up and down one semitone | vibrato, or a seasick wobble when slow
CUTOFF | three octaves either way | a filter that breathes or wah-wahs
AMP | dips all the way to silence (never louder) | tremolo, or a chopped gate with SQUARE
PAN | swings from full left to full right | notes moving around the room
SHAPE | 50 either side of the SHAPE setting | a tone that keeps changing color

T R Y T H I S
Slow life. CUTOFF target, DEPTH about 30 on all three: the power-on rates are slow and all different, so the three filters drift in and out of step.
Rhythmic chop. Set LFO SYNC to TEMPO on page 9, then AMP target, RATE 1/8, WAVE SQUARE, DEPTH 100 on a drone.
Wide arps. PAN target, WAVE S+H, RATE about 4 HZ: every few notes land somewhere new in the stereo field.

7

## DELAY

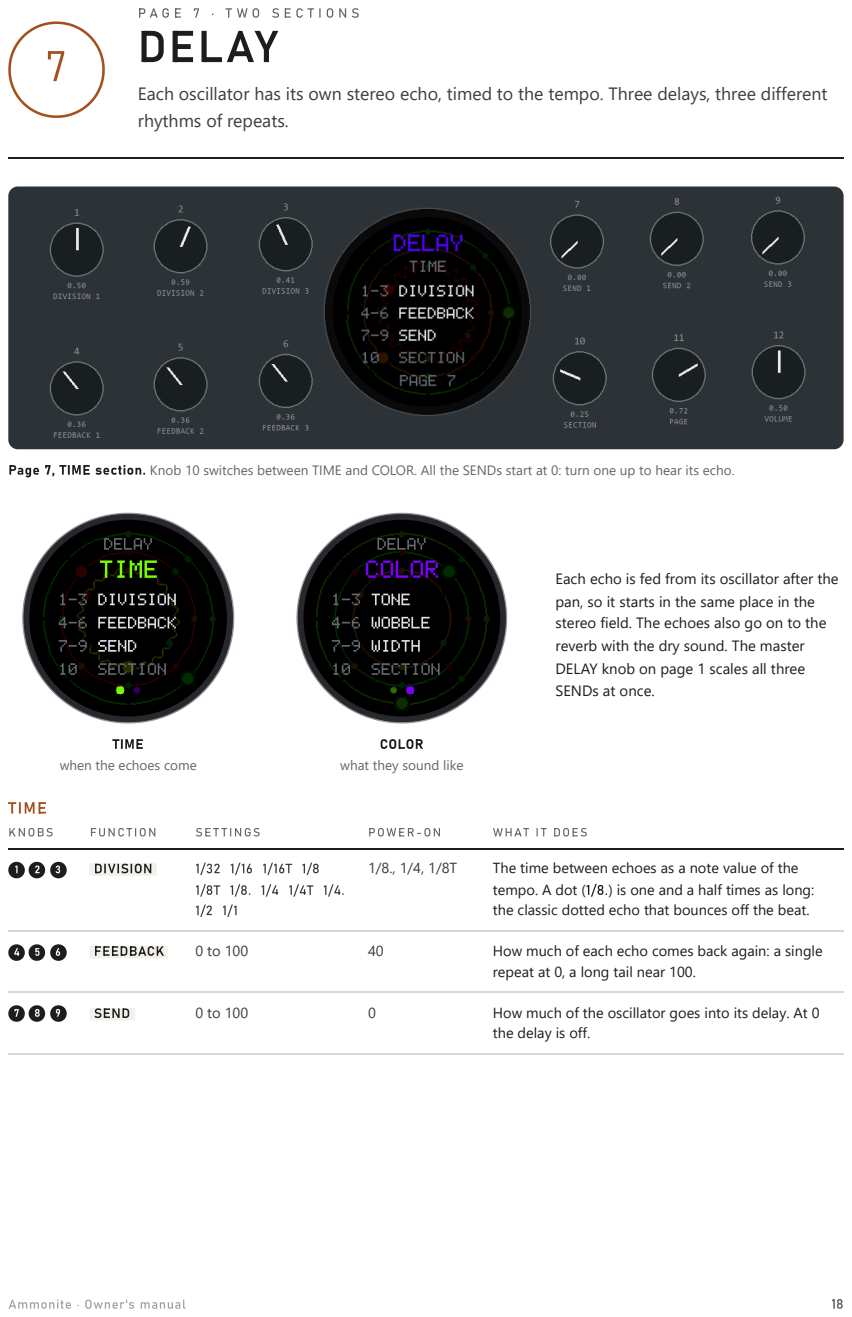
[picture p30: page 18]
TIME; K N OBS; FUN CT ION; POW ER-ON; W HAT I T DOES; DIVISION; The time between echoes as a note value of the; FEEDBACK; How much of each echo comes back again: a single; SEND; How much of the oscillator goes into its delay. At 0

Each oscillator has its own stereo echo, timed to the tempo. Three delays, three different
rhythms of repeats.

Page 7, TIME section. Knob 10 switches between TIME and COLOR. All the SENDs start at 0: turn one up to hear its echo.

Each echo is fed from its oscillator after the
pan, so it starts in the same place in the
stereo field. The echoes also go on to the
reverb with the dry sound. The master
DELAY knob on page 1 scales all three
SENDs at once.

TIME
when the echoes come

COLOR
what they sound like

tempo. A dot (1/8.) is one and a half times as long:
the classic dotted echo that bounces off the beat.

repeat at 0, a long tail near 100.

the delay is off.

COLOR

K N OBS | FUN CT ION | SE T T I N GS | POW ER-ON | W HAT I T DOES
1 | 2 | 3 | TONE | 500 HZ to 12.0 KHZ | 4.0 KHZ | Each repeat passes through a gentle low-pass: lower settings make the echoes darker and darker as they fade, like tape.
4 | 5 | 6 | WOBBLE | 0.0 to 3.0 MS | 0.9 MS | A slow, random wander in the delay time, the way a tape machine drifts. It bends the pitch of the echoes slightly.
7 | 8 | 9 | WIDTH | 0 to 100 | 100 | At 0 the echoes stay where the oscillator is panned. At 100 they ping-pong: left, right, left.

T R Y T H I S
Delay only the slowest oscillator, with a dotted DIVISION: the echoes fill the gaps between its notes. FEEDBACK 80, TONE 1.5 KHZ, WOBBLE 2 MS: a dark dub echo that sinks away (see the recipe Dub echoes).

8

## MIX

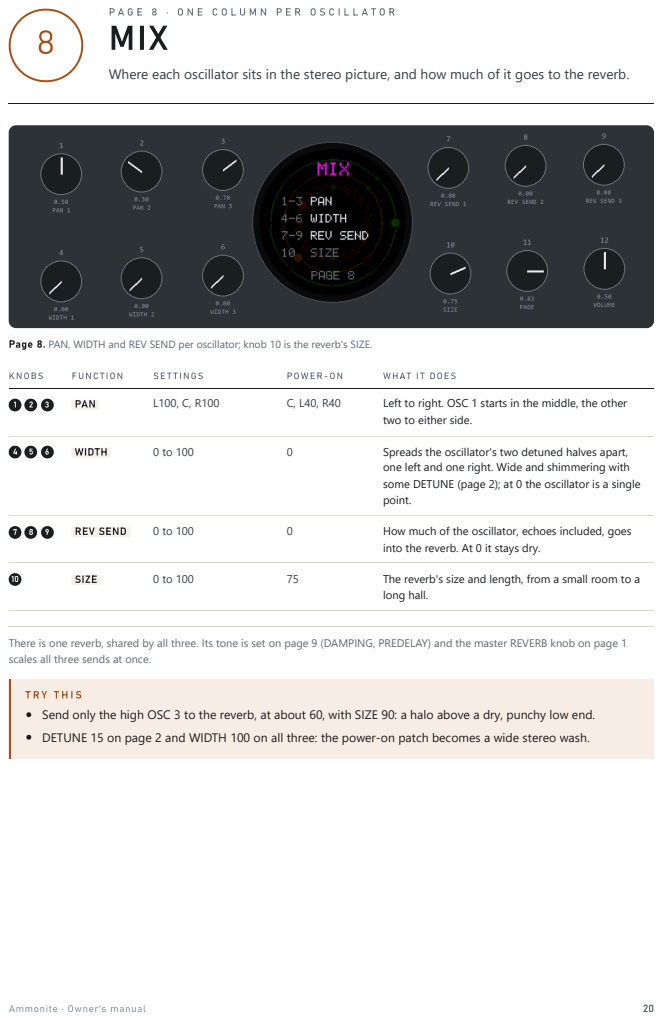
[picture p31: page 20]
K N OBS; FUN CT ION; POW ER-ON; W HAT I T DOES; PAN; Left to right. OSC 1 starts in the middle, the other; WIDTH; Spreads the oscillator's two detuned halves apart,; REV SEND; How much of the oscillator, echoes included, goes; SIZE; The reverb's size and length, from a small room to a; long hall.

Where each oscillator sits in the stereo picture, and how much of it goes to the reverb.

Page 8. PAN, WIDTH and REV SEND per oscillator; knob 10 is the reverb's SIZE.

two to either side.

one left and one right. Wide and shimmering with
some DETUNE (page 2); at 0 the oscillator is a single
point.

into the reverb. At 0 it stays dry.

There is one reverb, shared by all three. Its tone is set on page 9 (DAMPING, PREDELAY) and the master REVERB knob on page 1
scales all three sends at once.

Send only the high OSC 3 to the reverb, at about 60, with SIZE 90: a halo above a dry, punchy low end.
DETUNE 15 on page 2 and WIDTH 100 on all three: the power-on patch becomes a wide stereo wash.

9

## KEY

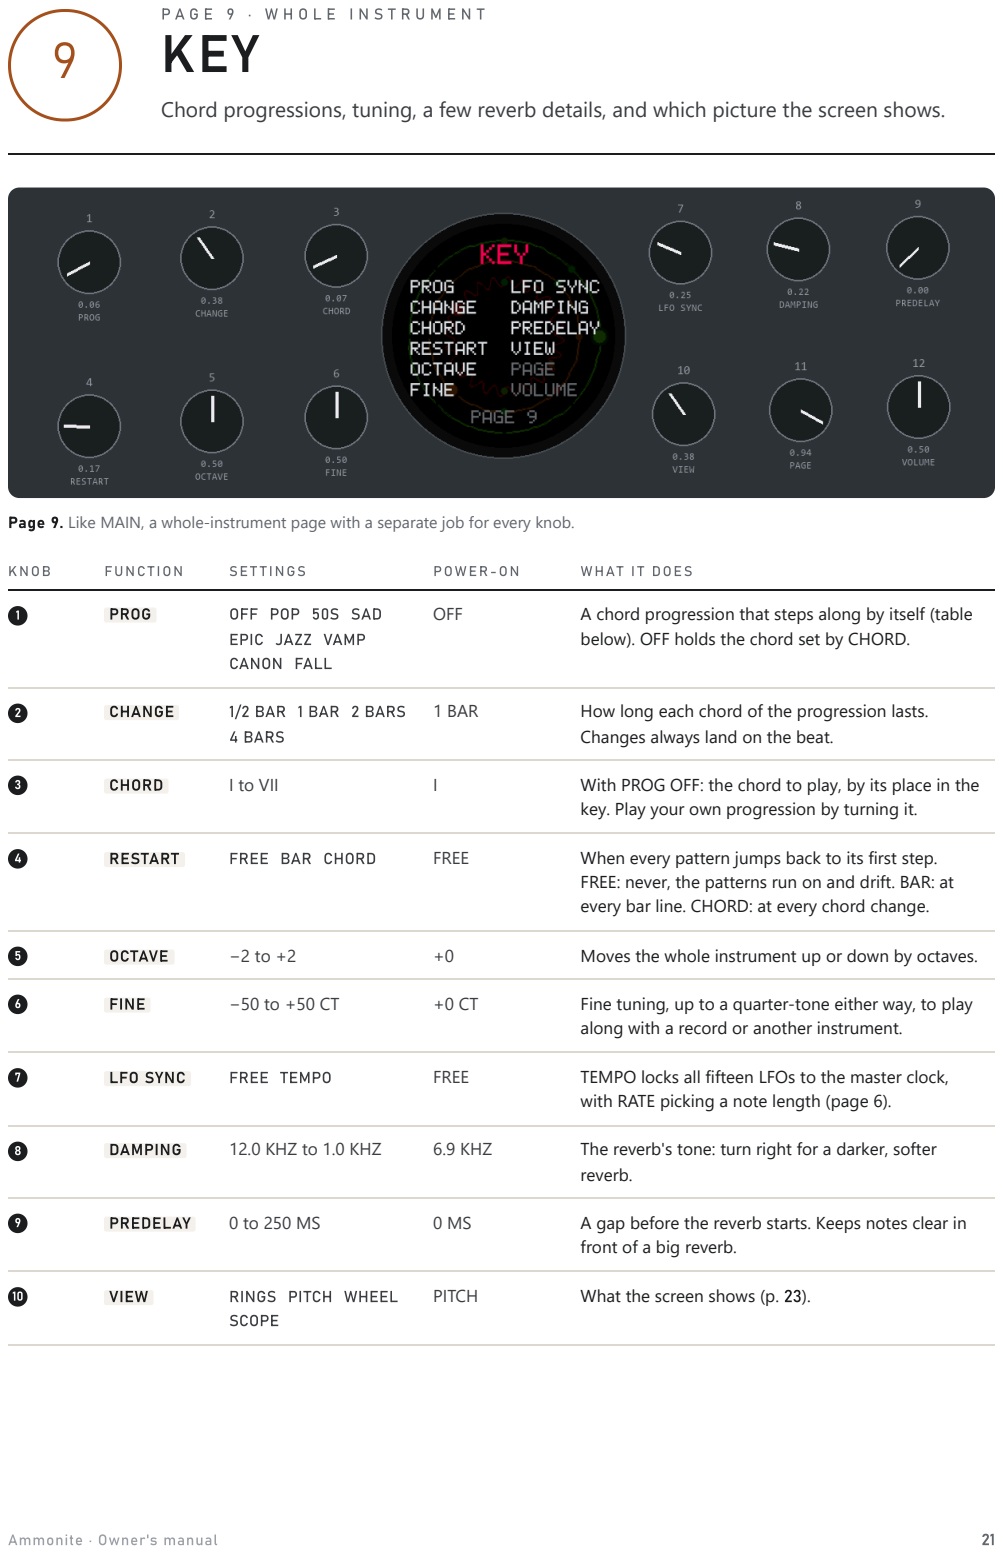
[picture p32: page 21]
FUN CT ION; POW ER-ON; W HAT I T DOES; PROG; OFF POP 50S SAD; CANON FALL; OFF; A chord progression that steps along by itself (table; CHANGE; 1/2 BAR 1 BAR 2 BARS; 4 BARS; 1 BAR; How long each chord of the progression lasts.; CHORD; I to VII; With PROG OFF: the chord to play, by its place in the; RESTART; FREE BAR CHORD; FREE; When every pattern jumps back to its first step.; OCTAVE; Moves the whole instrument up or down by octaves.; FINE; Fine tuning, up to a quarter-tone either way, to play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

Chord progressions, tuning, a few reverb details, and which picture the screen shows.

Page 9. Like MAIN, a whole-instrument page with a separate job for every knob.

EPIC JAZZ VAMP

below). OFF holds the chord set by CHORD.

Changes always land on the beat.

key. Play your own progression by turning it.

FREE: never, the patterns run on and drift. BAR: at
every bar line. CHORD: at every chord change.

along with a record or another instrument.

with RATE picking a note length (page 6).

front of a big reverb.

The progressions

PROG | DEGREES | I N A MI N OR (POW ER-ON ) | I N C MAJOR
POP | 1 5 6 4 | Am Em F Dm | C G Am F
50S | 1 6 4 5 | Am F Dm Em | C Am F G
SAD | 6 4 1 5 | F Dm Am Em | Am F C G
EPIC | 1 6 3 7 | Am F C G | C Am Em Bdim
JAZZ | 2 5 1 1 | Bdim Em Am Am | Dm G C C
VAMP | 1 4 | Am Dm | C F
CANON | 1 5 6 3 4 1 4 5 | Am Em F C Dm Am Dm Em | C G Am Em F C F G
FALL | 1 7 6 5 | Am G F Em | C Bdim Am G

POP running in A minor, on its
third chord: F, degree VI, chord 3 of 4. The four dots are the beats of the bar.

A progression is written in scale degrees, so it works in any key: ROOT and SCALE on page 1 still transpose it while it runs. The chord changes on the bar line; a note already sounding finishes, and the next one uses the new chord. With a chord key (SCALE set to MAJ, MIN7 and so on) every chord of the progression takes that chord's quality.

T H E S C R E E N

## Reading the rings

The screen shows what the three arps are playing, as it happens. Once you can read it, you can see a pattern before you hear it.

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
Colors are notes

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
Every note has its own color, the same in every octave and on every view. The colors run around the circle of fifths: notes a fifth apart get neighboring colors. That puts notes that sound good together close in color. A root and its fifth (the two notes of a FIFTHS pool) always look alike, and each chord of a progression brings its own mix of colors to the screen.

The wheel is drawn on black because the brightest colors, yellow and cyan, vanish on white paper. On the screen they glow.

OSC 1 is the outer ring. 1

2 | OSC 2 is the middle ring.
| OSC 3 is the inner ring. Each ring is cut into as many arcs as its oscillator's LENGTH , starting at 12 o'clock and running clockwise. One arc is one step.
3

The playing step is the big dot with a halo. It moves on one arc with every step.

4

A rest is a hollow dot on a grey arc: a step that DENSITY leaves out.

5

The line is the sound itself. It is the
oscillator's real waveform: it swells when a note starts and flattens as it fades, and higher notes fit more waves round the ring. A drone is one unbroken ring.

6

The chord playing now, in the color of its root note.

7

Its numeral in the key. Lowercase means minor. When a progression runs, its place in it follows, e.g. 3/4.

8

The beat: one dot for each beat of the bar.

9

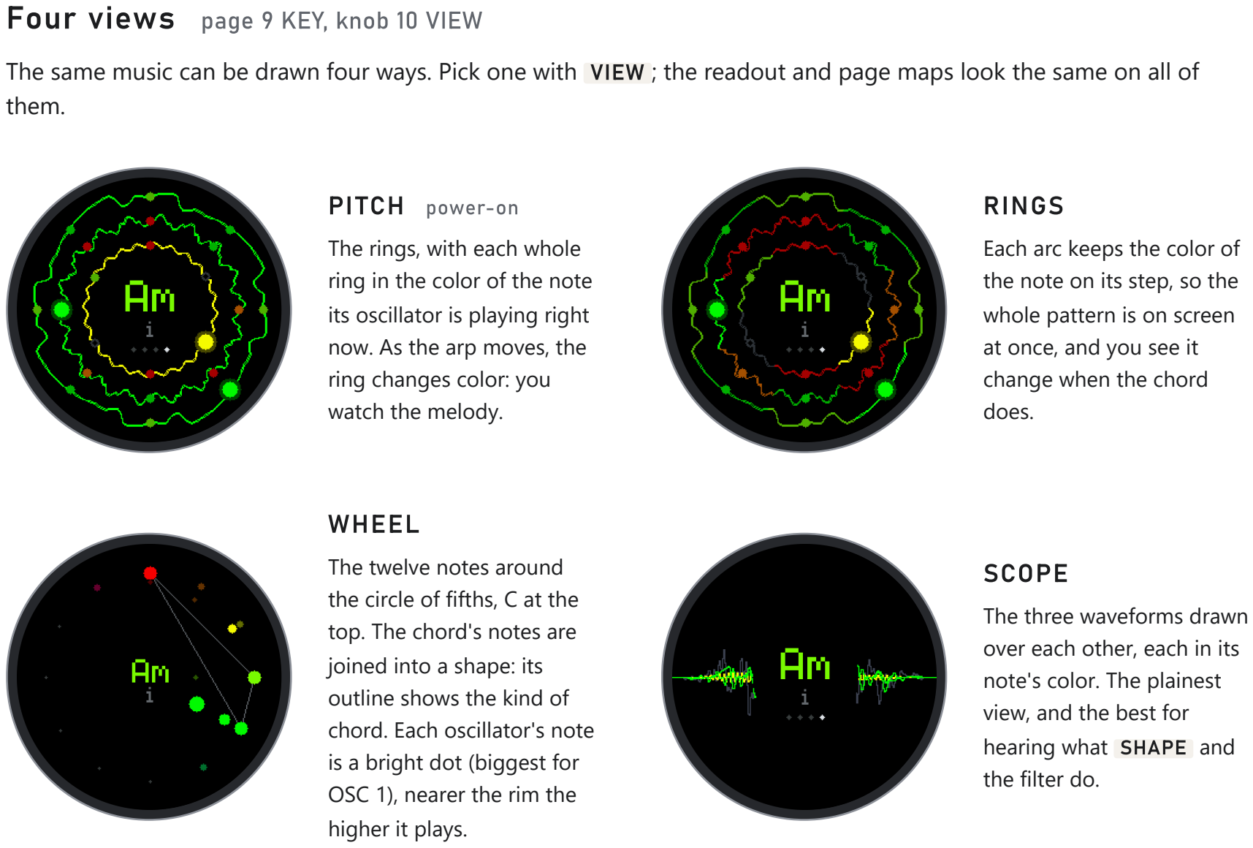
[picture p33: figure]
Four views page 9 KEY, knob 10 VIEW; them.; PITCH; power-on; The rings, with each whole ring in the color of the note its oscillator is playing right now. As the arp moves, the ring changes color: you watch the melody.; RINGS Each arc keeps the color of the note on its step, so the whole pattern is on screen at once, and you see it change when the chord does.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

The same music can be drawn four ways. Pick one with VIEW ; the readout and page maps look the same on all of

## Recipes

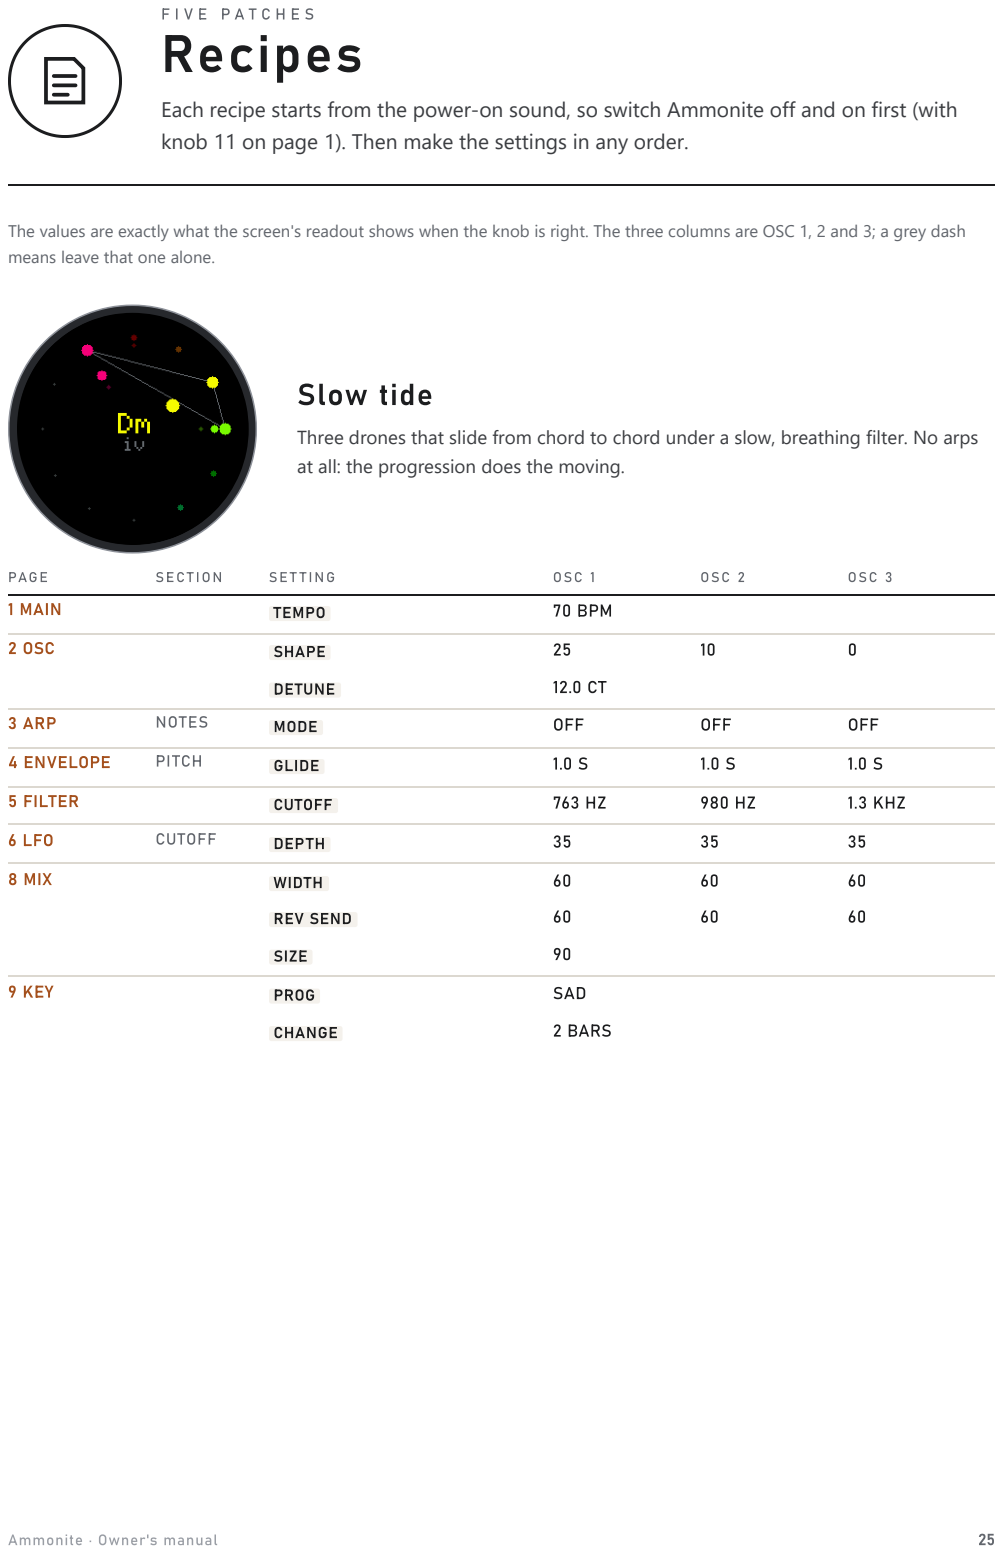
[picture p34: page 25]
PAGE; SECT ION; OSC 1; OSC 2; OSC 3; 1 MAIN; TEMPO; 70 BPM; 2 OSC; SHAPE; DETUNE; 3 ARP; NOTES; MODE; OFF; 4 ENVELOPE; PITCH; GLIDE; 5 FILTER; CUTOFF; 1.3 KHZ; 6 LFO; DEPTH; 8 MIX; WIDTH; REV SEND; SIZE; 9 KEY; PROG; SAD; CHANGE; 2 BARS

Each recipe starts from the power-on sound, so switch Ammonite off and on first (with
knob 11 on page 1). Then make the settings in any order.

The values are exactly what the screen's readout shows when the knob is right. The three columns are OSC 1, 2 and 3; a grey dash
means leave that one alone.

Slow tide
Three drones that slide from chord to chord under a slow, breathing filter. No arps
at all: the progression does the moving.

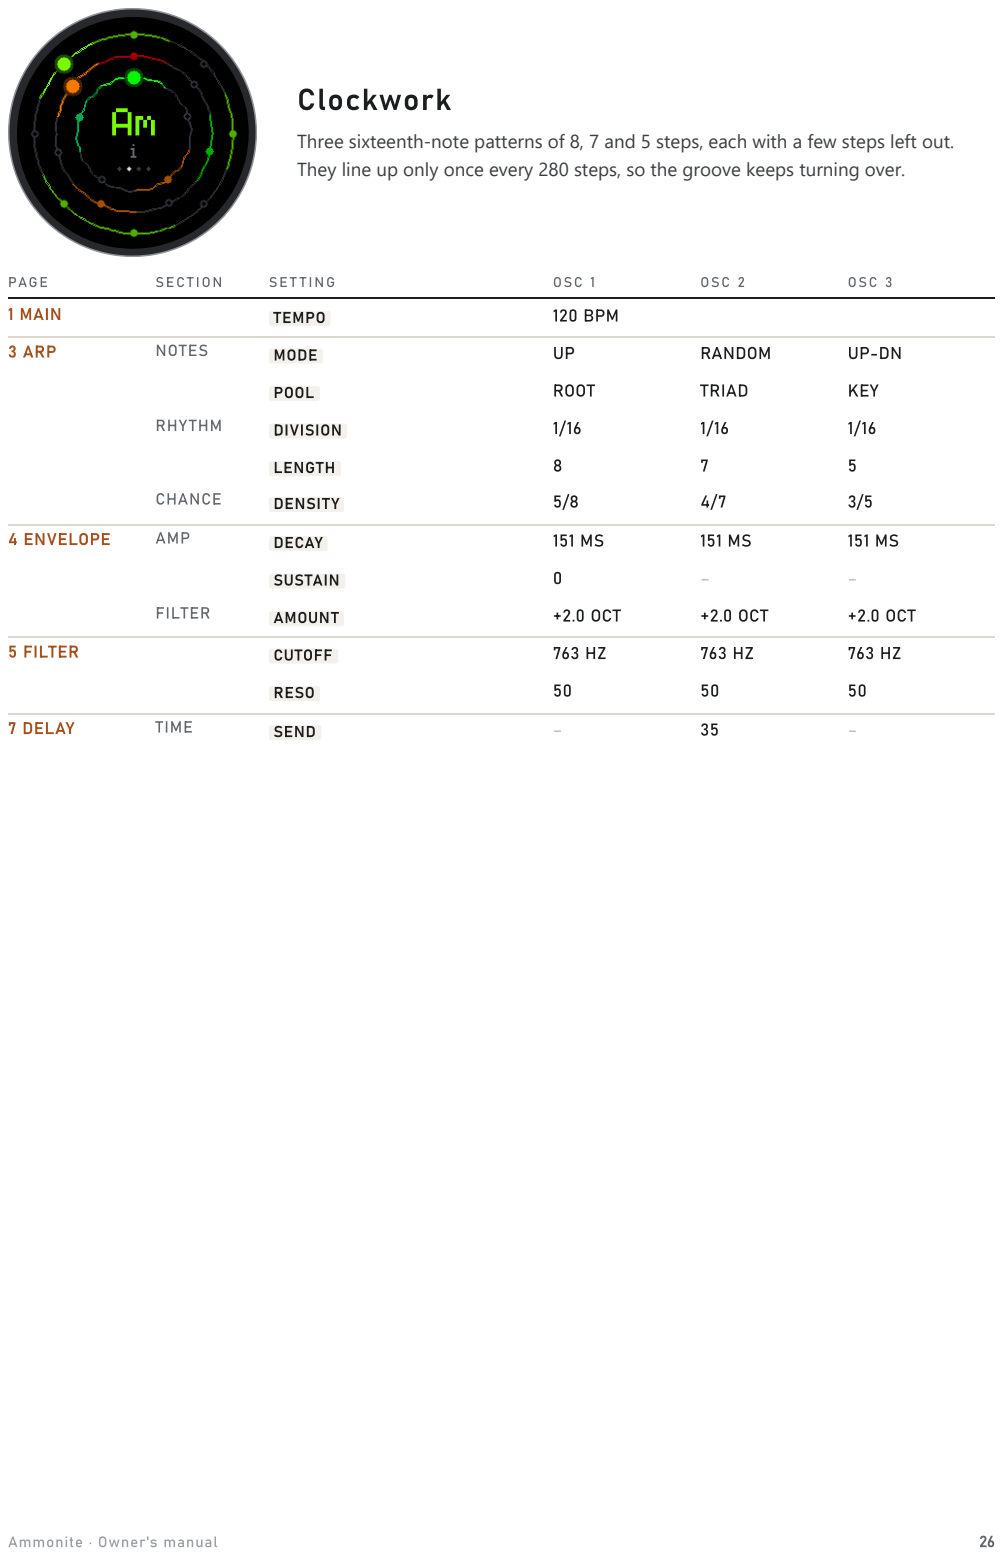
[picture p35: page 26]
PAGE; SECT ION; OSC 1; OSC 2; OSC 3; 1 MAIN; TEMPO; 120 BPM; 3 ARP; NOTES; MODE; RANDOM; POOL; ROOT; TRIAD; KEY; RHYTHM; DIVISION; LENGTH; CHANCE; DENSITY; 4 ENVELOPE; AMP; DECAY; SUSTAIN; FILTER; AMOUNT; +2.0 OCT; 5 FILTER; CUTOFF; RESO; 7 DELAY; TIME; SEND

Clockwork
Three sixteenth-note patterns of 8, 7 and 5 steps, each with a few steps left out.
They line up only once every 280 steps, so the groove keeps turning over.

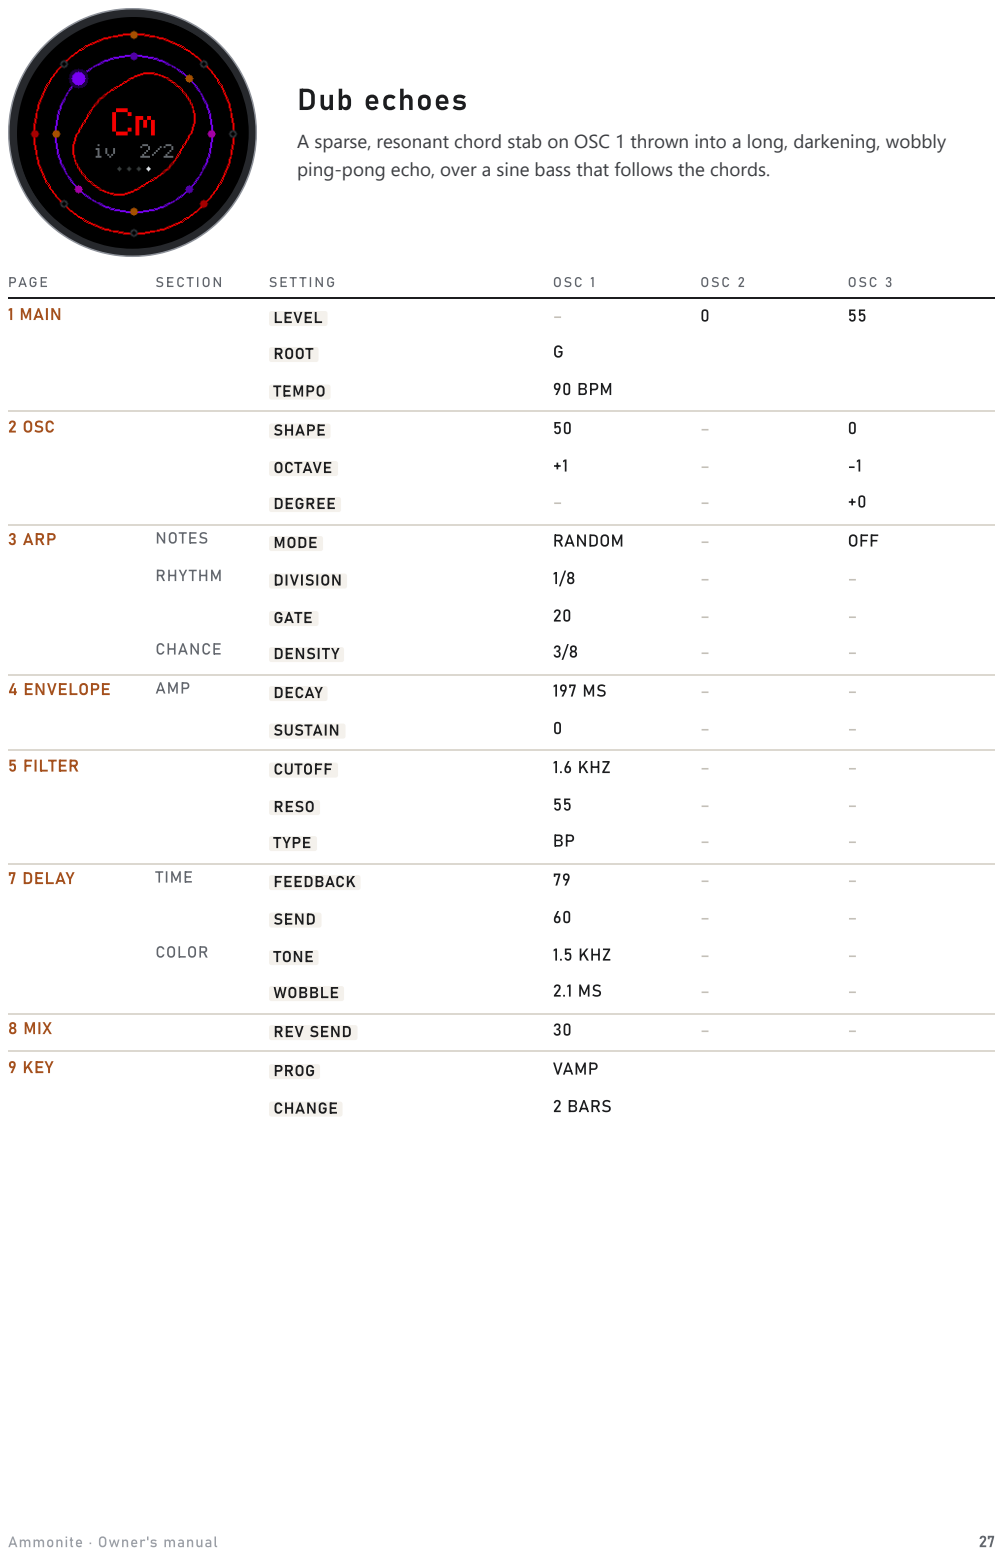
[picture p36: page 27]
PAGE; SECT ION; OSC 1; OSC 2; OSC 3; 1 MAIN; LEVEL; ROOT; TEMPO; 90 BPM; 2 OSC; SHAPE; OCTAVE; DEGREE; 3 ARP; NOTES; MODE; RANDOM; OFF; RHYTHM; DIVISION; GATE; CHANCE; DENSITY; 4 ENVELOPE; AMP; DECAY; SUSTAIN; 5 FILTER; CUTOFF; 1.6 KHZ; RESO; TYPE; 7 DELAY; TIME; FEEDBACK; SEND; COLOR; TONE; 1.5 KHZ; WOBBLE; 8 MIX; REV SEND; 9 KEY; PROG; VAMP; CHANGE; 2 BARS

Dub echoes
A sparse, resonant chord stab on OSC 1 thrown into a long, darkening, wobbly
ping-pong echo, over a sine bass that follows the chords.

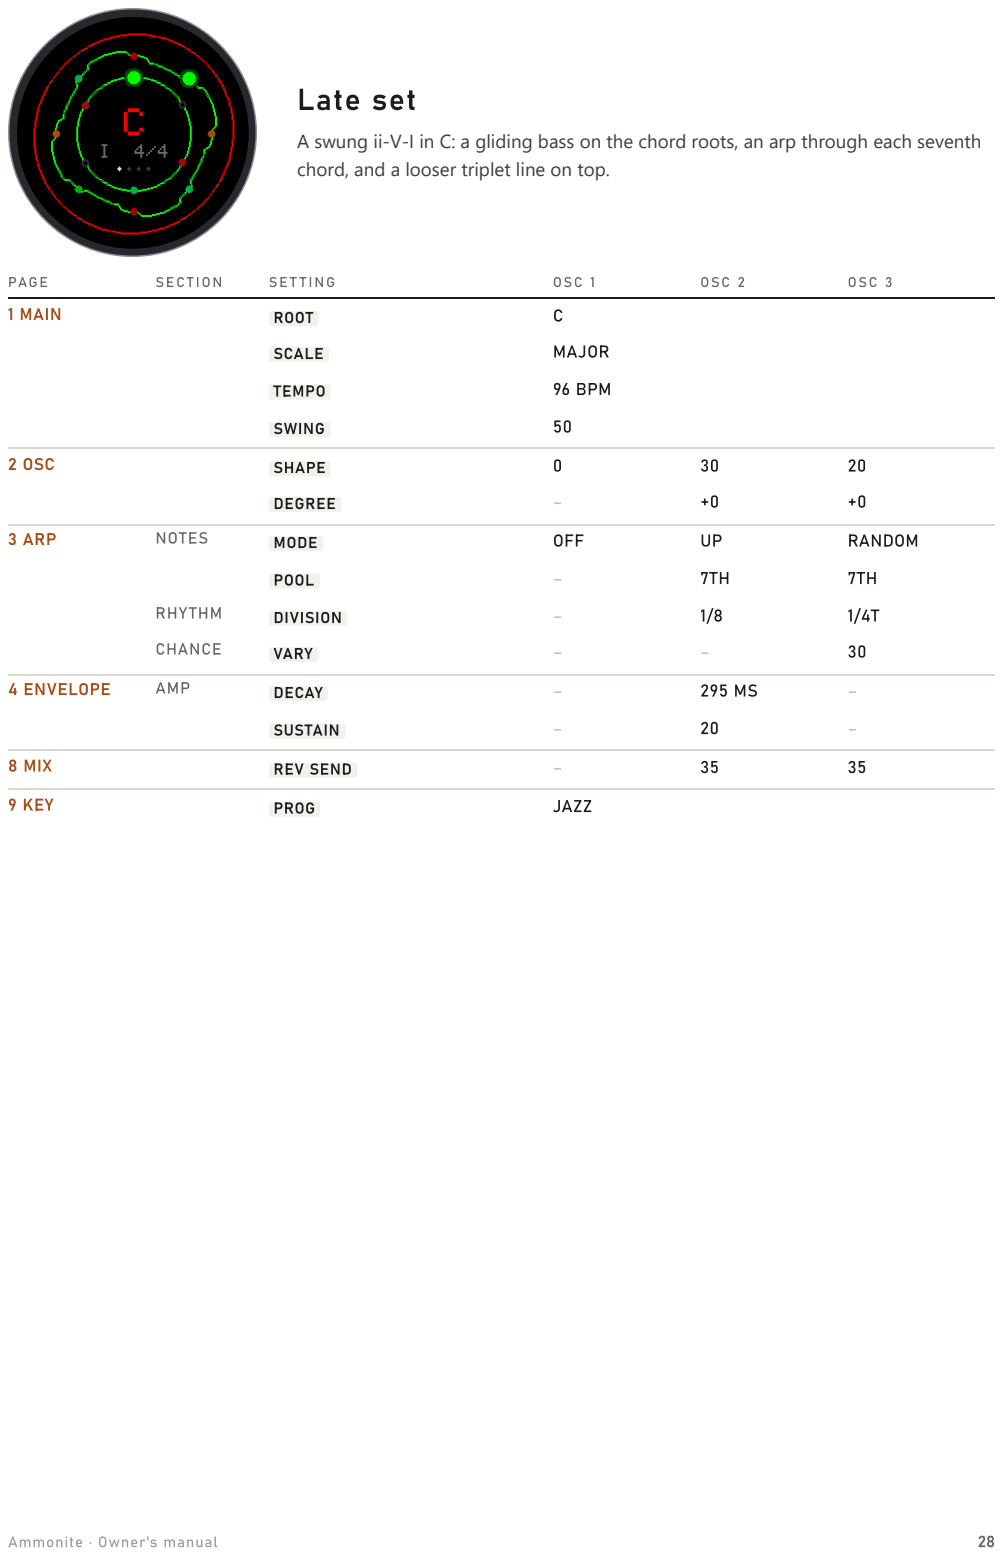
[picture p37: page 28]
PAGE; SECT ION; OSC 1; OSC 2; OSC 3; 1 MAIN; ROOT; SCALE; MAJOR; TEMPO; 96 BPM; SWING; 2 OSC; SHAPE; DEGREE; 3 ARP; NOTES; MODE; OFF; RANDOM; POOL; RHYTHM; DIVISION; CHANCE; VARY; 4 ENVELOPE; AMP; DECAY; SUSTAIN; 8 MIX; REV SEND; 9 KEY; PROG; JAZZ

Late set
A swung ii-V-I in C: a gliding bass on the chord roots, an arp through each seventh
chord, and a looser triplet line on top.

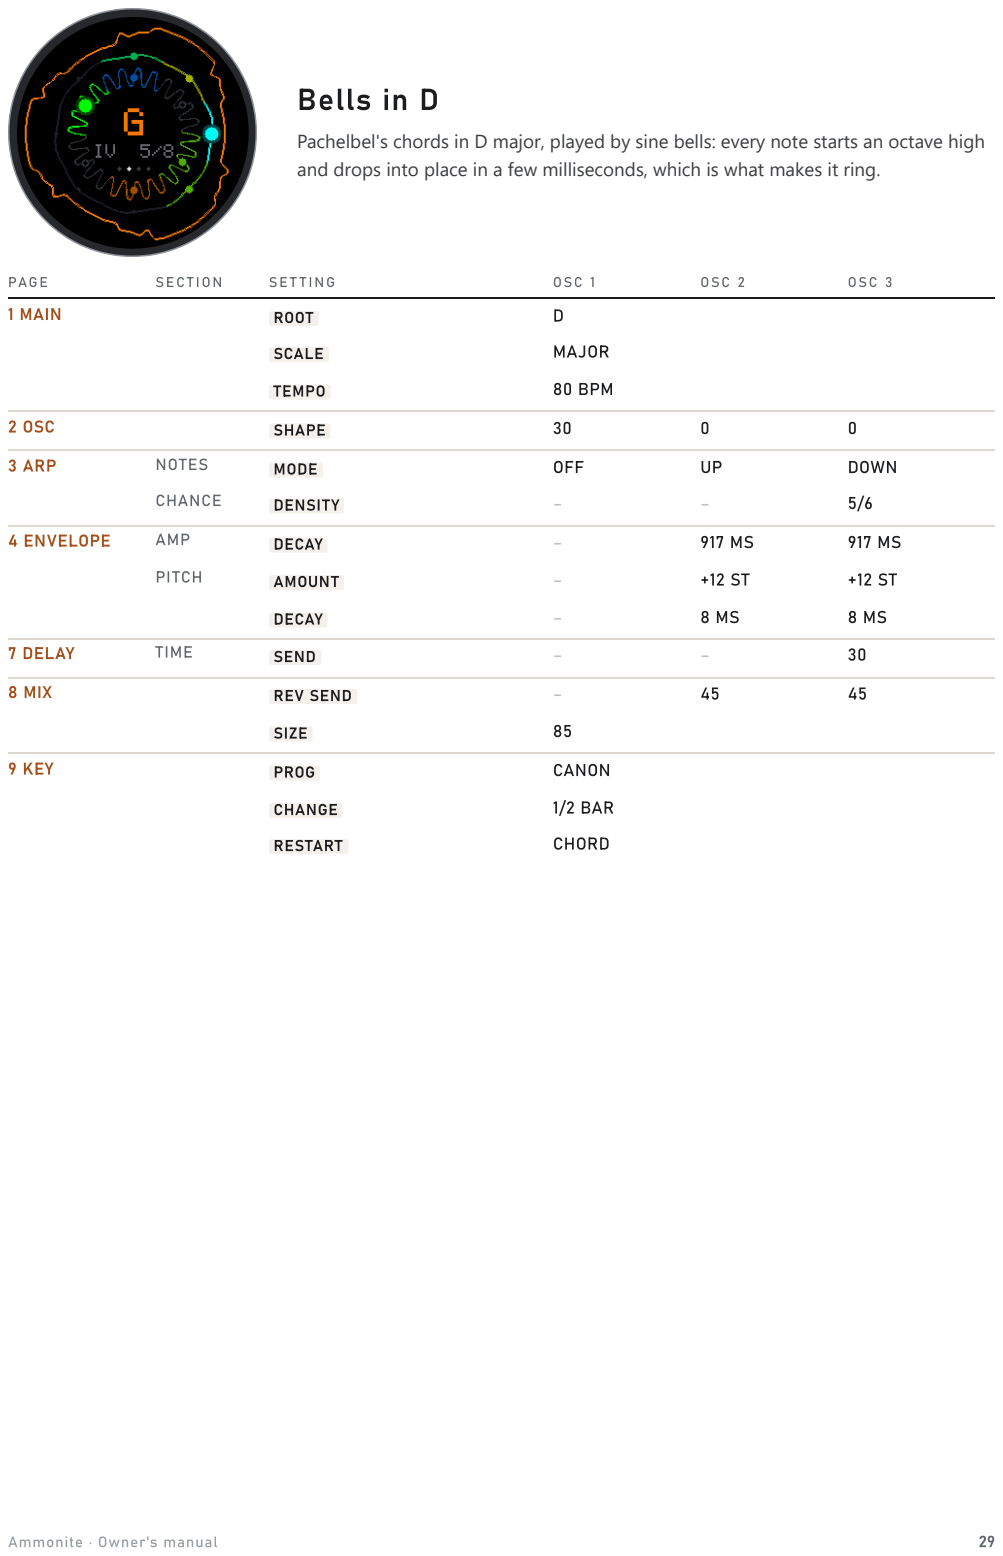
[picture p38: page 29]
PAGE; SECT ION; OSC 1; OSC 2; OSC 3; 1 MAIN; ROOT; SCALE; MAJOR; TEMPO; 80 BPM; 2 OSC; SHAPE; 3 ARP; NOTES; MODE; OFF; DOWN; CHANCE; DENSITY; 4 ENVELOPE; AMP; DECAY; PITCH; AMOUNT; 7 DELAY; TIME; SEND; 8 MIX; REV SEND; SIZE; 9 KEY; PROG; CANON; CHANGE; 1/2 BAR; RESTART; CHORD

Bells in D
Pachelbel's chords in D major, played by sine bells: every note starts an octave high
and drops into place in a few milliseconds, which is what makes it ring.

A P P E N D I X

## Scales and chords

### Every SCALE setting on page 1, spelled out from C. Turn ROOT and the same pattern

starts from another note.

SCALES

SCALE | N OT ES FROM C | CHARACT ER
MAJOR | C D E F G A B | bright, settled
MINOR | C D D# F G G# A# | dark; the power-on key
DORIAN | C D D# F G A A# | minor with a lift; soul and jazz
PHRYGIAN | C C# D# F G G# A# | dark and tense, Spanish flavor
LYDIAN | C D E F# G A B | major, floating and dreamy
MIXO | C D E F G A A# | major with a bluesy seventh
HARM MIN | C D D# F G G# B | minor with a dramatic leading note
PENTA | C D E G A | five notes, no clashes at all
PENTA MI | C D# F G A# | the minor five-note scale
BLUES | C D# F F# G A# | minor pentatonic plus the blue note

CHORD KEYS
Past BLUES, SCALE turns into a chord. Then POOL KEY plays that chord's notes, and a progression moves the chord through its parent scale (natural minor for MIN, MIN7 and DIM; major for the rest), keeping its quality: a MIN7 key gives a progression of minor sevenths.
SCALE | N OT ES FROM C | CHARACT ER
MAJ | C E G | plain major triad
MIN | C D# G | plain minor triad
SUS2 | C D G | open, neither major nor minor
SUS4 | C F G | open, waiting to resolve
MAJ7 | C E G B | soft, jazzy major
MIN7 | C D# G A# | smooth minor
DOM7 | C E G A# | bluesy, restless
DIM | C D# F# | tense, spooky
AUG | C E G# | strange, dreamlike
ADD9 | C D E G | bright and airy

## Cheat sheet

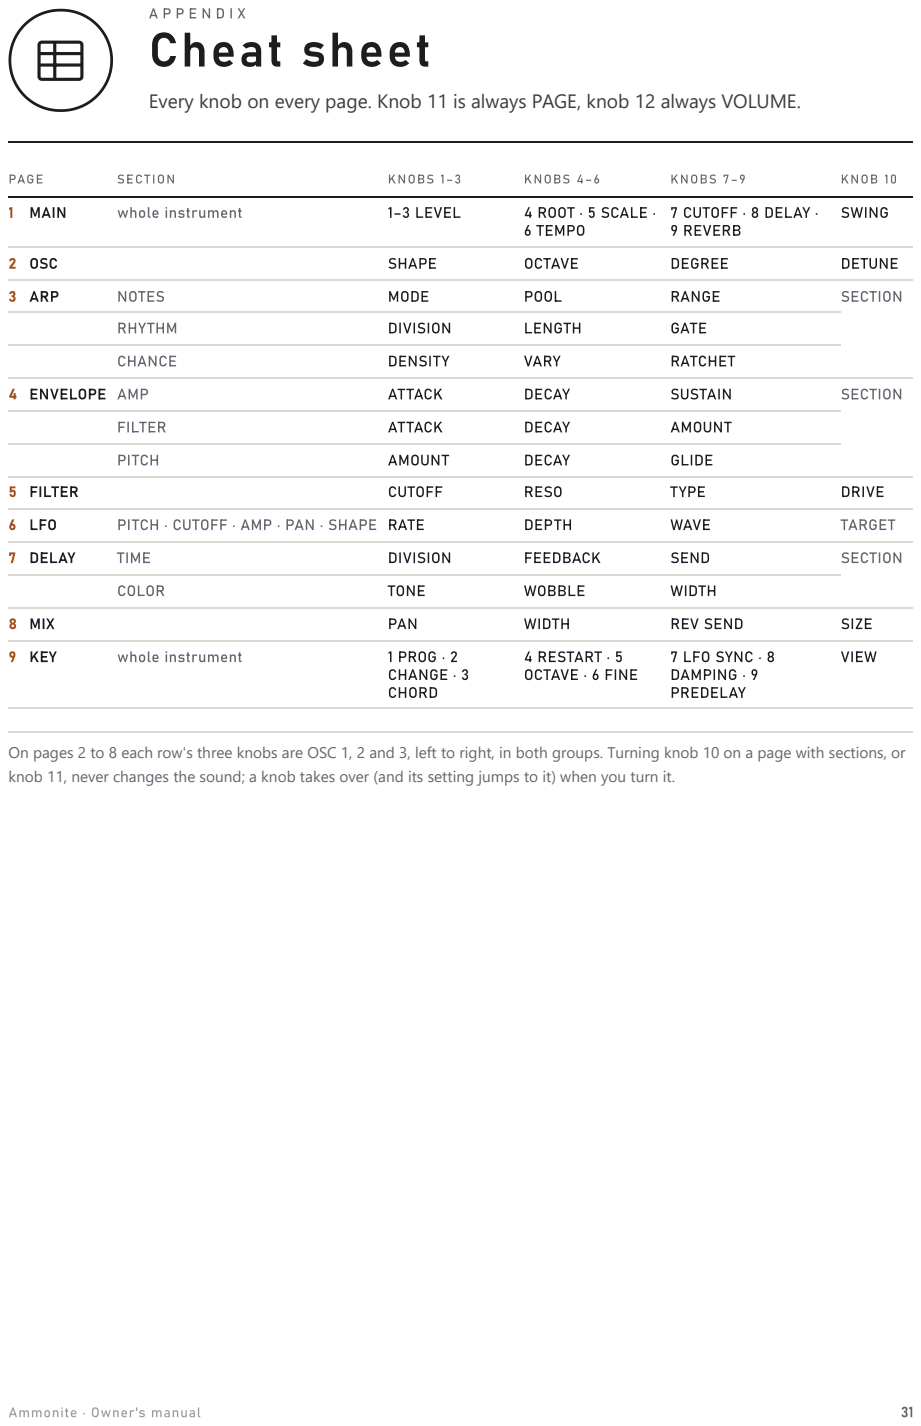
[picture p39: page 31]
PAGE; SECT ION; KNOBS 1–3; KNOBS 4–6; KNOBS 7–9; KNOB 10; MAIN; whole instrument; 1–3 LEVEL; 4 ROOT · 5 SCALE ·; 6 TEMPO; 7 CUTOFF · 8 DELAY ·; 9 REVERB; SWING; OSC; SHAPE; OCTAVE; DEGREE; DETUNE; 3 ARP; NOTES; MODE; POOL; RANGE; SECTION; RHYTHM; DIVISION; LENGTH; GATE; CHANCE; DENSITY; VARY; RATCHET; 4 ENVELOPE AMP; ATTACK; DECAY; SUSTAIN; 4 ENVELOPE FILTER; AMOUNT; 4 ENVELOPE PITCH; GLIDE; 5 FILTER; CUTOFF; RESO; TYPE; DRIVE; LFO; PITCH · CUTOFF · AMP · PAN · SHAPE RATE; DEPTH; WAVE; TARGET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

Every knob on every page. Knob 11 is always PAGE, knob 12 always VOLUME.

On pages 2 to 8 each row's three knobs are OSC 1, 2 and 3, left to right, in both groups. Turning knob 10 on a page with sections, or
knob 11, never changes the sound; a knob takes over (and its setting jumps to it) when you turn it.

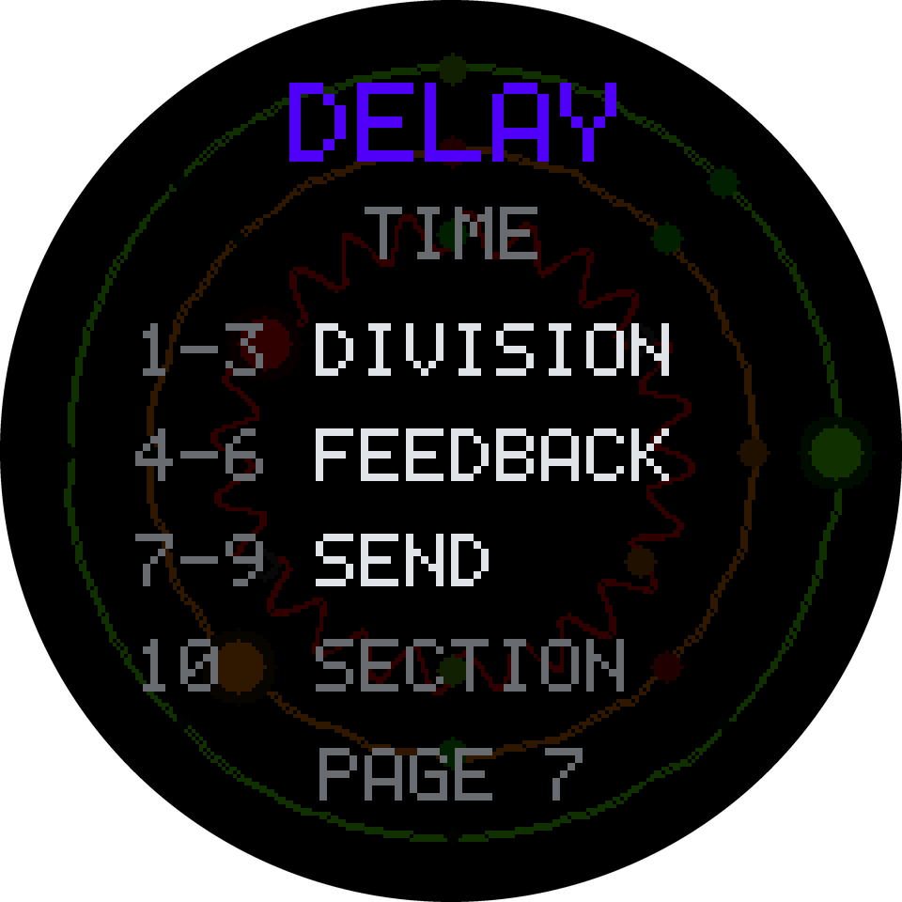
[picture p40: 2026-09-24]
manual/img/screen_pagemap_delay.png

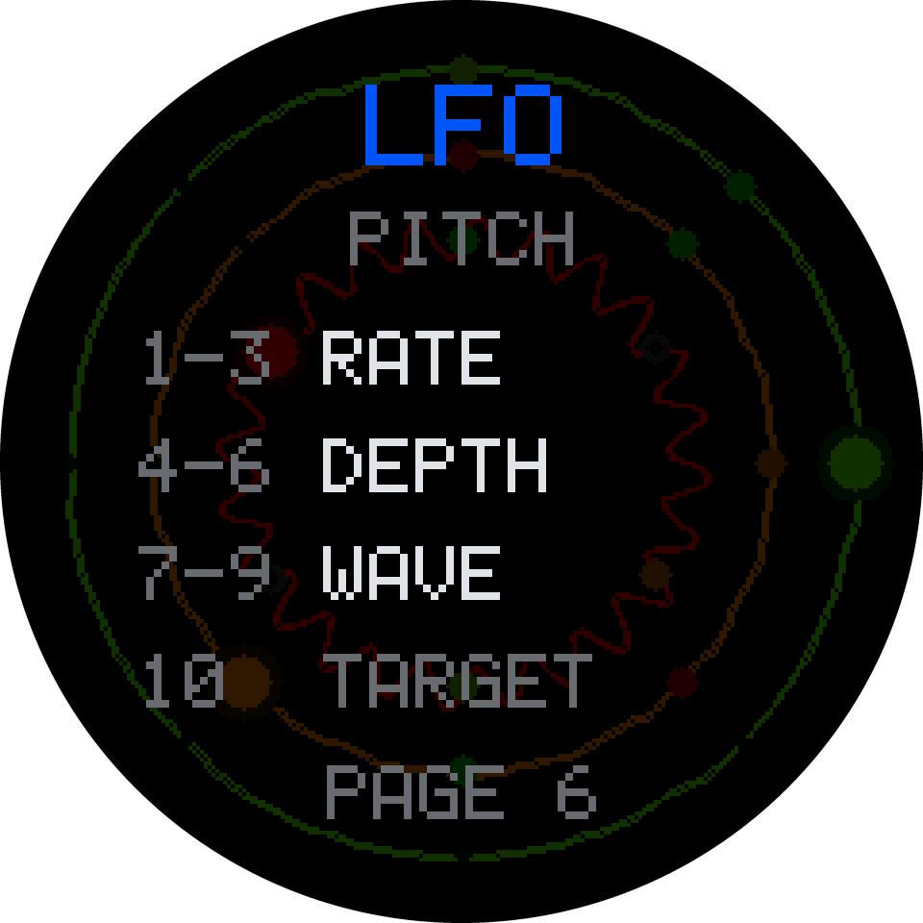
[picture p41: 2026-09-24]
manual/img/screen_pagemap_lfo.png

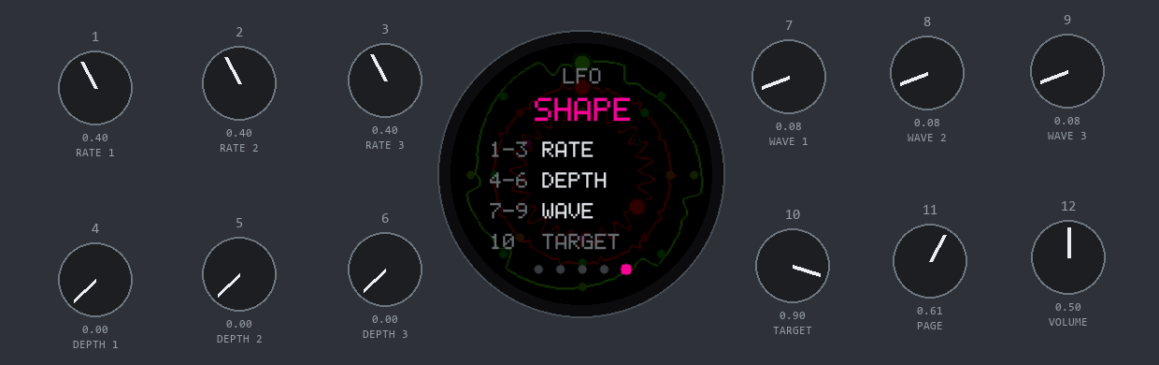
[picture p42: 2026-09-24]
manual/img/panel_page_lfo_shape.png

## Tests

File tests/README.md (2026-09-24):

# Headless checks of synthcore.dll

Each script loads `..\sim\synthcore.dll` through `arpsynth.py` (shared
helpers: pages, sub-pages, pickup-aware `setp`, `fresh`, `render`, spectra),
drives the pots through the C API and measures the audio. Build the DLL
first (`simulator.bat` or `sim\build_dll.ps1`), then from PowerShell:

    python tests\test_panel.py

(or `.\ammonite.ps1 test` to run them all).

- test_panel.py   pages, column layout, sub-pages, pickup, value texts, page / sub maps
- test_voices.py  three droning oscillators: key, chord degree, octave, FINE, level,
                  filter type, master cutoff, pan / width, reverb send
- test_arp.py     master clock + ARP + AMP envelope: step timing, grids locked over a
                  minute, pools, modes, LENGTH polymeter, Euclidean DENSITY, GATE,
                  release = decay, SWING, RATCHET, VARY, drone, power-on
- test_env.py     FILTER env (amount +-, attack, decay), PITCH env (amount +-, decay),
                  GLIDE on arp notes, drones gliding on chord changes
- test_lfo.py     15 LFOs: PITCH / CUTOFF / AMP / PAN / SHAPE depth and rate, the six
                  waves, per-osc independence, LFO SYNC = TEMPO on the beat grid
- test_delay.py   per-osc delays: echo time per DIVISION / TEMPO, SEND, FEEDBACK,
                  master DELAY, WIDTH parallel vs ping-pong, TONE, WOBBLE
- test_screen.py  VIEW RINGS (arc hues, rests, moving dot, envelope height, drone
                  ring), PITCH (one hue per wave, following the note), WHEEL (chord
                  tones), SCOPE, on the rendered framebuffer
- test_prog.py    chord progression: every preset in major, minor and a chord key,
                  chord names / numerals, CHANGE lengths, changes on bar lines,
                  RESTART FREE / BAR / CHORD, the chord in the centre of the screen

Measurement lessons that cost time are noted in docs\ENGINE_PLAN.md
("Measurement traps").

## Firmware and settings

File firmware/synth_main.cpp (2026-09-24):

/**
 * Ammonite firmware: thin Daisy shell around ../core - the same core the PC
 * simulator runs. Hardware in, hardware out, zero synth logic here.
 *
 * SEED3: AGND (pin 20) is NOT bonded to DGND (pin 40) on the board. They
 *   MUST be jumpered together (datasheet v2.1 p.12, fig 1.5) or the ADC
 *   reference floats and every channel reads full scale with random dips.
 * Pots: pot i (panel order, see ENGINE_PLAN.md) -> ADC Ai. Pot 10 (knob
 *   11, PAGE) selects the page, pots 0..9 are that page's functions (on a
 *   column page one column per oscillator), pot 11 is VOLUME.
 *   A0..A10 = physical pins 22..32, A11 = physical pin 35.
 *   Every pot: one end -> pin 21 (+3V3A), other end -> pin 20 (AGND),
 *   wiper -> its A pin.
 * Display: VCC 38 (3V3D), GND 40, SCL 9 (D8), SDA 11 (D10), DC 7 (D6),
 *   CS 8 (D7), RST 6 (D5) - see gc9a01.h.
 * Audio: OUT L 18, OUT R 19, ground 20 (AGND).
 */
#include "daisy_seed.h"
#include "gc9a01.h"
#include "synth_core.h"

using namespace daisy;

// Bring-up aid: 1 = show raw ADC values of all 12 knobs instead of the synth
// screen (audio still runs). Set back to 0 for the real instrument.
#define DIAG_ADC 0
// 1 = ignore the synth and output a clean 220 Hz sine on both channels.
// If THIS sounds bad, the engine is innocent (codec / load / jack / DMA).
#define DIAG_TONE 0
// 1 = run the display SPI at 24.6 MHz (~38 ms per frame, ~26 fps) instead
// of 12.5 MHz (~74 ms, ~13.5 fps). Works on the hardware (user confirmed
// 2026-09-23, jumper wires). If a rewired panel shows garbage, set it to 0.
#define FAST_DISPLAY_SPI 1

#if DIAG_ADC
#include "canvas.h"
// SDRAM self-test region (1 MB) and audio-callback load meter (DWT cycles).
static uint32_t DSY_SDRAM_BSS sdram_test[1 << 18];
static uint32_t sdram_errors = 0;
static uint32_t cpu_last = 0, cpu_max = 0;
static float    cpu_avg  = 0.f;
static inline uint16_t* fb_or(uint16_t* fb) { return fb; }
#endif

// Which pots are physically wired. An unconnected ADC input floats and
// wanders, which the core reads as constant knob movement (the readout
// flashes between names). Unwired knobs are skipped and stay at the core's
// defaults. Set every entry to true once the panel is fully wired.
static const bool kPotWired[synth::kNumPots] = {
    true,  true,  true,  // knobs 1-3   page functions
    true,  true,  true,  // knobs 4-6   page functions
    true,  true,  true,  // knobs 7-9   page functions
    true,  true,  true,  // knob 10 function / sub-page, 11 PAGE, 12 VOLUME
};

// Pots that read backwards because of how they are mounted (the bottom
// rows are upside down in the panel). true = firmware inverts the reading.
// If any other knob turns the wrong way, flip its entry here; no rewiring.
static const bool kPotInvert[synth::kNumPots] = {
    false, false, false, // 1-3   (top row)
    true,  true,  true,  // 4-6   (bottom row)
    false, false, false, // 7-9   (top row)
    true,  true,  true,  // 10-12 (bottom row)
};

DaisySeed hw;
GC9A01    lcd;

// NOT in DMA_BUFFER_MEM_SECTION. That section is the start of RAM_D2, and
// only its first 32 KB are non-cacheable (libDaisy MPU region 0). A 115 KB
// framebuffer placed there pushed libDaisy's audio DMA buffers into
// cacheable memory, so the codec played stale cache garbage (2026-09-21).
// The display driver uses blocking SPI, so plain RAM is fine.
static uint16_t framebuf[GC9A01::W * GC9A01::H];

// Big DSP buffers live in SDRAM (they overflow main RAM); the core only
// ever sees them through the Buffers struct.
static synth::DelayLineT DSY_SDRAM_BSS delayL[synth::kOscs]; // one stereo delay per osc
static synth::DelayLineT DSY_SDRAM_BSS delayR[synth::kOscs];
static daisysp::ReverbSc DSY_SDRAM_BSS reverb;
static synth::PreLineT   DSY_SDRAM_BSS preL, preR;

void AudioCallback(AudioHandle::InterleavingInputBuffer  in,
                   AudioHandle::InterleavingOutputBuffer out,
                   size_t                                size)
{
#if DIAG_ADC
    uint32_t t0 = DWT->CYCCNT;
#endif
#if DIAG_TONE
    static float ph = 0.f;
    for(size_t n = 0; n < size; n += 2)
    {
        float s = 0.05f * sinf(ph); // -26 dBFS: safe to probe with an ADC pin
        ph += 6.2831853f * 220.f / 48000.f;
        if(ph > 6.2831853f)
            ph -= 6.2831853f;
        out[n]     = s;
        out[n + 1] = s;
    }
#else
    synth::ProcessAudio(out, size / 2); // core writes interleaved stereo
#endif
#if DIAG_ADC
    uint32_t dt = DWT->CYCCNT - t0;
    cpu_last    = dt;
    if(dt > cpu_max)
        cpu_max = dt;
    cpu_avg += 0.02f * ((float)dt - cpu_avg);
#endif
}

int main(void)
{
    hw.Configure();
    hw.Init();
    hw.SetAudioBlockSize(48);

#if DIAG_ADC
    // Cycle counter for the load meter.
    CoreDebug->DEMCR |= CoreDebug_DEMCR_TRCENA_Msk;
    DWT->CYCCNT = 0;
    DWT->CTRL |= DWT_CTRL_CYCCNTENA_Msk;
    // SDRAM: write a pattern, wait (refresh), read it back.
    for(uint32_t i = 0; i < (1u << 18); i++)
        sdram_test[i] = (i * 2654435761u) ^ 0xA5A5A5A5u;
    System::Delay(200);
    for(uint32_t i = 0; i < (1u << 18); i++)
        if(sdram_test[i] != ((i * 2654435761u) ^ 0xA5A5A5A5u))
            sdram_errors++;
#endif

    // 12 pots, pot i -> ADC channel Ai (panel order).
    const Pin kPotPins[synth::kNumPots]
        = {seed::A0, seed::A1, seed::A2, seed::A3, seed::A4,  seed::A5,
           seed::A6, seed::A7, seed::A8, seed::A9, seed::A10, seed::A11};
    // Long sampling time: the default 8.5 cycles is far too short for a
    // pot's source impedance and lets channels smear into each other.
    AdcChannelConfig adc_cfg[synth::kNumPots];
    for(int i = 0; i < synth::kNumPots; i++)
        adc_cfg[i].InitSingle(kPotPins[i],
                              AdcChannelConfig::SPEED_387CYCLES_5);
    hw.adc.Init(adc_cfg, synth::kNumPots);
    hw.adc.Start();

#if DIAG_ADC
    // Self-test with no wiring: the Seed's own DAC drives A8 (DAC1_OUT1,
    // pin 30, knob 9) to 25 % and A7 (DAC1_OUT2, pin 29, knob 8) to 75 %.
    // A working ADC must show ~25 on entry 9 and ~75 on entry 8.
    DacHandle::Config dac_cfg;
    dac_cfg.bitdepth   = DacHandle::BitDepth::BITS_12;
    dac_cfg.buff_state = DacHandle::BufferState::ENABLED;
    dac_cfg.mode       = DacHandle::Mode::POLLING;
    dac_cfg.chn        = DacHandle::Channel::BOTH;
    hw.dac.Init(dac_cfg);
    hw.dac.WriteValue(DacHandle::Channel::ONE, 1024); // 25 % -> A8
    hw.dac.WriteValue(DacHandle::Channel::TWO, 3072); // 75 % -> A7
#endif

#if FAST_DISPLAY_SPI
    // SPI1 normally runs off PLL2P (25 MHz -> 12.5 MHz SCK at PS_2, the
    // fastest prescaler). PLL3P is already running at 49.15 MHz for the
    // audio codec, so pointing the SPI1/2/3 kernel-clock mux at it doubles
    // the SCK. Only the mux register is touched: HAL_RCCEx_PeriphCLKConfig
    // would reprogram PLL3 itself and could stop the audio.
    __HAL_RCC_SPI123_CONFIG(RCC_SPI123CLKSOURCE_PLL3);
#endif
    GC9A01::Config cfg;
    lcd.Init(cfg, framebuf);

    synth::Buffers buffers;
    for(int o = 0; o < synth::kOscs; o++)
    {
        buffers.delayL[o] = &delayL[o];
        buffers.delayR[o] = &delayR[o];
    }
    buffers.reverb = &reverb;
    buffers.preL   = &preL;
    buffers.preR   = &preR;
    synth::Init(hw.AudioSampleRate(), buffers); // core sets knob defaults

    hw.StartAudio(AudioCallback);

    uint32_t frame = 0;
    for(;;)
    {
        for(int i = 0; i < synth::kNumPots; i++)
        {
            if(!kPotWired[i])
                continue;
            float v = hw.adc.GetFloat(i);
            synth::SetPot(i, kPotInvert[i] ? 1.f - v : v);
        }
#if DIAG_ADC
        synth::RenderDiagnostics(framebuf);
        {
            // Audio block budget: 48 frames * 10000 cycles = 480000 cycles.
            char     line[16];
            int      avg = (int)(cpu_avg / 4800.f);
            int      mx  = (int)(cpu_max / 4800);
            uint16_t ok  = synthui::Color(60, 230, 120);
            uint16_t bad = synthui::Color(255, 70, 70);
            if(sdram_errors == 0)
                synthui::DrawTextCentered(fb_or(framebuf), "SDRAM OK", 120, 208, 2, ok);
            else
                synthui::DrawTextCentered(fb_or(framebuf), "SDRAM BAD", 120, 208, 2, bad);
            int n = 0;
            const char* p = "CPU ";
            while(*p) line[n++] = *p++;
            if(avg >= 100) line[n++] = '0' + (avg / 100) % 10;
            if(avg >= 10) line[n++] = '0' + (avg / 10) % 10;
            line[n++] = '0' + avg % 10;
            line[n++] = ' ';
            if(mx >= 100) line[n++] = '0' + (mx / 100) % 10;
            if(mx >= 10) line[n++] = '0' + (mx / 10) % 10;
            line[n++] = '0' + mx % 10;
            line[n] = 0;
            synthui::DrawTextCentered(fb_or(framebuf), line, 120, 226, 2,
                                      (mx < 90) ? ok : bad);
        }
#else
        synth::RenderScreen(framebuf);
#endif
        lcd.Update();
        hw.SetLed((frame++ / 6) & 1);
    }
}

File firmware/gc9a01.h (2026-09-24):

#pragma once
/**
 * Minimal GC9A01 (240x240 round TFT) driver for libDaisy.
 *
 * 4-wire SPI, RGB565, full-frame buffer. Two transports on the same pins:
 *   - HARD: STM32 SPI1 via libDaisy SpiHandle, 12.5 MHz (default for frames)
 *   - SOFT: bit-banged GPIO, ~700 kHz (used for init; also supports
 *           reading registers back from the panel over SDA)
 * Written for the GoldenMorning GMT128-02 7-pin module
 * (VCC GND SCL SDA DC CS RST, backlight hard-wired on).
 * Verified working on Daisy Seed3, 2026-09-05.
 *
 * Protocol rules that matter (each one cost a debugging round):
 *   - CS must stay low from the RAMWR command through the last pixel byte.
 *   - Bit-banged clocks need real pauses; flat-out GPIO toggling is too fast.
 *   - After a HAL SPI transfer, wait a few us before moving DC or CS.
 */
#include <initializer_list>
#include "daisy_seed.h"

namespace daisy
{
class GC9A01
{
  public:
    static constexpr int W = 240;
    static constexpr int H = 240;

    enum class Transport
    {
        SOFT,
        HARD
    };

    struct Config
    {
        SpiHandle::Config spi;
        Pin               sclk, mosi, dc, reset, cs;

        Config()
        {
            sclk  = seed::D8;  // PG11 (SPI1 SCK)
            mosi  = seed::D10; // PB5  (SPI1 MOSI)
            cs    = seed::D7;  // PG10, driven as plain GPIO
            dc    = seed::D6;  // PC12
            reset = seed::D5;  // PD2

            spi.periph         = SpiHandle::Config::Peripheral::SPI_1;
            spi.mode           = SpiHandle::Config::Mode::MASTER;
            spi.direction      = SpiHandle::Config::Direction::TWO_LINES_TX_ONLY;
            spi.datasize       = 8;
            spi.clock_polarity = SpiHandle::Config::ClockPolarity::LOW;
            spi.clock_phase    = SpiHandle::Config::ClockPhase::ONE_EDGE;
            spi.nss            = SpiHandle::Config::NSS::SOFT;
            // SPI1 kernel clock on Daisy is 25 MHz (PLL2P). PS_2 -> 12.5 MHz
            // SCK, verified clean on jumper wires. synth_main.cpp's
            // FAST_DISPLAY_SPI switches the kernel clock to PLL3P
            // (49.15 MHz) -> 24.6 MHz SCK.
            spi.baud_prescaler  = SpiHandle::Config::BaudPrescaler::PS_2;
            spi.pin_config.sclk = sclk;
            spi.pin_config.miso = Pin(PORTX, 0);
            spi.pin_config.mosi = mosi;
            spi.pin_config.nss  = Pin(PORTX, 0);
        }
    };

    /** Pack r,g,b (0..255) into RGB565, already byte-swapped for the panel. */
    static constexpr uint16_t Color(uint8_t r, uint8_t g, uint8_t b)
    {
        uint16_t c = (uint16_t)((r & 0xF8) << 8 | (g & 0xFC) << 3 | b >> 3);
        return (uint16_t)((c >> 8) | (c << 8));
    }

    /** fb must hold W*H uint16_t.
     *  The init sequence always goes out on the slow bit-banged transport
     *  (a few ms, proven on real hardware); frames then use `t`. */
    void Init(const Config& cfg, uint16_t* fb, Transport t = Transport::HARD)
    {
        cfg_ = cfg;
        fb_  = fb;
        dc_.Init(cfg.dc, GPIO::Mode::OUTPUT);
        rst_.Init(cfg.reset, GPIO::Mode::OUTPUT);
        cs_.Init(cfg.cs, GPIO::Mode::OUTPUT);
        cs_.Write(1);
        dc_.Write(1);
        SetTransport(Transport::SOFT);
        Reinit();
        SetTransport(t);
    }

    /** Hardware reset + full init sequence on the current transport. */
    void Reinit()
    {
        // Hardware reset
        rst_.Write(1);
        System::Delay(5);
        rst_.Write(0);
        System::Delay(20);
        rst_.Write(1);
        System::Delay(120);

        // Init sequence (vendor recommended, same as Adafruit/lcdwiki).
        Cmd(0xEF);
        Cmd(0xEB, {0x14});
        Cmd(0xFE);
        Cmd(0xEF);
        Cmd(0xEB, {0x14});
        Cmd(0x84, {0x40});
        Cmd(0x85, {0xFF});
        Cmd(0x86, {0xFF});
        Cmd(0x87, {0xFF});
        Cmd(0x88, {0x0A});
        Cmd(0x89, {0x21});
        Cmd(0x8A, {0x00});
        Cmd(0x8B, {0x80});
        Cmd(0x8C, {0x01});
        Cmd(0x8D, {0x01});
        Cmd(0x8E, {0xFF});
        Cmd(0x8F, {0xFF});
        Cmd(0xB6, {0x00, 0x00});
        Cmd(0x36, {0x48}); // MADCTL: BGR order, pins-at-bottom orientation
        Cmd(0x3A, {0x05}); // COLMOD: 16 bpp
        Cmd(0x90, {0x08, 0x08, 0x08, 0x08});
        Cmd(0xBD, {0x06});
        Cmd(0xBC, {0x00});
        Cmd(0xFF, {0x60, 0x01, 0x04});
        Cmd(0xC3, {0x13});
        Cmd(0xC4, {0x13});
        Cmd(0xC9, {0x22});
        Cmd(0xBE, {0x11});
        Cmd(0xE1, {0x10, 0x0E});
        Cmd(0xDF, {0x21, 0x0C, 0x02});
        Cmd(0xF0, {0x45, 0x09, 0x08, 0x08, 0x26, 0x2A});
        Cmd(0xF1, {0x43, 0x70, 0x72, 0x36, 0x37, 0x6F});
        Cmd(0xF2, {0x45, 0x09, 0x08, 0x08, 0x26, 0x2A});
        Cmd(0xF3, {0x43, 0x70, 0x72, 0x36, 0x37, 0x6F});
        Cmd(0xED, {0x1B, 0x0B});
        Cmd(0xAE, {0x77});
        Cmd(0xCD, {0x63});
        Cmd(0x70, {0x07, 0x07, 0x04, 0x0E, 0x0F, 0x09, 0x07, 0x08, 0x03});
        Cmd(0xE8, {0x34});
        Cmd(0x62,
            {0x18, 0x0D, 0x71, 0xED, 0x70, 0x70, 0x18, 0x0F, 0x71, 0xEF, 0x70, 0x70});
        Cmd(0x63,
            {0x18, 0x11, 0x71, 0xF1, 0x70, 0x70, 0x18, 0x13, 0x71, 0xF3, 0x70, 0x70});
        Cmd(0x64, {0x28, 0x29, 0xF1, 0x01, 0xF1, 0x00, 0x07});
        Cmd(0x66, {0x3C, 0x00, 0xCD, 0x67, 0x45, 0x45, 0x10, 0x00, 0x00, 0x00});
        Cmd(0x67, {0x00, 0x3C, 0x00, 0x00, 0x00, 0x01, 0x54, 0x10, 0x32, 0x98});
        Cmd(0x74, {0x10, 0x85, 0x80, 0x00, 0x00, 0x4E, 0x00});
        Cmd(0x98, {0x3E, 0x07});
        Cmd(0x35); // tearing effect line on
        Cmd(0x21); // display inversion on (this panel needs it for true colours)
        Cmd(0x11); // sleep out
        System::Delay(120);
        Cmd(0x29); // display on
        System::Delay(20);
    }

    /** 3-wire mode: DC is sent as a 9th bit per byte (SOFT transport only). */
    void SetNineBit(bool on) { nine_bit_ = on; }

    /** Send a bare command byte (no parameters). */
    void Command(uint8_t c) { Cmd(c); }

    /** Drive the DC line directly, for probing with a meter. */
    void DebugDc(bool v) { dc_.Write(v); dc_state_ = v; }
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

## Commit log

2026-09-24 Ammonite: first public version
    A three-voice arpeggiator synthesizer on the Daisy Seed: the portable
    engine (core/), the Daisy firmware shell, the PC simulator, 193 headless
    tests, the owner's manual, the v1 enclosure STLs and wiring, and README
    media rendered from the engine. libDaisy and DaisySP are pinned submodules.
    [back_panel.stl, back_rail.stl, bottom_panel.stl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]
2026-09-24 README: photo of the assembled front panel
2026-09-24 docs: VST plan and handoff
    What exists, the environment (MSVC Build Tools, DAWs to test in), the
    engine's single-instance state, and the plan: instance refactor, host
    tempo / sample rate / parameters / state, a DPF plugin (VST3 + CLAP),
    build and ship. Open decisions to settle with the user first.
2026-09-24 Plugin engine: a multi-instance copy of core/, bit-identical to v1.0
    The VST gets its own engine in plugin/engine/, so the hardware project
    (core/, firmware/, sim/, tests/) stays exactly at v1.0. The copy moves
    every mutable static into Engine::Impl; class Engine forwards the old API.
    plugin\plugin.ps1 test builds core_ref.dll (core/) and ammonite_engine.dll
    with the simulator's compiler and flags, runs the hardware test suite
    against the copy, and plugin/tests/test_engine_copy.py: 40 random
    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
2026-09-24 Plugin engine: 44.1-192 kHz, host parameter API
    - Own copy of DaisySP-LGPL's ReverbSc (LGPL notice kept) with a buffer for
    192 kHz and a bounds check that covers the last delay line; above 192 kHz
    the engine runs without the reverb instead of crashing.
    - Delay and pre-delay lines hold the hardware's longest times at 192 kHz;
    the delay-time limit itself is unchanged (bit-identical at 48 kHz).
    - Engine: NumFuncs / FuncName / FuncPerOsc / FuncSteps / FuncDefault /
    FuncPlace / FuncStepText for a host, SetParam (smoothed like a pot),
    GetParam, ReverbOk.
    - plugin/tests/test_rates.py: pitch, reverb tail and delay time equal from
    44.1 to 192 kHz, 384 kHz runs without reverb, Init 48 -> 1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
2026-09-24 Plugin shell: Ammonite as VST3 + CLAP (DPF), no UI yet
    - DPF as a submodule in plugin/lib/DPF; plugin/src: the IDs as decided
    (GSNautilus / Ammonite, com.gsnautilus.ammonite, GSNa / Ammo), one engine
    per instance, 168 automatable parameters (every function and oscillator,
    stable IDs), flush-to-zero, engine re-initialised with the host's values
    on a sample-rate change.
    - plugin\plugin.ps1 build (MSVC + CMake + Ninja, static CRT) and install
    (admin: the system VST3 and CLAP folders).
    - plugin/tests/test_clap.py: a small ctypes CLAP host drives the built
    Ammonite.clap (parameters, 48 / 96 / 192 kHz, automation, two instances,
    state save / load).
    - canvas.h (copy): noinline for MSV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
    [DistrhoPluginInfo.h]
2026-09-24 Plugin: the panel UI
    - plugin/src/AmmoniteUI.cpp (DPF, NanoVG): the simulator's panel, 12
    knobs around the round screen; the screen is the engine's RenderScreen
    every ~38 ms, the readouts the engine's value text; knobs edit host
    parameters with begin / end gestures; knob 11 pages, knob 10 sections;
    a SYNC button. Resizable, aspect kept.
    - Engine: SetPanelPage / ShowPot / GetSlotFunc for a mouse panel; TEMPO
    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
2026-09-24 Plugin UI: less lag on the screen while turning knobs
    - Screen frames are also driven from mouse input: Windows holds timer
    messages back while mouse moves keep coming, so during a drag the idle
    timer alone let the screen stall.
    - A knob also writes its value straight into the engine (atomic), so the
    sound and the screen readout answer at once instead of after the host
    has passed the change to the audio thread at its next buffer.
2026-09-24 README: the enclosure model image instead of the STL render
2026-10-18 Site: the Mini page, with the 0.1.0 download, and a live Mini card
    mini/index.html: what Mini is and how it relates to Desktop, four screenshots
    from the tablet (Night groove: the channels, the Conductor, a channel opened,
    Modulation; WebP in mini/img), the requirements (Android 13+, arm64, a tablet;
    tested on a Galaxy Tab S6 Lite 2024, Android 16), the download button to the
    v0.1.0 release, sideloading steps, and links to the repo, Desktop and the
    family page. The family page's Mini card gets a picture (the Conductor's
    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
2026-10-18 Site: the Ammonite Desktop page, and its picture on the family card
    desktop/index.html replaces the stub: a silent stage loop recorded from
    the running standalone, the download (release desktop-v0.1.0), what it
    is, five screenshots, install steps (standalone, VST3, CLAP) with the
    SmartScreen note, and the requirements (Windows 10/11 x64, WebView2
    Runtime, no MIDI). Pictures in desktop/img, captured from the real host.
    The family page's Desktop card gets the stage picture, and its text no
    longer promises FX channels (not built yet).
